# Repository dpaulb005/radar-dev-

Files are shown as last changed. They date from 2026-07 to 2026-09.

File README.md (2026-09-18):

# radar-dev — a horn-fed 2.4 GHz FMCW radar that tracks a small drone

A frequency-modulated continuous-wave radar in the MIT "coffee-can" tradition,
fed by pyramidal horns cut from copper sheet, that finds a 25 g quadcopter at
3–10 m indoors by its reflection alone. The drone carries no beacon and no
transponder: it is a target.

One transmit horn, one receive horn. It measures **range and radial velocity**.

```
 ESP32 steps an ADF4351 PLL 2400 → 2483.5 MHz in 64 steps / 6.4 ms
   → 3 dB pad → PA → splitter ─┬─► TX horn ─── echo off the drone ──► RX horn
                               └─► mixer LO ◄──────── LNA ◄── band-pass ◄──┘
 mixer IF = beat tone, pitch ∝ range (870 Hz at 10 m)
   → video amp (TL072, 61 dB) → USB audio interface
   → laptop: range FFT · Doppler FFT · CFAR → Kalman tracker → console
```

| | |
|---|---|
| sweep | 2400–2483.5 MHz (83.5 MHz), 6.4 ms up-chirp, 7.4 ms PRI |
| range cell | 1.80 m, 0.04 m mean accuracy on the stepped waveform |
| velocity | 0.13 m/s resolution, unambiguous to ±4.15 m/s |
| antenna | optimum pyramidal horn, 264 × 193 mm aperture, 13.4 dBi, ~34° × 36° beam |
| drone echo at 10 m | −77 dBm (0.01 m² RCS), 72 dB above the leakage-limited floor after 64 chirps |

## What is here

This branch holds the design deliverables only. Everything used to produce them
(firmware, signal processing, the model generators, the full design notes) is
on the [`dev`](https://github.com/dpaulb005/radar-dev-/tree/dev) branch.

| | what | status |
|---|---|---|
| [`BOM_Radar_Build.xlsx`](BOM_Radar_Build.xlsx) | bill of materials: every part, its price and where to buy it | priced Sept 2026 |
| [`antenna/`](antenna/) | the horn: design dimensions and the HFSS simulation results | **simulation in progress**, results and the LaTeX report land in `antenna/results/` |
| [`3d/`](3d/) | 3D models of the radar bench and the drone: open `radar-bench.html` or `drone.html` in a browser, plus rendered views | done |
| [`breadboard/`](breadboard/) | the baseband board: schematics, hole-by-hole wiring, 17 build steps, the pick list, and the Multisim files for each block | **bench test pending**, Multisim circuits to be added |

## Where it stands

- **Designed and documented:** the RF chain, the horn, the video amplifier,
  the frame, the drone's 915 MHz control link.
- **Parts ordered:** everything in the bill of materials is on its way.
- **Simulation in progress:** the horn in HFSS (probe match, gain, patterns)
  and each breadboard block in Multisim. The ngspice reference numbers each
  block should reproduce are in `breadboard/multisim/README.md`.
- **Next, while the RF parts ship:** cut the three horns and wire the
  breadboard.
- **Not built:** anything RF. Nothing here has been on a bench yet.

Azimuth from a second receiver is designed and tested in software but not built;
the BOM lists what it would add so nothing gets bought twice.

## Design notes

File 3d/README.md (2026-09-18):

# 3d — the two models

Two self-contained Three.js pages. Open either in a browser (each loads
three.js from a CDN, so it needs an internet connection the first time).
Between them they draw every part in `BOM_Radar_Build.xlsx` as a real object.

| page | what it is |
|---|---|
| [`radar-bench.html`](radar-bench.html) | the radar: the three-horn frame, the RF chain, the 830-point breadboard wired hole by hole, the USB interface and laptop, the optional turntable, and the room with the drone 3 m out. A second button adds the azimuth upgrade, so the model can show what would change. |
| [`drone.html`](drone.html) | the target: a Seeed ESP-FLY with the 915 MHz receiver fitted, every part, every pad, every wire, and what each one weighs. |

Both share the same conventions: click a panel row and the camera flies to the
part and it pulses; hover any object for its name; hover a pin or pad for its
net; click an object and its panel row scrolls into view.

## Rendered views

Still images from each model, in [`renders/`](renders/).

| [`renders/radar-bench/`](renders/radar-bench/) | |
|---|---|
| [`room.png`](renders/radar-bench/room.png) | the room, drone 3 m out |
| [`desk.png`](renders/radar-bench/desk.png) | the desk |
| [`bench.png`](renders/radar-bench/bench.png) | the bench and horn frame |
| [`plan.png`](renders/radar-bench/plan.png) | plan view |
| [`breadboard.png`](renders/radar-bench/breadboard.png) | the breadboard, wired |
| [`stage2.png`](renders/radar-bench/stage2.png) | with the azimuth upgrade |

| [`renders/drone/`](renders/drone/) | |
|---|---|
| [`overview.png`](renders/drone/overview.png) | the ESP-FLY as fitted |
| [`top.png`](renders/drone/top.png) | from above |
| [`underside.png`](renders/drone/underside.png) | from below |
| [`receiver.png`](renders/drone/receiver.png) | the 915 MHz receiver fitted |
| [`exploded.png`](renders/drone/exploded.png) | exploded |

The models are generated and geometry-checked by scripts on the `dev` branch
(`hardware/3d/`); edit there, not here.

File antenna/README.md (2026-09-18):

# antenna — the horn, and its HFSS simulation

Optimum pyramidal horn at 2.45 GHz on a WR-340 waveguide section with a coax
probe feed. Three are cut from copper sheet in one session: TX, RX, and a
spare for the azimuth upgrade.

## Design dimensions

Solved by `antenna/horn.py` on the `dev` branch; this is what the HFSS model
must reproduce before its output means anything.

| | |
|---|---|
| design frequency | 2.45 GHz (λ₀ = 122.4 mm) |
| feed guide a × b | 86.4 × 43.2 mm (WR-340) |
| TE10 cutoff | 1.735 GHz, single-mode to 3.47 GHz |
| guide wavelength λg | 173.3 mm |
| coax probe | ~29 mm long, 43 mm from the shorted back wall |
| aperture a1 (H-plane) | 263.8 mm |
| aperture b1 (E-plane) | 193.1 mm |
| axial flare length | 91.5 mm (pe = ph, geometry closes) |
| predicted gain | 13.4 dBi |
| aperture bound 4πA/λ² | 16.3 dBi |
| aperture efficiency | 51 % (textbook optimum) |
| beamwidths | ~34° E-plane, ~36° H-plane |

Accept the simulation if: gain 12.5–14 dBi at 2.45 GHz, S11 below −10 dB across
2400–2483.5 MHz after the probe sweep, beamwidths within a few degrees of the
above, and gain below the aperture bound. A converged solution of a wrong model
is still converged.

## Results

The HFSS output goes in [`results/`](results/), and the write-up is a LaTeX
report built from it once the measurements are in: S11 across the band, the
E- and H-plane cuts, the probe sweep, and the final table against the accept-if
line above. Until then the design numbers above are the only antenna data here.

The study notes the procedure was written from (an antenna-basics primer and
the twelve-step HFSS walkthrough for this horn) are on the `dev` branch under
[`antenna/hfss/`](https://github.com/dpaulb005/radar-dev-/tree/dev/antenna/hfss).

## What the solver is for

The gain and beamwidths have a closed form and the table above already has
them. What HFSS is genuinely for is the **probe match**, which does not: sweep
probe depth and backshort distance, and arrive at the bench already close.

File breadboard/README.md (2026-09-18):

# breadboard — the baseband board

Everything between the mixer's IF port and the USB audio interface, plus the
power entry and the ESP32 / ADF4351 harness, on one 830-point breadboard:
video amplifier, half-rail reference, 12 V input, sync divider.

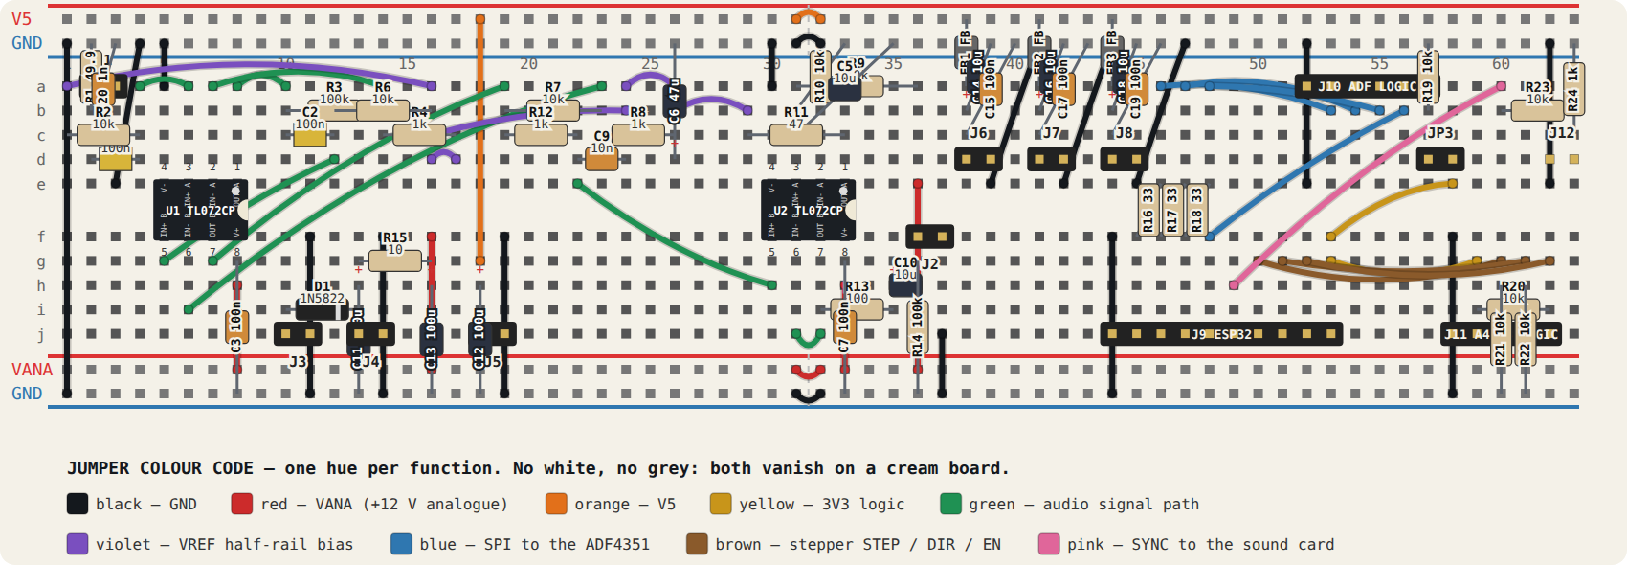
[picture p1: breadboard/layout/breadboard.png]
the finished board


| folder | what |
|---|---|
| [`schematics/`](schematics/) | three KiCad sheets and their PNGs: `radar_flow` (how everything connects, in signal order), `radar_breadboard` (the board at component level), `radar_multisim` (each test block drawn alone with its sources and expected readings) |
| [`layout/`](layout/) | the board: [`WIRING.md`](layout/WIRING.md) gives every part's lead → hole, every jumper and every net, verified against the schematic netlist; [`breadboard.html`](layout/breadboard.html) is the interactive version (hover or click any part, wire, net or hole) |
| [`assembly/`](assembly/) | [`ASSEMBLY.md`](assembly/ASSEMBLY.md): the build in 17 pictured steps, each ending with a check |
| [`parts/`](parts/) | [`PARTS.md`](parts/PARTS.md), the stockroom pick list (every value, how many, what may be substituted), and [`MODULES.md`](parts/MODULES.md), the pinouts of the TL072, ESP32, A4988, ADF4351 and the interface |
| [`multisim/`](multisim/) | the SPICE netlists for each block, ready for File ▸ Open in Multisim, with the reading each should give |

## Multisim status

The netlists in `multisim/import/` open directly in Multisim and each header
says which analysis to run and what number to expect. The saved Multisim
projects (`.ms14`) and the bench measurements go in `multisim/` beside them (the `.sub` black-box blocks for Route B are in `multisim/blocks/`)
once each block has been run.

| block | file | expect |
|---|---|---|
| 1 video amplifier | `import/01_video_amp.cir` | 54.5 dB at 1 kHz; 0.5 mVpk in → 0.27 Vpk out |
| 2 half-rail reference | `import/02_vref_bias.cir` | vref 5.58–5.70 V |
| 3 12 V input | `import/03_power_in.cir` | vana 11.58 V |
| 4 reverse polarity | `import/04_power_reverse.cir` | vprot −0.11 mV |
| 5 sync divider | `import/05_sync_div.cir` | sync 283 mV |
| 6 IF input network | `import/06_if_input.cir` | −6.7 dB at 417 Hz, −57.7 dB at 2.44 GHz |

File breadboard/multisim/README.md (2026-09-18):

# Multisim — the radar's baseband blocks, ready to open

Multisim cannot open a KiCad schematic, but it takes SPICE two ways
([NI: Importing a SPICE Netlist](https://knowledge.ni.com/KnowledgeArticleDetails?id=kA03q000000YG0ACAW&l=en-US)).
Pick by what you want on the sheet.

## Route A — File ▸ Open a netlist, get a drawn schematic  ← start here

`import/*.cir` are flat netlists written for this: **no `.control` block, no
B-sources, no `.include`, everything in one file.** (The ngspice decks they were
derived from live in `hardware/spice/` on the [`dev` branch](https://github.com/dpaulb005/radar-dev-/tree/dev/hardware/spice);
those contain `.control` blocks Multisim rejects, so they are not here.)

1. **File ▸ Open**, set the file-type dropdown to **SPICE netlist files
   (\*.cir)**, pick the file. Multisim converts the netlist into a drawn
   schematic; passives arrive as virtual parts.
2. Multisim ignores the `.ac` / `.tran` / `.op` lines at the bottom. Set the
   analysis yourself in **Simulate ▸ Analyses and Simulation** — each file's
   header comment says which analysis and what number to expect.
3. Probe with **Place ▸ Probe** or a virtual instrument, then **Run**.

| file | what it is | run | expect |
|---|---|---|---|
| `import/01_video_amp.cir` | the whole video amp, full gain, 0.5 mVpk 1 kHz in | AC 1 Hz–100 kHz; Transient 40–60 ms | **54.5 dB** at 1 kHz, 48.7 at 159 Hz, 50.6 at 15.9 kHz; **0.27 Vpk** at `audio` |
| `import/02_vref_bias.cir` | buffered half rail, 150 kHz ripple on VANA | DC Operating Point | `vdiv` **5.70 V**, `vref` **5.58 V** |
| `import/03_power_in.cir` | 12 V, D1, R15/C13 | DC OP; Transient 200–300 µs | `vprot` **11.68 V**, `vana` **11.58 V** |
| `import/04_power_reverse.cir` | −12 V applied | DC OP | `vprot` **−0.11 mV** |
| `import/05_sync_div.cir` | GPIO25 → 10k/1k → sound card | Transient 0–60 ms | `sync` **283 mV**, `sc` +274 mV falling to **−100 mV** on retrace |
| `import/06_if_input.cir` | 49.9 Ω + 1 nF at the mixer IF | AC 10 Hz–10 GHz | **−6.7 dB** at 417 Hz, **−57.7 dB** at 2.44 GHz |

Every one of those numbers was produced by running the file itself in ngspice.

The op-amp in files 01 and 02 is a generic macro (Aol 100 dB, GBW 3 MHz,
diode output clamps) defined at the top of the file. For a better answer,
delete that subcircuit after import and drop in Multisim's own **TL072CP**
from Place ▸ Component ▸ Group **Analog** ▸ Family **OPAMP**.

## Route B — Arbitrary SPICE Block, one black box on your own sheet (the `.sub` files in `blocks/`)

Use this when you want Multisim's sources and instruments around a block, or
for `fmcw_beat.sub`, which needs a real VCO in front of it and so cannot be a
plain netlist. The `.sub` files are plain SPICE 3 (R, C, D, E incl. POLY, T,
V, X) — no B-sources, no ngspice syntax — and each has been run through
ngspice via the `_h_*.cir` harnesses to prove it parses and gives the
test-card numbers.

| file | subcircuit · pins | stands for |
|---|---|---|
| `blocks/opamp_tl072.sub` | `TL072X inp inn vcc vee out` | generic TL072 (Aol 100 dB, GBW 3 MHz, clamps 1.5 V inside the rails). Used by the two blocks below; in Multisim you can instead build the amp from library TL072CPs — see the KiCad sheet |
| `blocks/video_amp.sub` | `VIDEO_AMP if audio vana vref gnd` | test card 1 — the whole video amplifier, full gain (R4 1k, R7 10k) |
| `blocks/vref_bias.sub` | `VREF_BIAS vana vref gnd` | test card 2 |
| `blocks/power_in.sub` | `POWER_IN vin vprot vana gnd` | test card 3 |
| `blocks/sync_div.sub` | `SYNC_DIV gpio sync sc gnd` | test card 4, includes the sound card's coupling |
| `blocks/fmcw_beat.sub` | `FMCW_BEAT tx leak_en beat gnd` | test card 6 — delay lines, gated leakage, POLY multiplier (the mixer), the amp's filters |

### Placing a block

1. Place › Component › Group **Basic** › Family **BASIC_VIRTUAL** (older
   versions: **Misc**) › **ARBITRARY_SPICE_BLOCK**.
2. Double-click it › **Value** tab › paste the contents of the `.sub` file
   (for `video_amp.sub` and `vref_bias.sub` paste `opamp_tl072.sub` first,
   then the block — the `.include` line does not resolve inside Multisim, so
   delete it and paste the op-amp subcircuit above the block's `.subckt`).
3. Set the block's **pin names** to the `.subckt` pin list, in order.
4. Wire the external parts below to those pins.

### Per block: what to add outside, what to run, what you should read

#### 1 · VIDEO_AMP
- **Outside:** `AC_VOLTAGE` V_IF → **50 Ω resistor** → `if`. `DC_POWER` 11.4 V → `vana`; `DC_POWER` 5.7 V → `vref` (or the VREF_BIAS block's output). 10 kΩ from `audio` to ground (sound-card load). Ground → `gnd`.
- **Run:** AC Analysis 1 Hz – 100 kHz, output `V(audio)`; Transient 40–60 ms with V_IF = **0.5 mVpk 1 kHz**.
- **Read:** 54.5 dB at 1 kHz, ~48.7 dB at 159 Hz (−6), ~50.7 dB at 15.9 kHz (−4). Transient: 0.5 mVpk → **~0.27 Vpk** at `audio`. 10 mVpk clips at ±4.2 V — that is the full-gain block; for the first-power-up gain edit `R4 am vref 4.7k` and `R7 bout bm 0.001` in the pasted text (then 10 mVpk → 107 mVpk).
- **Radar test:** two AC_VOLTAGE in series: 8 mVpk 12.5 Hz + 40 µVpk 417 Hz → Fourier on `audio`: ~27 mV at 12.5 Hz, ~19 mV at 417 Hz.

#### 2 · VREF_BIAS
- **Outside:** `DC_POWER` 11.4 V → `vana`; 2.2 kΩ from `vref` to ground.
- **Run:** DC Operating Point; then AC/transient with 100 mVpk 150 kHz added to `vana`.
- **Read:** `vref` = **5.58–5.70 V** (5.58 with the generic op-amp's 100 Ω output; 5.70 with TL072CP), ripple < 1 µV.

#### 3 · POWER_IN
- **Outside:** `DC_POWER` 12 V → `vin`; 60 Ω from `vprot` to ground (the buck's load), 1.1 kΩ from `vana` to ground (the op-amps).
- **Run:** DC OP; transient with 100 mVpk 150 kHz on `vin`; DC OP again with **−12 V**.
- **Read:** `vprot` **11.68 V**, `vana` **11.58 V**; ripple on `vana` ~4 mVpp; reversed: `vprot` ≈ −0.1 mV.

#### 4 · SYNC_DIV
- **Outside:** `PULSE_VOLTAGE` 0 → 3.3 V, pulse width 6.4 ms, period 7.4 ms, 10 ns edges → `gpio`.
- **Run:** Transient 0–60 ms, probe `sync` and `sc`.
- **Read:** `sync` **283 mV** high / 0 low; `sc` **+201 mV** plateau that droops, **−100 mV** retrace pulse. (That is what the laptop sees; the software detects edges, not levels.)

#### 5 · FMCW_BEAT — the radar
- **Outside:** `PIECEWISE_LINEAR_VOLTAGE` (0 V at 0, 1 V at 6.4 ms, repeat) → `VOLTAGE_CONTROLLED_SINE_WAVE` (0 V → 1 MHz, 1 V → 5 MHz, 1 Vpk) → `tx`. `DC_POWER` **0 V** → `leak_en` (1 V to switch the leakage path on).
- **Run:** Transient, TMAX **10 ns**, stop 12.8 ms. Fourier Analysis on `beat` over the **second chirp** (6.72–12.8 ms), Hanning.
- **Read:** peak at **≈ 415 Hz, ~3 mV**. Change T1's `TD=667n` to `333n` → 208 Hz; `1.33u` → 833 Hz. `leak_en` = 1 V: the 417 Hz line stays, the floor near DC rises — the reason the software subtracts chirp-to-chirp.
- Why it is scaled: the beat is `B × TD / T` and the carrier cancels. Real radar B = 40 MHz, TD = 66.7 ns at 10 m; here B = 4 MHz, TD = 667 ns — same 417 Hz, and Multisim can step at 10 ns instead of 20 ps.

## Not importable, by nature
Everything to the right of the mixer's IF port — ADF4351, SPF5189Z amplifiers, splitter, mixer at 2.44 GHz, the horns. No models exist at that frequency in Multisim; those stages are measured on the bench (`docs/radar-hardware.md` on the `dev` branch, checkpoints 7–8).

## Reproduce the reference numbers
```
cd breadboard/multisim
ngspice -b import/03_power_in.cir    # the import files run as-is in ngspice too
```
The `_h_*.cir` harnesses that wrap each `.sub` with its sources are on the
[`dev` branch](https://github.com/dpaulb005/radar-dev-/tree/dev/hardware/spice/multisim).

## If Multisim refuses a file
- **"Unrecognized command" / it stops at a line** — you opened an ngspice deck
  (from the `dev` branch) rather than one of the files in `import/`. They contain `.control`.
- **Nothing appears after File ▸ Open** — the file-type dropdown was still on
  Multisim files; it must say SPICE netlist (\*.cir).
- **The subcircuit did not come through** — paste it into an Arbitrary SPICE
  Block instead (route B), or rebuild that stage from library parts.

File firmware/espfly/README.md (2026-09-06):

# firmware/espfly — what runs on the ESP-FLY

**Current plan: nothing from here.** The drone is flown from the phone on
the stock ESP-Drone firmware (AP on channel 1) — see `docs/drone-software.md`.

This directory is the **fallback**: esp-fc configuration for a 915 MHz
ELRS/CRSF receiver, if the phone link and the radar turn out not to coexist:

- `espfly-915.cli` — the esp-fc CLI settings (receiver pins, serial RX,
  failsafe). Paste into the Configurator's CLI tab.

Step-by-step: [`../../docs/drone-hardware.md`](../../docs/drone-hardware.md)
(receiver swap, antenna, radio) and
[`../../docs/drone-software.md`](../../docs/drone-software.md) (ELRS flash,
EdgeTX model, esp-fc Ports/Receiver/Modes, failsafe test, first flights).

Building esp-fc yourself (only if you are not using the ESP-FLY's supplied
binary): PlatformIO, env `esp32s3` (`pio run -e esp32s3 -t upload`). The
receiver-related changes are all runtime settings; no source edits.

Not here any more, on purpose: `drone_beacon`, MAC filtering, the AP/FTM
patches — those belonged to the passive RF tracker.

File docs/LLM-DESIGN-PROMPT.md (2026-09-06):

# Design-prompt pack — horn-fed FMCW radar + phone-flown ESP-FLY

A set of prompts to hand to an LLM (or a design partner) to produce the
detailed engineering for this project. Every number below is fixed by the
work already done in this repo; the prompts ask the model to design *to*
them, not to re-derive or "improve" them.

**How to use.** Paste **§0 (shared context)** first, then one of the task
prompts §1–§5. Each task prompt is independent and ends with the deliverable
format it expects. Run §5 (band plan) and §1 (schematic) before §2 (PCB);
run §3 (antenna tests) any time after the horn geometry is accepted.

---

## §0 · Shared context — paste this before every task prompt

```text
You are the RF / systems engineer for a hobby-scale but rigorous project:
an MIT RES.LL-003 "coffee-can" FMCW radar rebuilt with custom pyramidal
horns, tracking a 25 g quadcopter (Seeed ESP-FLY: XIAO ESP32-S3, ESP-Drone
firmware, flown from a phone over the drone's own WiFi access point) at
3-10 m indoors. Range + Doppler first, azimuth by mechanically scanning the
horn pair, elevation later from a second stacked receive horn.

FIXED DECISIONS (design to these; do not reopen them):
- Radar architecture, in MIT's signal order:
    sweep generator -> 3 dB attenuator -> PA -> 2-way splitter
      -> (TX horn) and (mixer LO);
    RX horn -> LNA -> mixer RF; mixer IF -> video amp -> sound card.
- Sweep generator: ADF4351 PLL board (25 MHz TCXO) stepped over SPI by an
  ESP32, NOT an analog VCO (the MIT ZX95-2536C+ is non-catalog).
  64 steps x 100 us = 6.4 ms up-chirp, 1 ms retrace -> PRI 7.4 ms.
- Band: the drone's WiFi AP is on 802.11 channel 1 (2401-2423 MHz).
  Radar sweep 2440.0 -> 2480.0 MHz (40 MHz). The sweep never leaves
  2400-2480 MHz (the top 3.5 MHz of the US ISM band is left as an emission margin). 2360-2395 MHz is NOT usable (AMT/medical).
- Parts on hand / chosen: Mini-Circuits ZX05-43MH-S+ mixer (level 13),
  2x SPF5189Z LNA modules (PA role and LNA role), 800-2500 MHz 2-way SMA
  splitter, SMA 3 dB attenuator, Behringer UCA202 USB sound card
  (44.1 kHz, 16-bit, L = beat, R = sync), ESP32-WROOM-32 devkit,
  TL072 video amp on 12 V, NEMA-17 + A4988 turntable, 12 V 3 A supply
  with LM2596 5 V buck.
- Design levels at 2.44 GHz: ADF4351 +5 dBm -> att +2 -> PA +14 ->
  splitter +10.5 dBm to TX horn and +10.5 dBm to LO. TX horn 13.4 dBi
  -> +23 dBm EIRP. Drone RCS assumed 0.01 m^2 -> echo -74 dBm at 10 m
  at the RX horn, SNR 71 dB after 64-chirp integration. Beat frequency
  f_b = 2*B*R/(c*T_up) = 417 Hz at 10 m; IF band of interest 0-2.6 kHz;
  TX->RX leakage appears as a ~26 Hz tone ~40 dB above the drone echo.
- Horn (per horn, three built): optimum pyramidal horn on a WR-340 guide.
  Aperture 263.8 x 193.1 mm, throat 86.4 x 43.2 mm, flare 91.5 mm axial,
  guide section 115 mm, SMA probe through the broad wall 43.7 mm from
  the shorted back wall, probe 28 mm long. Predicted: 13.4 dBi, -3 dB
  beamwidths 34 deg (E) x 36 deg (H), pe == ph satisfied, 51 % aperture
  efficiency. 0.021" copper, soldered seams. TX and RX horns 290 mm
  centre-to-centre, E-plane (193 mm side) vertical on both.
- Scanning: 12 deg beam steps over ~100 deg, 64 chirps per dwell (0.47 s),
  amplitude-weighted centroid across beams -> 2.5 deg azimuth RMS.
  Stage 3: second RX horn 193 mm directly below the first (1.57 lambda,
  unambiguous +/-18.5 deg), second LNA + mixer + video channel, 4-input
  audio interface on one clock (Behringer UMC404HD).
- Drone: stock ESP-FLY hardware. ESP-Drone firmware rebuilt with
  CONFIG_WIFI_CHANNEL=1. The RadioMaster RP1 V2 (ELRS 2.4 GHz) receiver
  is REMOVED so no FHSS link hops through the sweep. No 5 GHz, no
  Bluetooth, no 915 MHz unless the coexistence test fails.
- Interference budget at the drone's receiver, 5 m, beam on it: radar
  -31 dBm raw, ~ -55 dBm after adjacent-channel rejection; phone signal
  ~ -35 dBm; SIR ~ 20 dB (802.11 needs 5-10 dB).
- Interference INTO the radar: the drone's AP (+20 dBm, always in the
  beam) reaches the LNA at -21 dBm at 5 m and the mixer at -9 dBm --
  ~8 dB from compression with WiFi peaks. Mitigations that are part of
  the design: drone AP power set to +8 dBm in firmware; a 2400-2500 MHz
  band-pass filter between RX horn and LNA (the horn and the SPF5189Z
  are wideband); the operator with the phone stands behind the horns.
- Processing on the laptop (Python, exists): sync-edge segmentation ->
  per-chirp range FFT (3.75 m cells, parabolic peak interpolation) ->
  Doppler FFT across chirps (axis from the measured PRI, +/-4.2 m/s) ->
  CA-CFAR (linear power, guard 4, train 6, 15 dB, peak-picked) ->
  beam centroid -> Kalman tracker -> web console.

HARD CONSTRAINTS:
- Never propose a sweep outside 2400-2483.5 MHz or overlapping 2401-2423.
- Never propose moving the phone link to 5 GHz/Bluetooth (the S3 cannot)
  or to the T8L radio (2.4 GHz only, no module bay).
- Keep every RF path 50 ohm; SMA everywhere; no bias-tee assumptions
  (the SPF5189Z and ADF4351 boards have their own 5 V pins).
- State every assumption you add, and mark which numbers are computed
  versus assumed. Where a value depends on a datasheet figure at
  2.4 GHz (SPF5189Z gain, mixer conversion loss), quote the figure and
  its source line.
- Prefer parts in stock at Mini-Circuits, Mouser, Digi-Key, LCSC, or Amazon
  in September 2026; say so per part.
```

---

## §1 · Task prompt — system design and full circuit diagram

```text
TASK: Produce the complete electrical design of the radar as built from
the coax modules in §0, ready for a person to wire on a plywood board and
a breadboard, and produce the circuit diagram.

Deliver, in this order:

1. BLOCK DIAGRAM with every signal level (dBm) at every port at 2.44 GHz,
   in MIT order. Include the ESP32's three control lines (SPI to the
   ADF4351, SYNC to the sound card's right channel, STEP/DIR/EN to the
   A4988). Show the two horns and the drone as the RF "load".

2. SCHEMATIC (text form, KiCad-importable if you can: a netlist or a
   KiCad 8 .kicad_sch S-expression; otherwise an unambiguous ASCII
   schematic per sheet) with these sheets:
   a. RF chain: SMA-to-SMA interconnects between modules, including
      the 2400-2500 MHz band-pass filter between the RX horn and the
      LNA, module DC
      feeds (5 V, 100 nF + 10 uF at each module), the 3 dB pad, the
      splitter, the mixer's LO/RF/IF ports labeled.
   b. Video amplifier: TL072 on a single 12 V rail with a 6 V mid-rail
      bias. Stage A non-inverting gain 101 with an input high-pass at
      160 Hz (100 nF / 10 k); stage B gain 11 with a second 160 Hz
      high-pass; then a 15.9 kHz RC low-pass (1 k / 10 nF) and a 10 uF
      AC-coupled output into the sound card's left channel. Justify each
      corner: the two high-passes are there to keep the ~26 Hz leakage
      tone from saturating the gain; the low-pass is anti-alias for
      44.1 kHz. State the leakage and drone-echo amplitudes at the
      output (targets: ~200 mV and ~20 mV) and show neither clips a
      line input.
   c. Sync: ESP32 GPIO25 -> 10 k series -> sound card right tip, 1 k to
      ground (0.3 V square wave, high during the up-chirp).
   d. Control: ESP32 devkit pinout (SCK 18, MOSI 23, LE 5, LD 19,
      SYNC 25, STEP 26, DIR 27, EN 14), A4988 with VMOT 12 V, 1/16
      microstep straps, VREF for ~0.8 A, 100 uF at VMOT.
   e. Power tree: 12 V 3 A input -> LM2596 5.0 V (ADF4351 board, both
      SPF5189Z modules, ESP32 VIN) ; 12 V direct to TL072 and A4988;
      star ground at a terminal block; note the stepper's wires must be
      routed away from the IF/breadboard side.

3. BILL OF MATERIALS for the schematic, with one vendor and stock status
   per line, and a total.

4. BRING-UP CHECKLIST in order, with an expected measurement at each
   step (e.g. "5.00 V on the SPF5189Z pin", "LO drive +10.5 +/-2 dBm",
   "leakage tone with a strong ~135 Hz component on the left channel").
   The first end-to-end test is the MIT one: walk toward the horns from
   5 m and see range decrease with negative velocity.

5. A list of every place your design deviates from the MIT RES.LL-003
   schematic and why (e.g. PLL instead of VCO+XR-2206, TL072 instead of
   LT1214, stepped sweep).

Do not design a PCB here; that is a separate task. Do not change any
fixed decision in §0.
```

---

## §2 · Task prompt — PCB design for the MIT-architecture radar (v2)

```text
TASK: Design a single printed circuit board that replaces the coax-module
build of §1 with an integrated "MIT radar on a board", keeping the same
architecture, levels and band. This is the v2 board built only after the
coax v1 has been proven (v1 is the reference; the PCB must match its
measured performance, not exceed it on paper).

Requirements:

ARCHITECTURE (unchanged): ADF4351 -> pad -> PA -> Wilkinson splitter ->
{TX SMA, mixer LO}; RX SMA -> LNA -> mixer RF; IF -> video amp -> audio
out. ESP32 module on board for sweep, sync and stepper. External: the
two horns (SMA), the sound card (3.5 mm or RCA), 12 V in, USB.

PART SELECTION (propose, with datasheet figures at 2.44 GHz and stock):
- Synthesiser: ADF4351 chip with a 25 MHz TCXO, or justify keeping the
  bought ADF4351 board as a daughterboard on pin headers.
- PA and LNA: SPF5189Z bare parts (Qorvo) with their reference matching
  networks, or an equivalent in stock; state gain, NF, P1dB at 2.44 GHz.
- Mixer: a surface-mount double-balanced mixer covering 2.4-2.5 GHz
  with LO drive matching the +10.5 dBm available (or add a driver and
  say so). If nothing SMT is available with adequate stock, keep the
  ZX05-43MH-S+ as a bolt-on and design the board around three SMA
  jumpers to it; say which you chose and why.
- Splitter: printed Wilkinson at 2.44 GHz on the chosen stackup, with
  the isolation resistor value and the quarter-wave line dimensions.
- Video amp: as in §1 (TL072 or a rail-to-rail equivalent), single
  12 V rail, same corners.
- ESP32-WROOM-32E module (or -S3), USB-UART, 3.3 V LDO, A4988 socket.

STACKUP AND RF LAYOUT:
- 4-layer FR-4 (or 2-layer with a stated controlled-impedance core if
  you argue it is adequate at 2.44 GHz); give the stackup, dielectric
  (Er, thickness), and the 50 ohm CPWG or microstrip width/gap for it.
- Via fencing along RF traces, ground stitching pitch, keep-outs.
- Partition: RF (TX side / RX side separated, LO isolation), baseband
  (video amp far from the PA and the stepper driver), digital (ESP32,
  USB) with a single ground plane and a stated star point.
- SMA edge-launch footprints for TX, RX; test points or 0 ohm links at
  every RF stage so each block can be measured alone (LO drive, PA out,
  LNA in/out, IF).
- DC: per-module 100 nF + 10 uF, ferrite on each 5 V RF feed, LM2596 or
  an equivalent buck with its inductor away from the RF section.
- ESD and reverse-polarity protection on 12 V in.

DELIVERABLES:
1. Schematic per sheet (KiCad 8 S-expression preferred; else netlist +
   ASCII), BOM with LCSC/Mouser part numbers and stock.
2. Layout plan: board outline (target <= 100 x 80 mm), placement
   drawing, layer assignments, RF trace routing description, DRC rules
   (min trace/space, via size, annular ring, solder mask expansion for
   the RF pads).
3. A test-point list mapping every §1 bring-up measurement to a TP name.
4. A comparison table: v1 coax build vs v2 PCB for cost, size, expected
   gain/loss per stage, expected TX-RX isolation, and the risks the PCB
   adds (matching network tolerance, Wilkinson resistor placement, LO
   leakage through the plane).
5. A one-page "what must be equal to v1" acceptance list: LO drive
   within 1 dB, PA out within 1 dB, LNA gain within 1 dB, leakage tone
   level within 3 dB, walking-person test identical.

Do not add features (no on-board ADC replacing the sound card, no second
receive channel) in this revision. Stage 3 (second RX channel) is a
later board.
```

---

## §3 · Task prompt — horn antenna test and acceptance requirements

```text
TASK: Write the verification and acceptance test plan for the three
hand-built pyramidal horns in §0, using hobby-grade instruments: a
NanoVNA (or LibreVNA), an RTL-SDR or the radar's own receive chain as a
power detector, a tape measure, a turntable, and optionally an openEMS
or HFSS model for correlation. The plan must let a builder decide
PASS / FAIL for each horn and diagnose the common failures.

Cover, with numeric acceptance limits and the procedure to measure each:

1. MECHANICAL INSPECTION
   - Aperture 263.8 x 193.1 mm (+/- 2 mm), throat 86.4 x 43.2 mm
     (+/- 0.5 mm), flare axial length 91.5 mm (+/- 1 mm), guide 115 mm,
     probe centred on the broad wall at 43.7 mm (+/- 0.5 mm) from the
     back wall, probe length 28 mm (+/- 0.5 mm), perpendicular to the
     wall.
   - Seam continuity: < 0.5 ohm between any two panels at both ends;
     visual: no gaps > 0.2 mm on any seam (why: a slot radiates).
   - Flatness / squareness of the mouth: diagonals equal within 2 mm.

2. RETURN LOSS (S11), NanoVNA at the SMA
   - Acceptance: S11 <= -10 dB over 2400-2483.5 MHz; note the
     minimum and its frequency. Target from the design: better than
     -15 dB at 2440-2480.
   - Procedure: calibrate at the cable end (SOL), horn pointed at open
     space > 2 m from any object, sweep 2.2-2.7 GHz, 201 points.
   - Diagnosis table: resonance too low/high -> probe length; broad
     mismatch -> probe position or a leaking seam; ripple -> reflection
     from nearby objects.
   - Probe tuning procedure: trim in 0.5 mm steps, re-measure, stop at
     the minimum S11 across the sweep band (not at one frequency).

3. TX-RX ISOLATION, the pair at 290 mm centre-to-centre, same
   polarisation, NanoVNA S21
   - Acceptance: S21 <= -35 dB across the sweep band (the radar's
     leakage budget in §0 assumes 35 dB). Record the value; it sets the
     leakage tone level.
   - Improvement steps if it fails: foil septum between the guide
     sections, absorber behind, re-check seams on the facing walls.

4. GAIN (two-antenna method with the two identical horns, Friis)
   - Acceptance: 13.4 dBi +/- 1.5 dB at 2440 and 2480 MHz.
   - Procedure: horns boresighted at d >= 2*D^2/lambda = 1.13 m (use
     3 m), measure S21 with the NanoVNA, compute G = (S21_dB - FSPL)/2
     with FSPL at each frequency; state the far-field justification and
     the reflection-free zone needed (Fresnel radius at 3 m).
   - Three-antenna method with the third horn to bound the error.

5. RADIATION PATTERN (E- and H-plane cuts on the turntable)
   - Acceptance: -3 dB beamwidth 34 +/- 4 deg (E), 36 +/- 4 deg (H);
     first sidelobe <= -12 dB; pattern symmetric within 2 deg (asymmetry
     -> probe off-centre or a seam gap).
   - Procedure: the radar's own turntable steps the horn under test in
     5 deg increments (2 deg near boresight) against a fixed illuminating
     horn 3 m away, receive power read as S21 or with the RTL-SDR; two
     cuts (rotate the horn 90 deg for the second plane).
   - Cross-polarisation at boresight: <= -20 dB (rotate the fixed horn
     90 deg).

6. LEAKAGE / SEAM RADIATION
   - Probe the outside of every seam with a small loop on the NanoVNA
     port 2 (or the RTL-SDR) while port 1 drives the horn: any seam
     reading within 20 dB of the aperture level fails.

7. CORRELATION TO SIMULATION (if a model exists)
   - Compare measured S11, gain, beamwidths to the openEMS/HFSS results
     from antenna.md's five-study methodology; acceptance: gain within
     1.5 dB, beamwidths within 4 deg, S11 minimum within 40 MHz.

8. STACKED-PAIR CHECK for stage 3 (two RX horns 193 mm vertical
   spacing, mouths touching)
   - Mutual coupling S21 <= -20 dB; boresight phase difference between
     the two channels measured against a target at 0 deg elevation
     (this is the fixed phase offset the software calibrates out);
     verify the phase slope sign by raising the target 0.5 m at 5 m.

Format: one section per test with Purpose / Setup / Procedure /
Acceptance / If it fails. End with a one-page acceptance sheet (table:
test, limit, horn 1, horn 2, horn 3, PASS/FAIL) to print and fill in.
Note which tests are needed before stage 1 (2, 3), before stage 2 (4, 5),
and before stage 3 (8).
```

---

## §4 · Task prompt — the drone build (phone-flown ESP-FLY as a radar target)

```text
TASK: Specify the drone side of the system: a stock Seeed ESP-FLY
(XIAO ESP32-S3, 25 g) flown from a phone, prepared as a non-cooperative
target for the radar. The drone runs nothing from this project; the work
is configuration, removal, and flight-envelope definition.

Deliver:

1. BUILD STATE
   - Stock ESP-FLY hardware. List what stays (XIAO ESP32-S3, FC board,
     IMU, 4 coreless motors, 1S battery, frame) and what is REMOVED:
     the RadioMaster RP1 V2 ELRS 2.4 GHz receiver and its antenna
     (reason: a bound ELRS link hops across 2400-2480 MHz, straight
     through the radar sweep, at 25-100 mW). Weight before/after.
   - Firmware: ESP-Drone (Seeed Co-Create_ESP-FLY fork) rebuilt with
     CONFIG_WIFI_CHANNEL=1 (default is 6, which sits inside the sweep).
     Give the menuconfig path, the sdkconfig line, and the flash
     command. Give the AP name/password settings and the app's default
     endpoint (192.168.43.42, UDP 2390) and how to verify the channel
     with a WiFi analyser app.
   - Explicitly: no 5 GHz (the S3 cannot), no Bluetooth control, no
     T8L, no 915 MHz unless the coexistence test in item 4 fails.

2. RADAR-TARGET CONSIDERATIONS
   - The link budget assumes RCS 0.01 m^2 with 71 dB SNR margin at
     10 m; state whether any change is warranted (it is not) and what
     the optional 30 mm copper-tape patch would do to RCS and weight.
   - Zero-Doppler behaviour: a perfectly stationary target is removed
     with the clutter; explain why a hovering quad is still seen (rotor
     micro-Doppler +/- ~1 kHz, body jitter) and what flight behaviour
     makes detection most reliable during first tests (slow drift
     0.3-1 m/s, not a locked hover).
   - Doppler window +/-4.2 m/s at PRI 7.4 ms: define the speed limit for
     tracked flight and what happens above it (velocity aliases; range
     does not).

3. FLIGHT ENVELOPE relative to the radar
   - Beams 34 x 36 deg; scan sector ~100 deg at 12 deg steps; horns at
     ~1.0 m height. Define the box: 3-10 m from the horns, horn height
     +/- 1.5 m, inside the sector minus one beam step each side (the
     centroid biases inward at the edges). Floor marks at 3, 5, 8 m on
     boresight and tape at the sector edges.
   - Where the operator stands (behind the horns: a person is a 0.5 m^2
     target 50x the drone).

4. COEXISTENCE TEST (the decision test)
   - Drone on the bench 1 m in front of the horns, in the beam, props
     off, phone connected. Ping the drone (100 pings at 100 ms) with:
     radar SWEEP 0; radar SWEEP 1 on 2440-2480; radar deliberately
     on 2400-2483.5 (crossing channel 1). Acceptance: ~0 % loss and
     unchanged RTT in the second case; visible loss in the third case
     proves the margin is real. Escalation: sweep from 2450 (30 MHz,
     5 m cell); then, only if still failing, the 915 MHz ELRS
     fallback (RadioMaster Pocket + Bandit Nano + Nano 915 RX, esp-fc
     with CRSF).

5. SAFETY
   - Indoor, props guarded, netted area for first radar-tracked flights;
     phone link failsafe behaviour of ESP-Drone on link loss (state what
     the firmware does and the test to confirm it); LiPo handling; the
     radar's +23 dBm EIRP is below Part 15 limits but keep the mouths
     away from people at < 1 m.

Format: numbered checklist with a checkpoint (an observable) after each
group, plus a one-page "before every session" card.
```

---

## §5 · Task prompt — signal and bandwidth layout (band plan, timing, link budget)

```text
TASK: Produce the definitive signal plan for the system: every emitter,
every band, every time constant, and the budgets that prove they
coexist. This document is the reference that §1-§4 must agree with.

Deliver:

1. SPECTRUM MAP of 2400-2483.5 MHz, to scale (ASCII or SVG), showing:
   WiFi channel 1 (2401-2423, centre 2412) = phone <-> drone AP;
   guard 2423-2440; radar sweep 2440.0-2483.5 (40 MHz, 64 steps of
   0.625 MHz); ESP-Drone's default channel 6 (2426-2448) marked as the
   collision to avoid; ELRS 2.4 GHz FHSS 2400-2480 marked as removed;
   the ISM edges; the unusable 2360-2395 MHz below the band.
   Alternative plan for channel 11 (2451-2473) with the sweep below
   (2400-2440) and why channel 1 is preferred (3.5 MHz more sweep).

2. RADAR WAVEFORM TABLE: f_start, f_stop, B, N_steps, step size,
   step dwell, T_up, retrace, PRI, chirps per dwell, dwell time, beams
   per scan, scan time; and the derived quantities with formulas:
   range cell c/2B (3.75 m), beat frequency vs range (417 Hz at 10 m;
   give the 1-30 m curve), IF band of interest, sound-card Nyquist and
   the anti-alias corner, max unambiguous range from the step size
   (c/2*delta_f), Doppler resolution and window (+/- lambda/(4*PRI) =
   4.2 m/s), micro-Doppler band of the rotors.

3. TIMING DIAGRAM (two chirps): frequency staircase, SYNC line high
   during the up-chirp, beat present during the up-chirp, PLL settle
   (first 5 % of each chirp dropped). State that T_up and PRI are
   measured from SYNC by the software and are different numbers.

4. RADAR LINK BUDGET, one row per stage: ADF4351 out, pad, PA, splitter
   (both arms), TX horn gain, EIRP, path loss to 3/5/10 m, RCS 0.01 m^2,
   return path, RX horn gain, LNA, mixer conversion loss, IF level,
   video amp gain, sound-card level; noise floor with NF 0.6 dB LNA in
   the 15 kHz video band; processing gain from 64 chirps and the
   range FFT; SNR at 3/5/10 m. Then the leakage row: 35 dB isolation
   -> leakage tone level at the IF and at the sound card after the two
   160 Hz high-passes, and the check that neither leakage nor the
   drone echo clips.

5. INTERFERENCE BUDGET, both directions:
   a. Radar into the drone's WiFi receiver at 3/5/10 m, beam on:
      raw level, adjacent-channel rejection assumed (16 dB at 20 MHz
      offset, 32 dB at 40 MHz, interpolated at the 28 MHz centre
      offset), resulting level vs the phone's -35 dBm, SIR, and the
      802.11 rate that survives (needs 5-10 dB). Include the fraction
      of time the beam is on the drone during a scan.
   b. Phone and AP into the radar receiver. The horn is wideband and
      the SPF5189Z is a 50-4000 MHz amplifier: compute the drone AP
      (+20 dBm, in beam, 3/5/10 m) and the phone (+15 dBm, in beam vs
      behind the horns at ~25 dB front-to-back) at the LNA input and at
      the mixer RF port, against SPF5189Z input P1dB (~+6 dBm) and the
      mixer's RF compression (~+9 dBm), including WiFi's ~10 dB
      peak-to-average. Show the margin with the AP at +20 dBm and at
      +8 dBm (the drone's AP power is turned down in firmware). Specify
      the 2400-2500 MHz band-pass filter between RX horn and LNA and
      state plainly what it does (out-of-ISM rejection) and does not
      (it cannot separate channel 1 from the sweep). Only then argue
      the linear case: channel-1 energy lands at 17-80 MHz IF, above
      the 15 kHz video filter.
   c. The failure case: sweep 2400-2483.5 crossing channel 1 ->
      in-channel radar level vs phone level, expected loss; this is
      the deliberate "see the loss appear" calibration in the
      coexistence test.

6. AUDIO / DIGITAL SIDE: sound card sample rate options (44.1 / 48 kHz)
   and what changes; sync divider levels; USB serial protocol timing
   between the laptop and the radar ESP32 (one AZ per beam, settle
   time); HTTP fix rate to the console (~1 per 4.3 s scan) and the
   10 Hz WebSocket state.

7. STAGE 3 ADDENDUM: second RX channel at 193 mm vertical spacing ->
   phase-to-elevation formula, unambiguous +/-18.5 deg vs the 17 deg
   half-beam, the fixed cable-phase calibration, and the 4-input
   audio interface requirement (single sample clock).

Format: tables with units and formulas beside every derived number;
mark each value COMPUTED, DATASHEET (with source), or ASSUMED. Finish
with a one-line consistency check against §0 (any number that differs
from §0 must be flagged, not silently changed).
```

---

## Appendix — where each fixed number comes from in this repo

| number | source |
|---|---|
| sweep, range cell, beat, Doppler window, link budget | `ground_station/fmcw_sim.py --f0 2.44 --sweep-bw 40 --chirp-ms 6.4 --gain 13.4 --budget` |
| horn geometry, gain, beamwidths, pe==ph | `antenna/horn.py` |
| 12° steps, 2.5° azimuth, centroid | `ground_station/scan_design.py`, `docs/scanning.md` |
| CFAR / centroid / PRI handling, self-test | `ground_station/radar_acquire.py --selftest --f0-mhz 2440 --bw-mhz 40` |
| interference budget, channel choice | `docs/drone-software.md` §0 |
| MIT chain order, video amp, sync, power | `docs/radar-hardware.md` |
| firmware protocol (`SET f0_mhz`, `AZ`, SYNC) | `firmware/radar_ctl/radar_ctl.ino` |
| parts and stock (Sept 2026) | `hardware/BOM.md` |

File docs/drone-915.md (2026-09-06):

# Fallback — ESP-FLY on a 915 MHz ELRS link

> **Not the current plan.** The drone is flown from the phone over its own
> WiFi AP on channel 1, with the radar sweeping 2440–2480 MHz above it
> ([`drone-915-esp-fc.md`](drone-915-esp-fc.md)). Use this page only if the link
> test in that guide's §4 fails. The esp-fc side of it is
> [`drone-915-esp-fc.md`](drone-915-esp-fc.md).

One drone. Goal: the ESP-FLY flies on a control link that is **not in the
2.4 GHz band the radar sweeps**. Nothing else on the airframe changes.

## 0. Why, in one paragraph

The radar puts ≈ +10 dBm into a 13 dBi horn and sweeps 2400–2483.5 MHz
continuously. At 10 m the drone's receiver sees that at about −34 dBm; its
own control signal arrives at −50…−60 dBm. A 2.4 GHz link — ELRS 2.4,
ESP-NOW, WiFi, anything — is being jammed by 20 dB every time the beam
points at the drone, which is exactly when you need it. ELRS's LoRa is
tough, but you would be betting the aircraft on an untested margin. The
900 MHz ELRS band is 1.5 GHz away: **zero** interaction, and better range
and wall penetration as a bonus.

## 1. What you have, and what it can't do

- **Receiver: RadioMaster RP1 V2** — an ExpressLRS **2.4 GHz** receiver.
- **Radio: RadioMaster T8L** — a screenless ELRS radio with a **built-in
  2.4 GHz** module (SX1281), 2.400–2.480 GHz, and **no external module bay**.
  There is no 900 MHz variant. It cannot be moved to 915 MHz.

So both ends of the link get replaced. Keep the T8L: it is still the right
tool for every flight where the radar is off (all of the bring-up in
[`drone-915-esp-fc.md`](drone-915-esp-fc.md)).

## 2. Parts (≈ $130)

| item | ~$ | why this one |
|---|---|---|
| **RadioMaster Pocket** (ELRS or CC2500 internal — irrelevant, you use the bay) | 65 | cheapest EdgeTX radio with a **Nano module bay** |
| **RadioMaster Bandit Nano**, 915 MHz ELRS module | 40 | fits the Pocket's Nano bay; 10 mW–1 W; FCC915 |
| **BetaFPV ELRS Nano receiver, 915 MHz** (0.7 g) or HappyModel ES900RX (0.6 g) | 17 | lightest 900 MHz receivers; same CRSF wiring as the RP1 V2 |
| 915 MHz receiver antenna (usually included: ~80 mm wire or "T") | 0–5 | |

Alternatives: any EdgeTX radio with a JR bay (Boxer, TX12) + Bandit Micro;
HappyModel ES900TX (Nano) instead of the Bandit Nano. Both ends must be the
**same ELRS major version** and the **same regulatory domain (FCC915)**.

Weight: the RP1 V2 is ~0.9 g with its 31 mm antenna; the Nano 915 is ~0.7 g
plus a ~1 g antenna → about **+1 g on a 25 g aircraft**. Fine.

## 3. Swap the receiver

The RP1 V2 is wired to the XIAO ESP32-S3 with four wires: 5 V (or the pad
you currently power it from), GND, RX-TX → XIAO RX, RX-RX → XIAO TX. The
915 MHz receiver has **exactly the same four pads** and speaks the **same
CRSF** protocol, so:

1. Photograph the current wiring before touching anything.
2. Desolder the RP1 V2. Note which XIAO pin its **TX** wire went to — that
   is the pin esp-fc has as the serial-RX input (in the published esp-fc /
   XIAO guide it is **GPIO 9 = serial 2 RX**, with **GPIO 8 = serial 2 TX**;
   yours may differ — the wire tells you, and `get pin` in the esp-fc CLI
   confirms it).
3. Solder the 915 receiver to the **same four pads**: power to the same rail
   the RP1 V2 used, GND, its TX to the XIAO pin the old TX used, its RX to
   the old RX pin.
4. Shrink-wrap the receiver, tape it to the top plate away from the motors.

**Checkpoint 3:** power the drone on USB; the receiver's LED blinks slowly
(no bind) — it is alive on the same rail the RP1 V2 was.

## 4. Route the 915 MHz antenna

A 915 MHz quarter-wave is **~80 mm**, not 31 mm. On a 67 mm frame:

- run it straight out along one arm and past the motor, or straight back
  as a tail, with ~10 mm of the base kept clear of any metal or the battery;
- never parallel to and touching a motor wire, never under a prop;
- fix it with a short piece of heat-shrink to a zip-tie stub so it cannot
  reach a prop in a crash.

A drooping tail antenna is the usual answer on micro quads and works.

**Checkpoint 4:** props on, spin up on the bench held down — the antenna
does not touch a prop at full throttle.

## 5. Nothing else changes

The XIAO ESP32-S3, the flight-controller board, MPU-6050, motors, battery
and esp-fc firmware are untouched. With a serial receiver, esp-fc does not
bring WiFi up at all in flight (`espfly.md` §2) — so **the drone emits
nothing in 2.4 GHz** and the radar band is clean. That was the whole point.

## 6. Radio side

Slide the Bandit Nano into the Pocket's bay, screw it, fit its antenna (the
module ships with one). Set the Pocket's **internal** RF module to OFF and
the **external** module to CRSF in the model setup — [`drone-915-esp-fc.md`](drone-915-esp-fc.md) §1.

**Checkpoint 6:** the Pocket boots, the module's OLED lights, ELRS Lua opens
and shows the module's version and FCC915.

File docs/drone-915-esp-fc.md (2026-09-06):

# Fallback — esp-fc configuration for the 915 MHz link

> **Not the current plan** (the drone is flown from the phone — see
> [`drone-software.md`](drone-software.md)). This is the software half of the
> [`drone-915.md`](drone-915.md) fallback, used only if the WiFi/radar
> coexistence test fails.

What runs on the drone is **esp-fc, unmodified**. There is no custom flight
code in this repo and there should not be: the drone is a passive target
for the radar, and CRSF is CRSF whether it arrives at 2.4 GHz or 915 MHz.
"Drone software" is therefore three configurations, in this order:

1. ExpressLRS on the **TX module and receiver** (band, bind, rate)
2. EdgeTX on the **Pocket** (model, module, switches)
3. esp-fc on the **XIAO** (serial port, CRSF, arm/mode switches, failsafe)

The esp-fc part is captured as a CLI script: `firmware/espfly/espfly-915.cli`.

Props OFF for everything until §6.

---

## 1. ExpressLRS — both ends on FCC915, one binding phrase

Use the **ExpressLRS Configurator** (desktop app). For each device, target
→ flash:

| device | target | options |
|---|---|---|
| Bandit Nano | RadioMaster → Bandit Nano 900 TX | regulatory domain **FCC915**, binding phrase e.g. `espfly-radar`, same version as the RX |
| BetaFPV Nano 915 RX | BetaFPV → Nano 900 RX (or HappyModel → ES900RX) | **FCC915**, **same** binding phrase, same version |

Flash the module over its USB port; flash the receiver by USB/UART adapter
or over its own WiFi (power it, join `ExpressLRS RX`, open 10.0.0.1).

**Checkpoint 1:** with both flashed and the receiver powered on the drone,
the receiver LED goes **solid** within a few seconds of the Pocket being on:
bound, on 915.

## 2. EdgeTX on the Pocket

Model setup → Internal RF: **OFF**. External RF: **CRSF**. Then the ELRS Lua
script (Tools → ExpressLRS):

| setting | value | why |
|---|---|---|
| Packet rate | **100 Hz Full** (or 200 Hz) | 10 full-res channels; 900 MHz tops out at 200 |
| Telemetry ratio | 1:64 | you only need LQ/RSSI back |
| Switch mode | Wide | |
| TX power | **25 mW** | indoors, 10 m; raise later if LQ ever drops |
| Dynamic power | off while testing | you want a constant number to compare against the radar |

Mixer (default is fine): CH1–4 = **A E T R** on the sticks (esp-fc's map is
set to match below), CH5 = a two-position switch for **ARM**, CH6 = a
switch for **ANGLE** mode.

**Checkpoint 2:** Lua shows the module *connected*, LQ 100, and the
receiver's RSSI around −40…−60 dBm at bench distance.

## 3. esp-fc — Configurator part

Connect the drone by USB, open **Betaflight Configurator 10.10** (esp-fc
speaks its MSP; newer configurators refuse it).

1. **Ports** tab: on the UART your receiver is wired to (the published
   XIAO guide uses **UART 2**, GPIO 9 RX / GPIO 8 TX), tick **Serial Rx**.
   Save. If you are not sure which UART, `get pin` in the CLI tab lists
   `pin_serial_2_rx` etc. against the GPIO you found in
   [`drone-915.md`](drone-915.md) §3.
2. **Receiver** tab: Receiver Mode **Serial (via UART)**, Serial Receiver
   Provider **CRSF**. Channel map **TAER1234** if the bars move on the wrong
   sticks; otherwise the default. Save.
3. Move the sticks: the four bars follow, 1000 → 2000 with 1500 centred.
   Adjust EdgeTX endpoints, not esp-fc, if they don't reach.
4. **Modes** tab: ARM on the CH5 switch range, ANGLE on CH6. Save.

**Checkpoint 3:** Receiver tab bars follow every stick and both switches.
If they twitch or drop: wrong UART, or TX/RX wires swapped.

## 4. esp-fc — CLI script

`firmware/espfly/espfly-915.cli` pins the receiver wiring, the serial
function and the failsafe in a form you can paste back after any reset.
Open the **CLI** tab and paste it line by line (or all at once if your
configurator passes multi-line). It ends with `save`.

What it sets, and why (the exact syntax is esp-fc's, from its `docs/cli.md`):

```
set pin_serial_2_rx 9          # the XIAO GPIO the receiver's TX is soldered to
set pin_serial_2_tx 8          # and its RX (needed for CRSF telemetry back)
set feature_rx_serial 1        # receiver is serial, not the built-in ESP-NOW "SPI Rx"
set failsafe_delay 4           # 0.4 s of no packets -> failsafe (the only stage-2 action is DROP)
set failsafe_kill_switch 0
save
```

Two things the CLI file does **not** set, because their ids are best read
back from the configurator rather than guessed: the serial-2 *function* (the
Ports tab's Serial Rx tick) and the receiver *provider* (CRSF). After step
3, `get serial_2` and `get rx` in the CLI show what the configurator wrote —
paste those two lines into your copy of the file so it is complete for your
build.

**Checkpoint 4:** `reboot`, reconnect, Receiver tab still live; `get pin`
shows serial 2 on the pins you soldered.

## 5. Failsafe test (props OFF)

1. Arm on the bench (motors spin, props off). Switch the Pocket **off**.
2. Within ~0.5 s the motors must **stop** and the drone disarm. esp-fc's
   only stage-2 failsafe is DROP — that is the correct behaviour for a
   25 g indoor quad; there is no GPS return.
3. Power the Pocket back on: the link recovers, the drone stays disarmed
   until you cycle the ARM switch.

**Checkpoint 5:** motors stop on TX-off every time, three times in a row.

## 6. First flights — radar OFF, then radar ON

1. **T8L + RP1 V2 baseline** is not needed any more; from here fly on the
   Pocket. Props on, room clear, ANGLE mode, arm, hover at 1 m for 30 s,
   land. Same as before the swap — the flight controller is unchanged.
2. **Radar sweeping, drone on the bench 1 m in front of the horns**, powered
   and bound, props off: open the ELRS Lua → the receiver's **LQ must stay
   100** and RSSI unchanged while `SWEEP 1` runs. That single number is the
   proof that the band separation works. (With the old RP1 V2 in this test,
   LQ would be dropping.)
3. Hover in the sector with the radar scanning. The console shows the fix;
   Lua shows LQ still 100.

**Checkpoint 6:** a 2-minute hover in the scanned sector with LQ 100
throughout and a continuous radar track in the console.

## 7. What is deliberately *not* on the drone

- No beacon firmware, no MAC filtering, no WiFi AP — those were the passive
  system. The radar sees the airframe; the drone cooperates by being made
  of copper, carbon and motors.
- No custom code in esp-fc. If you later want the drone to *use* the radar's
  track (the two-drone end goal), that is the laptop-side commander path in
  [`interception.md`](interception.md), and with ELRS it becomes trivially
  cleaner: the laptop drives the Pocket's trainer port or a second ELRS
  module instead of an ESP-NOW commander. Different project, later.

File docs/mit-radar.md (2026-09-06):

# Building the MIT radar with a custom antenna — full plan

> **Build it from the step-by-step guides:** [`radar-hardware.md`](radar-hardware.md)
> and [`radar-software.md`](radar-software.md). The parts list in §4 below
> predates the September 2026 sourcing check — the ZX95 VCO is non-catalog
> and two Mini-Circuits parts are out of stock; the current, priced list is
> [`../hardware/BOM.md`](../hardware/BOM.md).

**Read this first, then `Phase 0`. Nothing here needs you to buy anything until
you have run the simulator and are happy with the numbers.**

This is a real radar: it **transmits** a swept signal and measures the **echo**
off a target. That is the thing you originally asked for back at the start of
this project and that I told you was not achievable passively — and I was right
about the *passive* version, but an **active FMCW radar makes it achievable**,
which is exactly what the MIT design is. It measures true range and velocity
from reflections, off targets that carry no transmitter at all.

Everything below is either quoted from a primary source or computed by the two
tools added to this repo:

```bash
python ground_station/fmcw_sim.py --budget       # radar performance + link budget
python ground_station/fmcw_sim.py --leakage      # the failure mode that bites everyone
python ground_station/fmcw_sim.py --microdoppler # how to see a HOVERING drone
python antenna/vivaldi.py --array 4 --svg a.svg  # the custom antenna
```

---

## 0. STOP — the one thing that will break this project

**Your radar and your drone both want 2.4 GHz, and the radar will jam the
drone.**

The MIT radar transmits **+13 dBm continuously**, swept across 2.36–2.50 GHz.
Your ESP-BLAST is flown over ESP-NOW on **WiFi channel 7 (2.442 GHz)** — right
in the middle of that sweep.

Run the numbers: +13 dBm into a 9 dBi antenna is +22 dBm EIRP. At 10 m the free
space loss is ~60 dB, so the drone's receiver sees the radar at **≈ −38 dBm**,
while the wanted control signal from your commander arrives at maybe −50 to
−60 dBm. **The interferer is 12–22 dB stronger than the signal you are trying to
fly on.** The radar dwells in the drone's 20 MHz channel ~14 % of each sweep, so
you would get heavy, bursty packet loss on the control link precisely when the
drone is close — which is exactly when you care.

> **Now unambiguous.** This project no longer does any passive RF tracking, so
> nothing needs the drone to keep a 2.4 GHz link alive. The conflict noted in
> `espfly.md` is gone: **move the drone to 915 MHz ELRS, no downside.**

### The fix: move the drone's control link off 2.4 GHz

ESP-FC already supports **CRSF/ELRS** (verified in its README feature list,
alongside PPM/SBUS/IBUS). So:

> **Replace the 2.4 GHz ESP-NOW link with a 900 MHz ExpressLRS link.**
> A 915 MHz ELRS RX (~$20) plus a 915 MHz ELRS TX module gives you a clean,
> long-range control link **1.5 GHz away from the radar band**, and it is
> *better* than ESP-NOW for range and link robustness anyway.

This has a second benefit: it removes the exclusive-binding awkwardness from
`docs/interception.md` §3 (ELRS has proper binding and a real failsafe), and it
frees the whole 2.4 GHz band for the radar.

**Do this before you build the radar, not after.** It changes the drone build.

---

## 1. Second constraint: stay inside the ISM band

The stock MIT design sweeps **2.36–2.50 GHz**. The bottom of that sweep is *not*
license-free in the US: **2360–2395 MHz is allocated to Aeronautical Mobile
Telemetry and medical body-area networks**, not to unlicensed devices. MIT ran
the course in an institutional context; you should not radiate there.

**Restrict the sweep to the 2.4 GHz ISM band: 2400–2483.5 MHz = 83.5 MHz.**

What that costs you (computed):

| | full MIT sweep (140 MHz) | **ISM-legal (83.5 MHz)** |
|---|---|---|
| range resolution `c/2B` | 1.07 m | **1.80 m** |
| legal unlicensed? | ✗ (dips into AMT band) | **✓** |

1.80 m resolution is fine for detecting a drone in a 5–10 m box — you are not
trying to resolve two drones 1 m apart. Take the legality.

---

## 1b. It measures range and velocity — NOT position

One TX horn + one RX horn has **no angle information**. To get position you
must scan the antennas (a ~$15 servo) or add a second receive channel.
This is a first-order architectural requirement, not a refinement — the full
analysis, the measured beam-stepping tradeoff and the end-to-end result
(**0.12 m RMS tracking error**) are in **[`scanning.md`](scanning.md)**.

## 2. What you actually get (computed, not guessed)

`fmcw_sim.py --f0 2.4 --sweep-bw 83.5 --chirp-ms 2`:

```
range resolution    : 1.80 m        <- bandwidth-limited, c/2B
max unambiguous rng : 79 m          <- sound-card Nyquist
velocity window     : +/-15.3 m/s
velocity resolution : 0.48 m/s
beat freq @ 10 m    : 2785 Hz       <- lands nicely in audio
```

Detection margin on **your** drone:

| target | RCS | echo @ 10 m | **SNR @ 10 m** |
|---|---|---|---|
| **small quad (ESP-BLAST class)** | 0.01 m² | −83 dBm | **58 dB** |
| larger quad (Phantom class) | 0.10 m² | −73 dBm | 68 dB |
| human | 1.0 m² | −63 dBm | 78 dB |
| car | 10 m² | −53 dBm | 88 dB |

**58 dB of margin on a small drone at 10 m.** Sensitivity is not your problem —
this radar sees your drone easily at the ranges you care about. Your problems
are the three below.

---

## 3. The three things that will actually bite you

### 3a. TX→RX leakage will drown the target (and background subtraction fixes it)

At short range the transmitter leaks directly into the receiver, ~35 dB down,
which is *enormously* stronger than any echo. Simulated, with a drone at 8 m
closing at 2 m/s:

```
raw (leakage present)        -> detected R = 2.1 m, v = 0.0 m/s   WRONG (leakage wins)
WITH background subtraction  -> detected R = 8.6 m, v = +1.9 m/s  correct
```

**Background subtraction** — subtract the average of the last N chirps before
the Doppler FFT — removes anything that doesn't move. That is one line of DSP
and it is the single most important line in the whole system.

### 3b. A HOVERING drone disappears — use the rotor lines

Background subtraction deletes everything at zero Doppler. A hovering drone is
at zero Doppler. It vanishes along with the clutter.

The way out is **rotor micro-Doppler** (`--microdoppler`). Your rotors do not
hover even when the airframe does:

```
prop 2.5", 20000 RPM, 3 blades
blade tip speed  : 66 m/s
tip Doppler      : +/-1.08 kHz      <- lands in the audio band
blade flash rate : 1000 Hz
body Doppler if hovering: 0 Hz      <- removed by clutter cancellation
```

**Look for a symmetric pair of sidebands ~1.1 kHz either side of DC that switch
on and off with the throttle.** That signature is also how you tell a drone from
a bird, a person, or a swaying tree — it is the classic drone-detection
discriminator, and it survives clutter cancellation.

### 3c. The default 20 ms chirp aliases a moving drone

At the MIT default 20 ms sweep the unambiguous velocity window is only
**±1.5 m/s**. The simulator demonstrates the failure: a target truly moving at
+2.0 m/s reads back as **−1.0 m/s**. Shorten the chirp:

| chirp | velocity window | max range |
|---|---|---|
| 20 ms (MIT default) | ±1.5 m/s | 472 m |
| 5 ms | ±6.2 m/s | 118 m |
| **2 ms (recommended)** | **±15.4 m/s** | **47–79 m** |
| 1 ms | ±30.8 m/s | 24 m |

**Use ~2 ms.** You trade unusable range for usable velocity.

---

## 4. Parts list

### 4a. RF chain — the six coax parts (unchanged from MIT)

| Callout | Qty | Part | Description | Supplier | Unit | Total |
|---|---|---|---|---|---|---|
| OSC1 | 1 | **ZX95-2536C+** | VCO, 2315–2536 MHz, +6 dBm | Mini-Circuits | $98.95 | $98.95 |
| ATT1 | 1 | **VAT-3+** | 3 dB SMA attenuator | Mini-Circuits | $13.95 | $13.95 |
| PA1/LNA1 | 2 | **ZX60-272LN-S+** | Amp, 14 dB gain, NF 1.2 dB | Mini-Circuits | $69.95 | $139.90 |
| SPLTR1 | 1 | **ZX10-2-42+** | Splitter, 1900–4200 MHz | Mini-Circuits | $34.95 | $34.95 |
| MXR1 | 1 | **ZX05-43MH-S+** | Mixer, +13 dBm LO | Mini-Circuits | $46.45 | $46.45 |
| — | 4 | **SM-SM50+** | SMA M-M barrels | Mini-Circuits | $5.95 | $23.80 |
| — | 3 | **086-12SM+** | 6″ SMA M-M cables | Mini-Circuits | $12.95 | $38.85 |

**RF subtotal ≈ $397.** All still stocked (DigiKey/Mini-Circuits).

### 4b. Baseband, modulator, power

| Part | Description | Supplier | Cost |
|---|---|---|---|
| **LT1214CN** | Low-noise quad op-amp (video amp) | DigiKey | $12.37 |
| ~~XR-2206~~ → **ESP32** | sweep generator — see modernisation below | you have one | $0 |
| EXP-300E | solderless breadboard | Mouser | $7.45 |
| 172-2236 | 3.5 mm plug → stripped wires | Mouser | $3.63 |
| 2× SMA bulkhead, brackets, 6-32 hardware | mounting | McMaster/Mouser | ~$25 |
| 8× AA battery holder + batteries | power (keep it off mains — less noise) | — | ~$10 |
| **Servo + bracket (e.g. MG996R) for the scan** | **turns range-only into position — see `scanning.md`** | — | **~$15** |
| Assorted 1 % resistors / 1000 pF caps | baseband filter | DigiKey | ~$6 |

**Total ≈ $460** with the ESP32 modernisation, ≈ $470 with the original XR-2206.

### 4c. Recommended modernisation: replace the XR-2206 with an ESP32

The XR-2206 function generator is long obsolete and increasingly counterfeit on
the open market. You already have ESP32s. Drive the VCO tuning voltage from an
**ESP32 DAC** (or a cheap MCP4921 SPI DAC for cleaner 12-bit steps) instead:

- **software-defined waveforms** — sawtooth, triangle, arbitrary, and you can
  change bandwidth/chirp time in code instead of swapping resistors;
- **synchronisation** — the same MCU can trigger the ADC/audio capture, which
  removes the sweep-to-capture alignment problem that plagues the sound-card
  build;
- it's the same modernisation the University of Alabama in Huntsville thesis
  *"Future-proofing the MIT coffee can radar"* (2022) made, along with moving
  to surface-mount parts and — note — **Vivaldi antennas**.

Buffer the DAC output with an op-amp and scale it to the VCO's 0–5 V tuning
range. Check the VCO tuning curve is monotonic and linearise it in software
(it is quite nonlinear; linearising is worth ~a bin of range resolution).

---

## 5. The custom antenna

### Why Vivaldi (and not a patch, and not the cans)

An FMCW radar has to stay matched across its **whole sweep**. Over 2.40–2.4835
GHz that's 3.4 %, and you want margin either side. An FR4 patch manages ~1–3 % —
marginal. A **Vivaldi (exponentially tapered slot) runs over octaves.** It is
also flat, repeatable, and manufacturable as an ordinary 2-layer PCB from the
same fab you already use for the flight controller.

`python antenna/vivaldi.py`:

```
band            : 2.30 - 2.60 GHz  (12.2 % fractional)
substrate       : FR4, er=4.4, h=1.6 mm, 1 oz Cu
mouth aperture W: 75.6 mm    (rule: >= lambda/2 = 65.2 mm)
flare length  L : 136.9 mm   (rule: >= lambda   = 130.3 mm)
throat slot     : 0.50 mm
opening rate R  : 0.0367 /mm
50 ohm feed     : 3.06 mm microstrip
board           : 162 x 84 mm
est. gain       : ~6.4 dBi  (single element)
```

**Be honest about the trade:** a *single* Vivaldi is ~6.4 dBi — slightly **worse**
than a coffee can (~9 dBi). The Vivaldi wins when you **array** it:

| configuration | gain | board | notes |
|---|---|---|---|
| coffee can | ~9 dBi | free | works, bulky, can't array |
| single Vivaldi | ~6.4 dBi | 162×84 mm | flat, repeatable, easy |
| **4-element Vivaldi array** | **~12.4 dBi** | 192×277 mm | +6 dB, ~51° az beam, needs a feed network |

`python antenna/vivaldi.py --array 4 --svg viv4.svg` writes the outline; import
into KiCad (File → Import → Graphics, 1:1), copper on `F.Cu`, outline on
`Edge.Cuts`.

### The array unlocks the thing you were worried about last night

Two RX Vivaldis spaced λ/2 give you **azimuth angle from the phase difference**
between channels. Range (from the beat) + angle (from the phase) = a genuine 2D
position fix **from a single radar site** — no multilateration, no coplanar-node
mirror ambiguity. That is a fundamentally better answer to your 3D question than
anything the RSSI system can do. It needs a second receive channel (a second
mixer + amp, ~$116), so treat it as Phase 5, not Phase 1.

---

## 6. How to simulate before you spend $460

**Two different simulations, don't confuse them:**

### 6a. System/signal simulation — `ground_station/fmcw_sim.py` (built, works now)

Models the whole chain: chirp → target echo → mixer beat → range FFT → Doppler
FFT → range-Doppler map, including thermal noise, TX leakage and ADC dynamic
range. Use it to choose bandwidth, chirp time and antenna gain **before**
ordering, and to develop your DSP against known ground truth.

```bash
python ground_station/fmcw_sim.py --budget                 # can it see my drone?
python ground_station/fmcw_sim.py --chirp-ms 2 --leakage   # prove background subtraction
python ground_station/fmcw_sim.py --chirp-ms 2 --rdmap rd.png
python ground_station/fmcw_sim.py --microdoppler --rpm 20000
```

### 6b. Electromagnetic simulation — openEMS (for the antenna only)

The antenna is the one part you cannot compute with algebra; it needs a
full-wave solver. **openEMS** is the free FDTD solver (the same one I suggested
back in the radar-simulation-software roadmap — this is where it earns its
keep).

```bash
pip install openEMS   # plus CSXCAD; see docs.openems.de
python antenna/vivaldi.py --openems > viv_sim.py   # scaffold + pass criteria
```

Work through the official **Simple Patch Antenna** tutorial first (an hour), then
adapt it — the mechanics (mesh, port, NF2FF far-field transform) are identical.

**Pass criterion: |S11| < −10 dB across 2.40–2.4835 GHz.** If the sim doesn't
hit that, change `--f-low` / throat width / opening rate and re-run. Iterating in
the solver is free; iterating in FR4 is $30 and two weeks each time.

---

## 7. Build plan

Each phase ends in a checkpoint. **Do not skip checkpoints** — an FMCW radar
that doesn't work is very hard to debug from the far end.

### Phase 0 — Simulate and decide (this week, $0)
Run `fmcw_sim.py --budget` and `--leakage`. Convince yourself the SNR margin and
the resolution are what you want. Decide sweep bandwidth (83.5 MHz) and chirp
time (2 ms).
**Checkpoint 0:** you can explain why 1.80 m resolution and ±15 m/s are the right
trades for your box.

### Phase 1 — Move the drone off 2.4 GHz (before anything else)
Fit a 915 MHz ELRS receiver to the ESP-BLAST, set ESP-FC's receiver to CRSF, bind
to a 915 MHz TX module, verify failsafe.
**Checkpoint 1:** the drone flies normally with the 2.4 GHz radio physically
removed. *You cannot safely test the radar near the drone until this is true.*

### Phase 2 — Antenna in simulation
Run `vivaldi.py`, port into openEMS, iterate to |S11| < −10 dB across the band.
**Checkpoint 2:** a simulated S11 plot meeting the criterion, and a far-field
pattern showing endfire gain ≈ 6–7 dBi.

### Phase 3 — Build the radar with coffee cans first
Order the RF BOM. Build on the breadboard exactly per the MIT design, but drive
the VCO from your ESP32 DAC. **Use coffee cans for the first light** — they are
free, known-good, and remove the antenna as a variable while you debug the RF
chain.
**Checkpoint 3:** point it at a car driving past and see a clean range line in
the MIT `Experiment 2` MATLAB/Python processing. This is the classic first
success and it validates the entire chain.

### Phase 4 — Swap in the custom Vivaldis
Order the PCBs (JLCPCB, 1.6 mm FR4, 1 oz). Measure S11 with a NanoVNA
(~$50 — buy one, you will use it forever) and compare against the openEMS
prediction.
**Checkpoint 4:** measured S11 within a few dB of simulation, and the radar
still sees the car. Then try the drone.

### Phase 5 — Drone detection and tracking
Hover the drone at 5–10 m. Find the body return (moving) and the **rotor
micro-Doppler lines** (hovering). Implement background subtraction and a simple
CFAR detector.
**Checkpoint 5:** you can plot drone range vs time as it flies, and identify it
as a drone from the rotor lines.

### Phase 6 — Angle, and integration with the interception project (optional)
Add a second RX channel and a two-element RX array for azimuth. Feed range +
angle into the existing tracker in place of (or alongside) the RSSI fixes.

---

## 8. Legal and safety

- **Stay in 2400–2483.5 MHz.** Do not radiate in 2360–2400 (AMT/MBAN).
  20 mW EIRP-class in ISM is the benign case, but keep the sweep inside the band.
- Do not point it at people at close range for extended periods. 20 mW is very
  low power (a WiFi router is 100 mW) but there is no reason to dwell on anyone.
- The 915 MHz ELRS link must respect your region's ISM rules (US 902–928 MHz).
- Everything in `docs/interception.md` §8 still applies to the flying side —
  VLOS, a human on the kill switch, tracking only, never weaponised.

---

## 9. How this fits the existing project

This does **not** throw away what we built. The two systems answer different
questions and complement each other:

| | passive RSSI system (built) | **FMCW radar (this plan)** |
|---|---|---|
| target must cooperate? | **yes** — must transmit | **no** — detects reflections |
| what it measures | position (multilateration) | **true range + velocity** |
| horizontal accuracy | ~2 m | ~1.8 m (resolution-limited) |
| altitude | ✗ (needs baro) | ✗ single site; ✓ with an array |
| identifies a drone? | by MAC | **by rotor micro-Doppler** |
| cost | ~$56 | ~$460 |

For the two-drone interception goal, the natural end state is: **track your own
interceptor cooperatively** (it carries your ESP32 and tells you where it is)
and **track the target by radar** (it doesn't have to cooperate at all). That is
a much stronger system than either half, and it's the architecture a real
counter-UAS installation uses.

---

## 10. First three things to do when you wake up

1. `python ground_station/fmcw_sim.py --budget` — see the 58 dB margin yourself.
2. Order a **915 MHz ELRS RX + TX module** (~$50). This is on the critical path
   and everything else waits on it.
3. Read the MIT course's **Radar System Design** PDF (block diagram, schematics,
   BOM, fabrication) — it is the canonical build reference:
   `ocw.mit.edu` → RES.LL-003 → Projects → *Radar System Design*.

Send me the transcript from the other session when you're up and I'll fold in
whatever it decided that this plan doesn't already cover.

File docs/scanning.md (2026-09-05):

# Getting position out of the can radar

**The gap that is easy to miss when planning this build: one TX horn plus one
RX horn measures range and radial velocity, and nothing else.** There is no
angle in that measurement. A drone 8 m dead ahead and a drone 8 m at 30° off
axis produce the *identical* beat tone. Range alone cannot tell you where
something is.

This page is the answer, with numbers from
`ground_station/scan_design.py` and `ground_station/radar_twin.py`.

## The three options

| | what it gives | cost | verdict |
|---|---|---|---|
| **1. Range + Doppler only** | closing rate, rotor Doppler ID, "how far" | $0 | fine as the **first milestone**, not the end |
| **2. Mechanically scan the horns** | full 2-D position, a true PPI | **~$15 servo** | **recommended** |
| 3. Two RX channels, angle from phase | fast angle, no moving parts | ~$116 + 2nd ADC | ambiguous with horns — see below |

### Why interferometry does not work with horns

Angle from phase needs `|sin θ| ≤ λ/2d`. Two horns physically cannot sit closer
than one aperture apart, and your aperture is 264 mm = **2.15 λ**:

| baseline | λ | unambiguous | verdict |
|---|---|---|---|
| 61 mm | 0.50 | ±90° | clean |
| 150 mm | 1.22 | ±24° | clean |
| **264 mm (horn)** | **2.15** | **±13.4°** | **ambiguous inside its own 36° beam** |

You would get several candidate angles for one target. If you ever want
electronic angle, use the **horn for TX** and a pair of **small** elements at
λ/2 = 61 mm for RX.

## The scanning design

Bolt the horn pair to a servo and step it across a sector. Each dwell is one
coherent processing interval (64 chirps × 2 ms = 128 ms) plus servo settling.

**How finely to step** — measured, not assumed:

| oversample | step | beams | sweep | azimuth RMS error | cross-range @ 8 m |
|---|---|---|---|---|---|
| 2× | 18° | 6 | 0.95 s | 5.1° | 0.72 m |
| **3×** | **12°** | **9** | **1.42 s** | **2.5°** | **0.35 m** |
| 4× | 9° | 11 | 1.74 s | 3.6° | 0.51 m |
| 6× | 6° | 16 | 2.53 s | 2.1° | 0.29 m |

**Use 3× oversampling (12° step).** Going to 6× buys only 6 cm of cross-range
for nearly double the revisit time.

Note the measured 2.5° is worse than the ~1.8° the SNR-limited formula
predicts. That is honest: real centroiding is limited by **amplitude-estimate
noise and beam-pattern knowledge**, not by thermal SNR. Do not plan around the
theoretical number.

### Once you have a track, stop scanning the whole sector

| mode | revisit |
|---|---|
| full 90° search sweep | 1.42 s (0.7 Hz) |
| **locked 2-position dither** | **0.32 s (3.2 Hz)** — 4× faster |

Sequential lobing (dither ±half a beamwidth around the target and compare
amplitudes either side) is both faster and *more* accurate than reading a peak
position, because a difference of two large numbers is far more sensitive to
angle than the peak of a broad lobe.

## End-to-end result

`ground_station/radar_twin.py` chains the whole thing — beam positions →
`fmcw_sim` chirp/echo/range-Doppler per beam → CA-CFAR detection →
amplitude-weighted azimuth centroid → `tracker.TrackKF`:

```
python radar_twin.py --track 20

  t     true r/az     meas r/az      track x,y      err
 15.6   7.4/+11.0     7.4/+11.0   (  7.26,  1.41)   0.01
 17.1   7.0/ +6.4     6.9/ +6.4   (  6.88,  0.77)   0.04
 18.5   6.6/ +1.4     6.6/ +1.4   (  6.61,  0.16)   0.04

  RMS track error: 0.12 m over 15 scans
```

**12 cm RMS tracking error**, versus ~2 m from the passive RSSI system.

## Three DSP traps this twin already hit (so you don't have to)

1. **CFAR self-masking.** A strong target's spectral leakage contaminates the
   training cells, so the threshold rises and the *strongest* target is
   rejected while noise elsewhere passes. The guard band must be wider than
   the target's windowed mainlobe — `guard=4` cells here, not 1.
2. **Never average in dB.** CA-CFAR must average **linear power**. Taking a
   mean (or median) of dB values is biased toward the low outliers and turns
   ordinary spectral leakage into a 40 dB "detection".
3. **Interpolate the range peak.** Reading the raw FFT bin centre costs a fixed
   bias of up to half a range cell (~0.9 m here). A parabolic fit through the
   peak and its two neighbours turns 1.8 m *resolution* into ~**10 cm
   accuracy** — that single change is what takes the range error from +1.00 m
   to +0.09 m.

## Build order

1. **Antennas bolted down, range + Doppler only.** Prove the RF chain on a
   walking person and a passing car (`mit-radar.md` Phase 3).
2. **Add the servo → scanning PPI.** 12° steps over your sector. This is the
   cheapest path to real position, and it makes the console's PPI scope
   literally correct rather than decorative.
3. **Lock and dither** once tracking, for 4× revisit and better angle.
4. **Only then** consider a second RX channel — and with small elements, not
   the horns.

## Elevation

A single scan axis gives azimuth only. For 3-D, either add a second servo
(pan-tilt, ~$25 more) or accept 2-D and constrain altitude separately. With a
34° elevation beamwidth the horn already covers a useful vertical slice at
short range, so azimuth-only is a reasonable first system for an indoor box.

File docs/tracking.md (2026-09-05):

# Tracking filter — what the measurement actually says

The plan was: replace the EMA with a constant-velocity Kalman filter and
predict ~0.5 s ahead to compensate sensor latency. **I built it and measured
it, and on today's sensor that makes things worse.** The filter is in the repo
and is the right thing to build — it is just *gated off* until the sensor is
good enough to earn it.

Reproduce everything here with:

```bash
python ground_station/tracker.py
```

## The experiment

Score each estimator on what the system actually needs: **error against the
drone's TRUE CURRENT position**, when fixes arrive late. Agile target
(1.2 rad/s orbit, ~2.5 m/s², 2.2 m/s).

| sensor | σ | rate | latency | EMA | Kalman | Kalman + predict |
|---|---|---|---|---|---|---|
| **RSSI multilateration (today)** | 1.50 m | 4 Hz | 0.50 s | **2.16 m** | 2.37 m | 2.92 m |
| + FTM ranging | 0.60 m | 4 Hz | 0.35 s | 1.56 m | **1.24 m** | 1.40 m |
| mmWave (position only) | 0.10 m | 20 Hz | 0.05 s | 0.32 m | 0.16 m | **0.15 m** |
| mmWave + Doppler velocity | 0.10 m | 20 Hz | 0.05 s | 0.32 m | 0.12 m | **0.04 m** |

## Why — one line

> **Prediction only pays when the target moves further during the latency than
> the measurement noise:  `speed × latency > σ`.**

- RSSI today: moves **1.08 m** during the latency, noise is **1.50 m** → the
  velocity you extrapolate with is itself derived from differencing noisy
  positions, so you inject more error than you remove. Prediction *cannot* pay.
- FTM: moves 0.76 m vs 0.60 m of noise → it starts paying, and the filter wins
  by ~20 %.
- mmWave with Doppler: velocity is **measured directly**, not differenced —
  which is why it goes from a marginal gain to an **8× one**.

A constant-**acceleration** model was also tried; it is worse than constant
velocity here (the orbit's acceleration is itself rotating), so CV stays the
default.

## What shipped

`ground_station/tracker.py`:
- 3D Kalman filter, CV (6-state) or CA (9-state), Joseph-form update.
- **R comes from `geometry.position_cov()`**, so a fix taken with poor geometry
  — e.g. altitude from near-coplanar nodes — is automatically distrusted
  instead of believed.
- `update_velocity()` for a direct Doppler measurement (the mmWave path).
- `predict_ahead(t)` → predicted position **and** grown covariance.
- `prediction_is_justified(σ, latency, speed)` — the gate above.

`server.py` runs the filter **always** (it supplies the covariance ellipse and
the az/el readout) but only lets it **drive** the displayed fix when the gate
passes. The console shows which is live: *"Estimator: EMA (filter gated off)"*
or *"Kalman + predict"*. Today, on RSSI, it correctly reads gated-off.

The console draws the 1-σ covariance ellipse on the current fix, and — with
**PREDICT** enabled — an orange ghost blip at +0.5 s with its own larger
ellipse, so the growth of uncertainty with horizon is visible rather than
implied.

## Update: on the can radar, the filter turns ON

The project moved to an active FMCW radar, which changes the verdict
completely — because the radar **measures velocity directly from Doppler**
instead of differencing noisy positions:

| sensor | σ | rate | latency | EMA | KF | KF + predict |
|---|---|---|---|---|---|---|
| RSSI (dropped) | 1.50 m | 4 Hz | 0.50 s | **2.09 m** | 2.32 | 2.83 |
| can radar, scanning | 0.32 m | 1.1 Hz | 0.60 s | 1.87 | 1.36 | **0.65 m** |
| can radar, locked dither | 0.32 m | 3.1 Hz | 0.20 s | 1.29 | 0.50 | **0.26 m** |

**5× better than the EMA**, and the gate enables it automatically. End to end
through the real detection chain, `radar_twin.py --track` measures **0.12 m RMS
tracking error**.

## What to do about it

1. **Add FTM** (`espfly.md` §4). It is one argument on a `softAP()` call and it
   flips the filter from a downgrade to a 20 % win.
2. Then raise the node count / rate if you want more.
3. The mmWave front end ([`mmwave.md`](mmwave.md)) is where this becomes
   transformative, because Doppler gives velocity without differencing.

**Tier 2 (EKF on raw ranges)** — feeding every RSSI/FTM range into the filter
as it arrives rather than solving a position per window — is the right next
step *after* FTM lands. It handles node dropout and mixes the two ranging types
by their real noise. Validate it in `digital_twin.py` before hardware; that
model already matches the measured ~2 m horizontal accuracy.

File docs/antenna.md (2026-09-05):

# Antenna design and EM simulation

Two candidate custom antennas for the 2.4 GHz FMCW build, and the simulation
methodology that keeps you honest.

```bash
python antenna/horn.py                 # optimum pyramidal horn (recommended)
python antenna/vivaldi.py --array 4    # tapered-slot alternative
```

## Choose the antenna before you model — the workflows diverge

**Horn** is easier to mesh and easier to fabricate accurately, and the
waveguide feed is inherently wideband, which keeps the door open to widening
the VCO sweep later. **Vivaldi** is harder to feed correctly in simulation but
buys more bandwidth. For this build the horn is the recommendation.

## The horn design, and the constraint that trips people up

`antenna/horn.py` implements Balanis' optimum pyramidal horn for a WR-340 feed
at 2.45 GHz:

```
feed guide a x b       : 86.4 x 43.2 mm   TE10 cutoff 1.735 GHz
                                          single-mode to 3.47 GHz (covers 2.31-2.54)
guide wavelength       : 173.3 mm
coax probe             : ~29 mm long, 43 mm (lambda_g/4) from the shorted back wall
aperture a1 (H-plane)  : 263.8 mm
aperture b1 (E-plane)  : 193.1 mm
axial flare length     : pe 91.5 mm | ph 91.5 mm
realizability pe == ph : 0.00 % apart -> geometry closes
predicted gain         : 13.4 dBi
aperture bound 4piA/l^2: 16.3 dBi
aperture efficiency    : 51 %          <- textbook optimum
beamwidths             : ~34 deg E, ~36 deg H
```

**A pyramidal horn is only physically constructible if the E- and H-plane
flares reach the aperture at the same axial length (pe == ph).** The tool
enforces it. Adjust `a1` or `b1` by hand and you must re-solve the other, or
the geometry will not close in CAD — a confusing failure mode if you do not
know to look for it.

The near-symmetric E/H beamwidths are worth having: asymmetric patterns make
clutter behaviour direction-dependent and complicate any later angle work.

That is a 264 × 193 mm aperture, **twice** (TX and RX). If unwieldy,
`--gain 11` shrinks it substantially — note the trade in your log rather than
silently picking small.

## Sanity-check every result against closed form

> **G ≤ 4πA/λ².** An EM solver will happily hand you a gain that violates
> physics if the model is set up wrong, and the aperture bound is the only
> cheap defence.

Write the check into the log explicitly:

> *"Simulated 13.1 dBi, aperture bound 16.3 dBi, 47 % efficiency, plausible."*

That one sentence tells a reviewer more about you than the plot does. (Worked
example of why: a 100 × 85 mm aperture gives 4πA/λ² = 7.1, i.e. **8.5 dBi is
the ceiling at 100 % efficiency** — realistically 5–6 dBi. Any page quoting
14.4 dB from that aperture is describing a different build, or is wrong. A 35°
beamwidth independently implies an aperture nearer 180 mm.)

## HFSS setup

- **Parametrize every dimension as a design variable from the first sketch.**
  Retrofitting variables into a geometry drawn with hard numbers is miserable,
  and you cannot sweep without them.
- λ = 122 mm at 2.45 GHz. **Radiation boundary at λ/2 ≈ 61 mm**, not λ/4 —
  tight boxes wreck back-lobe and cross-pol fidelity and you will chase a
  discrepancy that is purely numerical. PML is better still.
- **Wave port on the actual SMA launch geometry**, de-embedded to the antenna
  reference plane. An idealised port floating in space is the most common
  reason a simulated S11 does not match a VNA.
- *Vivaldi microstrip feed gotcha:* the wave port must be ~8× substrate height
  tall and ~8–10× trace width wide. Too small clips the field, too large
  excites box modes. Both look like a mysteriously bad match.
- **Sheet metal as 2D sheets with a finite-conductivity boundary**, not 3D
  solids. Same physics, far fewer tets.
- **Use the symmetry planes** — the horn has two (Perfect E on one, Perfect H
  on the other). Quarter model, ~4× faster, identical answer.
- Mesh seeding: length-based seeds on the **aperture rim** and the **probe** —
  the two places the field varies fastest and adaptive refinement is slow to
  find on its own.
- FR4 as εr = 4.3, tanδ = 0.02, and **note in the log that FR4 varies 4.2–4.6
  batch to batch** — a predicted source of sim-vs-measured delta. Predicting it
  in advance is worth more than explaining it afterward.
- Adaptive at 2.45 GHz for the horn; **multi-frequency adaptive at 2.0 / 2.45 /
  3.0 GHz for the Vivaldi** — single-point adaptation on a wideband structure
  gives a mesh that is only right mid-band, and the taper edges are exactly
  where you need resolution.
- ΔS = 0.02, minimum two converged passes. Interpolating sweep 2.0–3.0 GHz.
- **Report realized gain, not peak directivity** — mismatch is part of the answer.

### Do the feed in two stages

1. **Horn alone**, waveguide port at the throat. Isolates the flare from the
   feed: realized gain, patterns, phase centre, with nothing confounding.
2. **Coax-to-waveguide transition alone**, shorted section only, wave port on
   the coax. Tune probe length and backshort distance for S11 < −15 dB across
   2.3–2.6 GHz. Two variables, clean parametric sweep.

Then combine and verify. Debugging a bad match in a combined model is miserable
because you cannot tell whether the flare or the launch is at fault.

## The five studies

1. **Convergence.** ΔS vs adaptive pass, and gain vs pass. Prove mesh
   independence before believing any number. One figure that demonstrates you
   know simulation output is not truth.
2. **Parametric sweep** on the two or three dominant dimensions. Prefer
   explicit sweeps over Optimetrics — you want to show you understand *why* the
   geometry moved; a black-box optimizer result is much weaker in a write-up.
3. **Realized gain, pattern cuts, and phase centre.** φ = 0° and 90°, θ from
   −180° to 180° at 1°. **Plot phase-centre position vs frequency across the
   band** — for FMCW this is the study that matters most and the one nobody
   else will have run. A phase centre that walks with frequency smears the beat
   tone and degrades range accuracy; Vivaldis are notorious for it because the
   radiating region moves along the taper.
4. **Two-element coupling.** Both antennas in one model at real spacing;
   extract S21 vs separation. **That coupling term sets your close-in noise
   floor through VCO phase noise** — it is the real limiter, and simulating it
   before cutting metal is the judgement call worth showing. Use FE-BI or the
   hybrid solver for the air between them; filling it with FEM gets expensive
   fast. Re-run with absorber or a metal fence and quantify the improvement.
5. **Optional, if going after angle:** the two-element Rx pair. Simulate
   **embedded** element patterns, not isolated ones — mutual coupling distorts
   each element's pattern, and that distortion is what corrupts the steering
   vector and breaks AoA estimators.

## Validation and documentation

S11 and S21 on a VNA (a LiteVNA is adequate at 2.4 GHz). Pattern cuts need a
range, but a rough outdoor two-mast measurement with a reference antenna gets
within a couple of dB — and writing up *why* it is only within a couple of dB
is itself worth documenting.

Per design iteration, committed as you go with real dates:

- design intent and the **hand calculation** that motivated the geometry
- HFSS parameter table **plus the `.aedt` file**, not just screenshots
- fabrication photos, including what went wrong
- **raw** measured data
- **sim vs measured overlay plot** — the money figure
- a paragraph on the discrepancy and your theory for it

Keep a dated lab notebook alongside. Commit history plus notebook is the
credibility artifact. For the write-up itself: **3–5 pages plus a repo link.**

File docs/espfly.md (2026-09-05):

# ESP-FLY integration (XIAO ESP32-S3 + esp-fc + espnow-rclink)

The mirror of [`espblast.md`](espblast.md) for the ESP-FLY airframe. Same
firmware stack, so that doc applies almost verbatim — **with four differences
that come from the chip and the airframe**, and two corrections to what this
repo previously assumed.

## What changed vs the ESP-BLAST

| | ESP-BLAST (WROOM-32) | **ESP-FLY (XIAO ESP32-S3)** |
|---|---|---|
| FTM ranging | ✗ no hardware | **✓ supported — use it** |
| Barometer | BMP280 | **none — altitude needs a ceiling node** |
| Piggyback beacon board | possible | **no, 25 g airframe** |
| Beacon without patching | needs the alive-interval patch | **free: the AP beacons at ~10 Hz** |

## 1. You get a 10 Hz beacon for free — no firmware patch needed

When esp-fc is built for the S3 with the **built-in ESP-NOW receiver** (the
"SPI Rx" option), it starts an **open access point named `ESP-FC` at boot and
leaves it up during flight** (`Wireless.cpp:9-25`). That AP radiates standard
802.11 beacons at roughly **10 Hz**, which the sniffer nodes can track with no
patch at all. The arming lockout applies only to the separate rescue-config
WiFi mode, not to this AP.

The espnow-rclink link itself is *not* a good beacon: v0.1.1 sends pair
requests at 20 Hz **before** pairing and then only a **1 Hz keepalive** in
flight (`Protocol.h`). So the AP beacons are what you actually track.

Want more than 10 Hz? The one-line alive-interval patch from `espblast.md`
still works and stacks on top (→ 25 Hz). It is now **optional**, not required.

## 2. You must fly on ESP-NOW — ELRS is untrackable

With an **external ELRS receiver, esp-fc never brings WiFi up at all**, and the
ELRS link itself is LoRa, which an ESP32 sniffer cannot decode. There is
nothing for the ground network to hear.

> **If you want the passive radar to work, fly the ESP-NOW link.**
> This directly reverses the recommendation in `mit-radar.md` §0, which said to
> move to 915 MHz ELRS to keep the *active* radar from jamming the control
> link. Both statements are true — they just belong to different systems:
> - **passive RF tracking → must use ESP-NOW** (you need something to hear)
> - **active 2.4 GHz FMCW radar → must leave 2.4 GHz** (or it jams you)
>
> You cannot run the 2.4 GHz coffee-can radar and the ESP-NOW tracker at the
> same time on the same drone. Pick one per flight, or move the active radar
> to 60 GHz (see [`mmwave.md`](mmwave.md)), which removes the conflict entirely
> because it neither needs nor disturbs the 2.4 GHz band.

## 3. Channel is 1, not 7

The rclink receiver adopts whatever channel the softAP is on, and esp-fc's
Arduino `softAP()` call uses the **default, channel 1** — not the channel 7
this repo previously assumed. `firmware/rx_node/rx_node.ino` now defaults to 1.

**Always confirm with `firmware/mac_scanner` before flashing the sniffers.**

## 4. FTM is real on this drone — and it is the accuracy step that matters

The S3 has the FTM hardware and esp-fc already runs a softAP, so enabling the
responder is **one extra argument on that `softAP()` call** in `Wireless.cpp`.
`firmware/rx_node_ftm/` then ranges against the `ESP-FC` network directly,
giving **time-of-flight distance with no RSSI calibration at all**.

This is not a nice-to-have. Measured in `ground_station/tracker.py`, moving
from RSSI (~1.5 m) to FTM (~0.6 m) is the step that makes the tracking filter
worth switching on — see [`tracking.md`](tracking.md).

## 5. No barometer → put a node on the ceiling

The ESP-FLY has no baro, so the trick used in `3d-sensing.md` (take altitude
from the drone) is unavailable. Altitude has to come from the geometry, and
**coplanar nodes cannot measure it**. The fix is one node out of the plane:

```
3 floor nodes at 0.3 m + 1 CEILING node at 2.6 m, 5 x 6 m room:
   drone at 0.8 m -> sigma_h 1.94 m, sigma_v 0.70 m
   drone at 1.2 m -> sigma_h 2.01 m, sigma_v 0.54 m   <- checkpoint: < 1 m PASS
   drone at 2.0 m -> sigma_h 2.30 m, sigma_v 0.23 m
```

That layout is now the default in `ground_station/config.json`, with
`solve_3d: true`. Verify your own room with:

```bash
python ground_station/geometry.py          # sigma_h / sigma_v for your layout
```

## Parts (indoor 5 × 6 m room, ~$85)

Drone side: nothing new — XIAO ESP32-S3, kit antenna, RP1 V2, T8L, and a
patched esp-fc build.

| Item | Qty | ~$ | Why |
|---|---|---|---|
| ESP32-S3 dev board w/ u.FL (XIAO S3 fine) | 5 | 30 | 4 sniffers + 1 hub; S3 gives RSSI **and** FTM |
| 2.4 GHz u.FL dipole | 4 | 8 | steadier than PCB antennas; mount all vertical |
| USB-C cables + 5 V wall adapters | 5 | 15 | indoors, mains beats power banks |
| Ceiling mount (adhesive hook/strip) | 1 | 3 | **this is what makes altitude solvable** |
| Small tripods/stands | 3 | 10 | floor nodes at ~0.3 m in three corners |
| Laser distance meter | 1 | 20 | anchor error goes straight into the fix |

## Build order (each step has a checkpoint — don't skip them)

1. **Patch and build esp-fc.** In `Wireless.cpp`: start the AP unconditionally
   rather than only for the ESP-NOW receiver; pass the **FTM responder flag**
   to `softAP()`; drop WiFi TX power to ~8 dBm (nodes are within 10 m).
   Optionally add a 25 Hz ESP-NOW broadcast beacon in the main loop, copied
   from `firmware/drone_beacon`. Build/flash with PlatformIO, `esp32s3` target.
   **Checkpoint:** `mac_scanner` shows one MAC at the expected rate, and T8L
   link quality is unchanged with the AP up.
2. **Flash the ground network.** Hub first, note its MAC. Then four `rx_node`
   boards with unique IDs, the drone's **AP MAC** (from esp-fc's CLI `wifi`
   command), the hub MAC, and the scanned channel (probably 1).
   **Checkpoint:** the hub prints a JSON line from every node every ~250 ms.
3. **Add FTM ranging.** Flash `rx_node_ftm` with SSID `ESP-FC`, open network.
   Worth doing: forward FTM distances to the hub over ESP-NOW like the RSSI
   nodes, so a ceiling node doesn't need its own USB run.
   **Checkpoint:** printed distance matches a tape measure within 1 m at 3 m.
4. **Lay out and calibrate.** Three floor corners at 0.3 m, one on the ceiling
   above the flight area centre. Measure every position **including z** into
   `config.json`. Calibrate each node's 1 m reference RSSI with the drone on
   USB power sitting on a box — *not in your hand*.
   **Checkpoint:** `geometry.py` reports vertical sigma < 1 m at room centre.
5. **Run the console.** `python ground_station/server.py`, open
   <http://localhost:8080>. Hover in the middle of the room first.

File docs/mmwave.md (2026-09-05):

# mmWave front end (TI IWR6843) — buying the radar instead of building it

The honest summary of the trade: **a bigger drone does not rescue the passive
reflection idea; buying an active mmWave sensor does, and it makes the whole
beacon problem disappear.**

## Why size is not the binding constraint

RCS scales with the airframe, so a bigger drone does echo louder — about 18 dB
from the ESP-FLY to a metre-span hex. Not enough, and not the real problem:

| drone | RCS | echo below the direct path at 5 m |
|---|---|---|
| ESP-FLY, 67 mm | 0.005 m² | 48 dB |
| 5-inch freestyle | 0.02 m² | 42 dB |
| 450-class / 7-inch | 0.08 m² | 36 dB |
| large hex, 1 m | 0.30 m² | 30 dB |

Two things kill it regardless of size. The **direct signal still swamps the
echo by 30 dB even on the biggest airframe.** And **range resolution comes from
bandwidth alone**: a 20 MHz WiFi illuminator is a 7.5 m range cell no matter
what is flying in it — your ELRS link, under 1 MHz, is a 150 m cell. A bigger
target changes neither number, and gets flown further away, where the echo
ratio falls as the fourth power of range.

## What an active mmWave sensor changes

All three objections dissolve at once. **You control the transmitter**, so
there is no uncooperative direct path to cancel. A 60 GHz chip sweeps **4 GHz**
of bandwidth — a **3.7 cm** range cell instead of 7.5 m. And it costs a few
hundred dollars, not the $500+ a coherent passive front end needs.

Detection range from the radar equation at 13 dB minimum SNR:

| sensor | ESP-FLY | 5-inch | 450-class | large hex |
|---|---|---|---|---|
| **TI IWR6843, 60 GHz** | **13 m** | 19 m | 27 m | 37 m |
| TI AWR1843, 77 GHz | 13 m | 19 m | 27 m | 37 m |
| Infineon BGT60 | 7 m | 10 m | 13 m | 19 m |

Your current 25 g drone is trackable to ~13 m, which covers an indoor room.

**On angles, keep resolution and accuracy separate.** Angular *resolution* is
coarse (~14° azimuth) and only matters if you need to separate two drones
flying close together. For locating **one** drone, *accuracy* is what counts:
~**0.6°** at 20 dB SNR, which is **11 cm of cross-range error at 10 m**.
Combined with centimetre range accuracy that is roughly **10× better than the
RSSI system**.

There is also a clean signature to lock onto: spinning props put the blade tips
at ~110 m/s, which at 60 GHz is a **44 kHz Doppler shift**. Nothing else in a
room does that, so static clutter from walls and furniture drops out easily.

And the part that should appeal most: **it sees the airframe itself.** No
beacon, no MAC filter, no esp-fc patch, no choosing between ELRS and ESP-NOW to
keep WiFi alive. The whole ESP-NOW-vs-ELRS constraint in
[`espfly.md`](espfly.md) §2 stops applying.

## What to buy

**IWR6843AOPEVM.** The antenna is on the package, so there is nothing to build,
it runs off USB, and it streams a 3D point cloud over serial from the stock
demo. Critically it has a **wide field of view in both azimuth and elevation** —
the cheaper ISK variant is only ~30° in elevation and would give you poor
altitude, which is precisely the axis you are already short of.

Typical price for these evaluation modules is **$200–350**; I could not confirm
today's figure (DigiKey blocked the fetch), so check before ordering.
**Skip the $30 presence-detection modules** — they do not expose enough raw
data to track anything.

## What survives the swap

Most of the repo. The web console, the scope, node health cards, session
recording, the geometry tools and the tracking filter all work on **any** source
of 3D fixes. What changes is only the front end:

| layer | today | with mmWave |
|---|---|---|
| sensing | 4 sniffer nodes | the module itself, on USB |
| fixes | multilateration solver | serial reader parsing the point cloud + clustering to pick the drone out of the returns |
| hub | ESP32 hub board | the radar |
| filter | gated off (see `tracking.md`) | **the filter comes into its own** — Doppler gives velocity directly, 8× better |

**Keep the RF system rather than deleting it.** Two independent sensors that
fail in different ways is a genuinely better tracker, and the existing code
already fuses multiple range sources.

## On eventually building your own

Be clear which part you mean. Designing a 60 GHz front end from scratch means
Rogers substrate, sub-millimetre antenna tolerances and RF layout that is hard
to get right without lab equipment. The realistic build is **your own carrier
board and antenna array around a bare module, plus your own signal processing
replacing the TI demo** — which is where the interesting work is anyway.

If you want the from-first-principles experience, that is exactly what
[`mit-radar.md`](mit-radar.md) is for. It is excellent for learning, but its
narrow sweep gives ~1–1.8 m of range resolution, so **it will not beat the
module you bought.** Build it to understand radar; buy the module to track the
drone.

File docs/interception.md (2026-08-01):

# Two-drone interception — architecture & build plan

**Goal:** one ESP-BLAST drone (the *interceptor*) autonomously flies to a
second ESP-BLAST (the *target*), located by the passive-RF radar.

This document is the end-to-end design. The firmware/API claims were verified
against primary source (esp-fc `@master`, espnow-rclink `@main`); the
performance numbers were verified empirically in `ground_station/pursuit_sim.py`.

---

## 1. The core problem: a single point can't find a bearing
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

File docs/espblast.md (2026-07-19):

# Integrating with the ESP-BLAST (Max Imagination's ESP32 rocket drone)

This guide adapts the localization system to the specific hardware and
firmware of the ESP-BLAST build:

- **MCU: ESP32-WROOM-32** (original ESP32) on a custom 4-layer FC PCB,
  u.FL external antenna mod
- **Flight firmware: ESP-FC** (`rtlopez/esp-fc`), compiled and flashed by you
  with PlatformIO (`pio run -e esp32 -t upload`)
- **RC link: ESP-NOW** via the `EspNowRcLink` library (`rtlopez/espnow-rclink`),
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

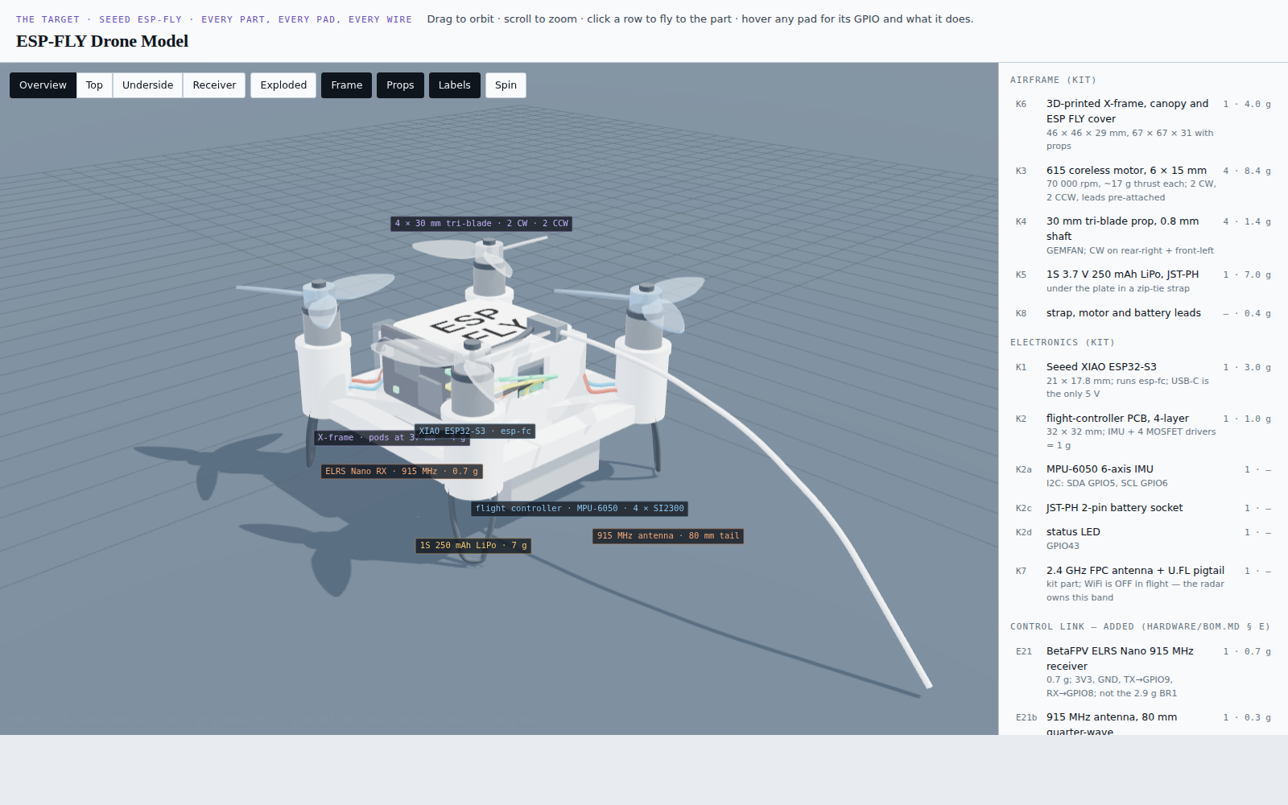
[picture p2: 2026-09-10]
3d/renders/drone/overview.png

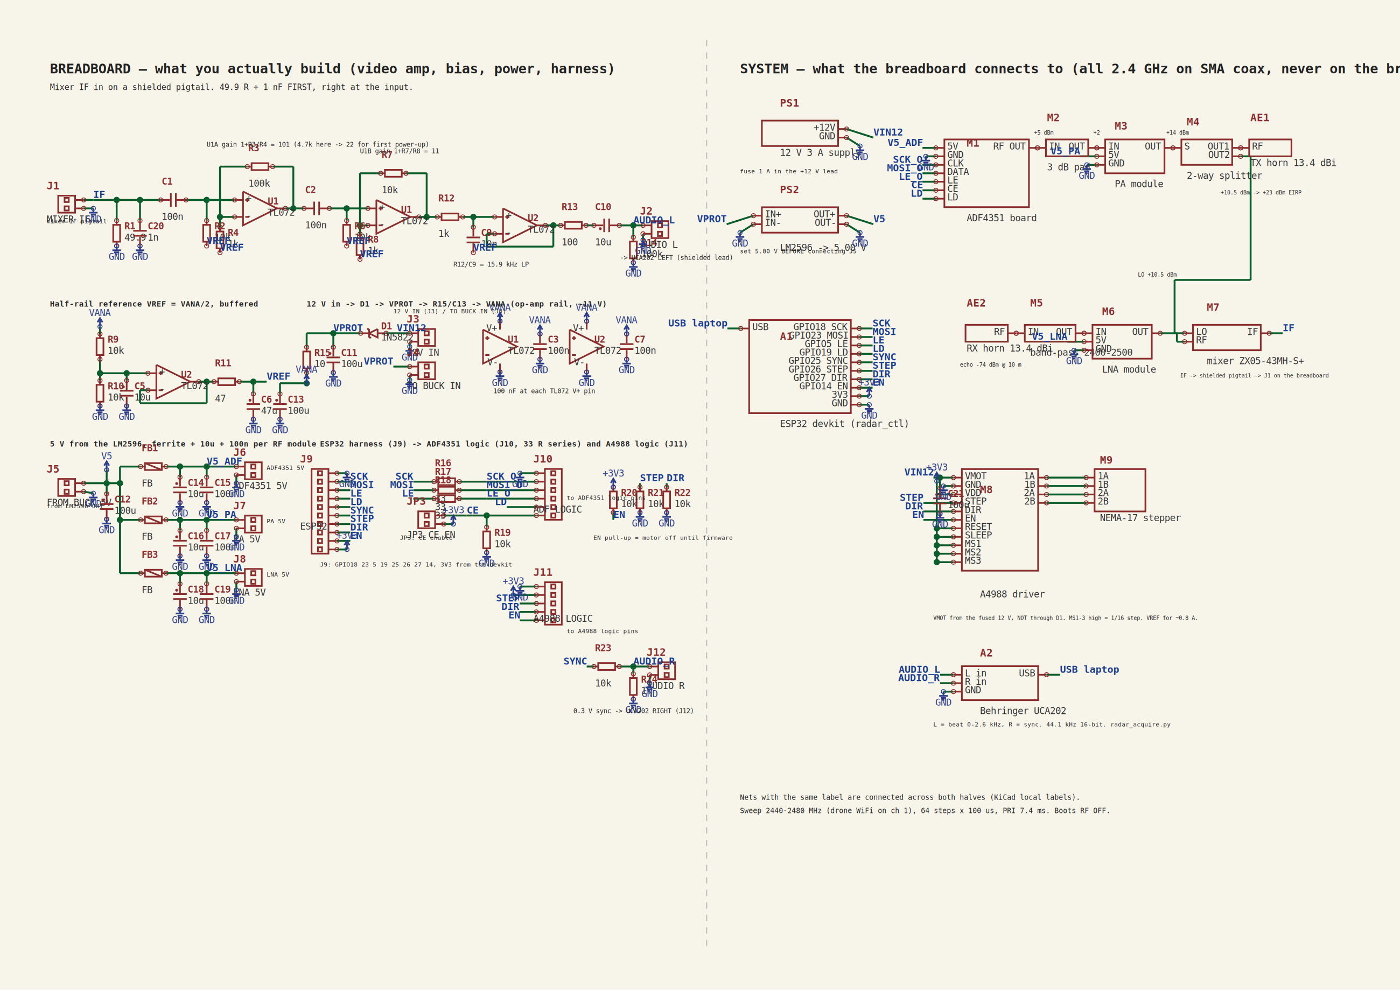
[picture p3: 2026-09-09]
breadboard/schematics/radar_breadboard.png

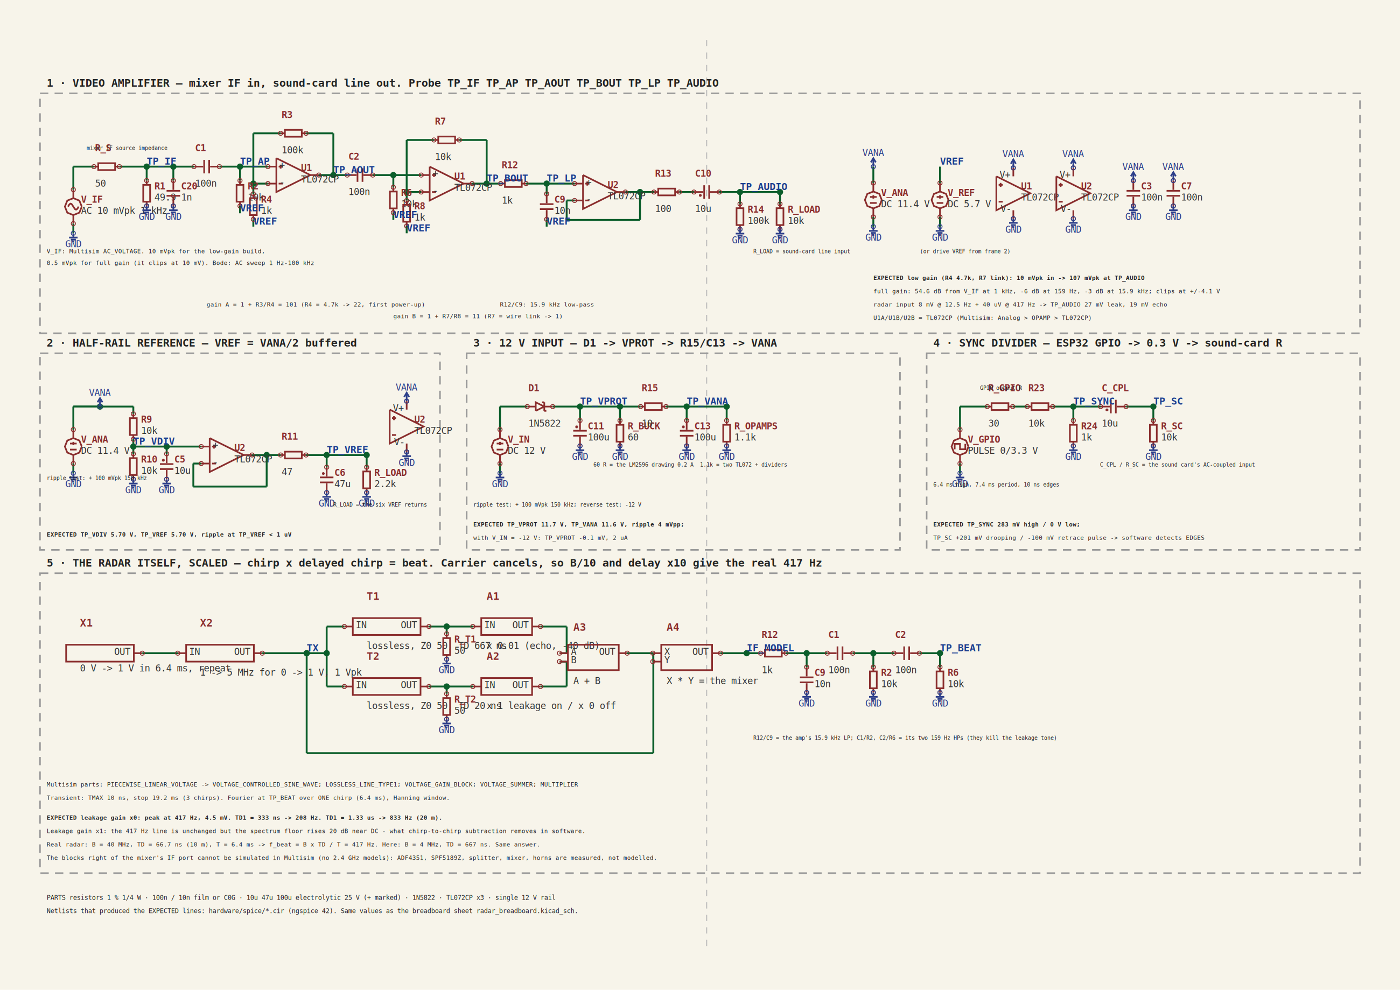
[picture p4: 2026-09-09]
breadboard/schematics/radar_multisim.png

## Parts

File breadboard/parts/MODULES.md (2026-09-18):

# Chips and modules — real pinouts

Generated by `gen_page.py` on the `dev` branch. Boards seen from above, antenna / SMA / trimpot at the top, USB at the bottom.
`hole` is the breadboard hole the signal must reach (ohm-meter check from the module pin).

## TL072CP (DIP-8)

Notch and pin-1 dot toward the higher column (right). Top row reads 4 3 2 1 left→right, bottom row 5 6 7 8.

| pin | function | U1 hole | U2 hole |
|---|---|---|---|
| 1 | OUT A | e8 | e33 |
| 2 | IN- A | e7 | e32 |
| 3 | IN+ A | e6 | e31 |
| 4 | V- | e5 | e30 |
| 5 | IN+ B | f5 | f30 |
| 6 | IN- B | f6 | f31 |
| 7 | OUT B | f7 | f32 |
| 8 | V+ | f8 | f33 |

## ESP32 DevKit V1 (DOIT, 30-pin)

Pins 2.54 mm apart, rows 0.9 in apart. This is the usual '$10 ESP-WROOM-32 devkit'. Power it over USB from the laptop (serial link); VIN is optional.

| left, top→bottom | | right, top→bottom | |
|---|---|---|---|
| EN |  | **D23** | MOSI → J9 pin 3 — j46 |
| VP (36) |  | D22 |  |
| VN (39) |  | TX0 (1) |  |
| D34 |  | RX0 (3) |  |
| D35 |  | D21 |  |
| D32 |  | **D19** | LD ← J9 pin 5 — j48 |
| D33 |  | **D18** | SCK → J9 pin 2 — j45 |
| **D25** | SYNC → J9 pin 6 — j49 | **D5** | LE → J9 pin 4 — j47 |
| **D26** | STEP → J9 pin 7 — j50 | TX2 (17) |  |
| **D27** | DIR → J9 pin 8 — j51 | RX2 (16) |  |
| **D14** | EN → J9 pin 9 — j52 | D4 |  |
| D12 |  | D2 |  |
| D13 |  | D15 |  |
| **GND** | GND → J9 pin 1 — j44 | **GND** | GND → J9 pin 1 — j44 |
| **VIN** | 5 V in from LM2596 #1 (optional; USB powers it) | **3V3** | 3.3 V out → J9 pin 10 — j53 |

## ESP32-DevKitC V4 (38-pin)

Espressif's own board. Rows 1.0 in apart: it covers a whole breadboard bank, so keep it on the harness, not the board.

| left, top→bottom | | right, top→bottom | |
|---|---|---|---|
| **3V3** | 3.3 V out → J9 pin 10 — j53 | **GND** | GND → J9 pin 1 — j44 |
| EN |  | **D23** | MOSI → J9 pin 3 — j46 |
| VP (36) |  | D22 |  |
| VN (39) |  | TX0 (1) |  |
| D34 |  | RX0 (3) |  |
| D35 |  | D21 |  |
| D32 |  | **GND** | GND → J9 pin 1 — j44 |
| D33 |  | **D19** | LD ← J9 pin 5 — j48 |
| **D25** | SYNC → J9 pin 6 — j49 | **D18** | SCK → J9 pin 2 — j45 |
| **D26** | STEP → J9 pin 7 — j50 | **D5** | LE → J9 pin 4 — j47 |
| **D27** | DIR → J9 pin 8 — j51 | D17 |  |
| **D14** | EN → J9 pin 9 — j52 | D16 |  |
| D12 |  | D4 |  |
| **GND** | GND → J9 pin 1 — j44 | D0 |  |
| D13 |  | D2 |  |
| SD2 (9) |  | D15 |  |
| SD3 (10) |  | SD1 (8) |  |
| CMD (11) |  | SD0 (7) |  |
| **5V** | 5 V in from LM2596 #1 (optional; USB powers it) | CLK (6) |  |

## A4988 stepper driver (Pololu pinout)

Seen from above with the trimpot at the top. MS1–MS3 all to VDD = 1/16 microstep (STEPS_PER_DEG 8.889). Tie RESET to SLEEP. Set the trimpot for about 0.8 A before connecting the motor.

| left, top→bottom | | right, top→bottom | |
|---|---|---|---|
| **ENABLE** | EN ← J11 pin 5 (10 k pull-up: off at boot) — j62 | **VMOT** | 12 V supply +, 100 µF (C21) right at the pins |
| **MS1** | → VDD (1/16 step) | **GND (motor)** | 12 V supply − |
| **MS2** | → VDD | **2B** | NEMA-17 coil B |
| **MS3** | → VDD | **2A** | NEMA-17 coil B |
| **RESET** | → SLEEP (wire link) | **1A** | NEMA-17 coil A |
| **SLEEP** | → RESET | **1B** | NEMA-17 coil A |
| **STEP** | STEP ← J11 pin 3 — j60 | **VDD** | 3.3 V ← J11 pin 2 — j59 |
| **DIR** | DIR ← J11 pin 4 — j61 | **GND (logic)** | ← J11 pin 1 — j58 |

## ADF4351 PLL board (SMA out, 25 MHz TCXO)

The eBay/Amazon boards share these pin NAMES but not their order on the header — match by the silkscreen label, not by position. Logic is 3.3 V, so the ESP32 drives it directly (33 Ω in series).

| pin | goes to | hole |
|---|---|---|
| VCC / 5V | ← J6 pin 1 (V5_ADF, through FB1) | d38 |
| GND | ← J6 pin 2 / J10 pin 1 | d39 |
| CLK | ← J10 pin 2 SCK_O | a53 |
| DATA | ← J10 pin 3 MOSI_O | a54 |
| LE | ← J10 pin 4 LE_O | a55 |
| CE | ← J10 pin 6 (JP3 to 3.3 V) | a57 |
| LD | → J10 pin 5 (lock detect) | a56 |
| MUX | leave open |  |

## Behringer UCA202 (rear panel)

Both breadboard audio outputs go to the RCA INPUT pair. Input switch to LINE. Monitor off. 48 kHz / 16-bit in the OS, every 'enhancement' off.

| pin | goes to | hole |
|---|---|---|
| INPUT L (white) | ← J2 pin 1 AUDIO_L (beat signal) | f36 |
| INPUT L shell | ← J2 pin 2 GND | f37 |
| INPUT R (red) | ← J12 pin 1 AUDIO_R (0.3 V sync) | d63 |
| INPUT R shell | ← J12 pin 2 GND | d62 |

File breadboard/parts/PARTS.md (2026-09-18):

# Stockroom pick list

Generated by `gen_parts.py` from `layout.json` (both on the [`dev` branch](https://github.com/dpaulb005/radar-dev-/tree/dev/hardware/breadboard)) — the same placement `WIRING.md` and `ASSEMBLY.md` come from, so the counts cannot drift from the build.

**Take** includes spares. Passives are free or nearly free at a university stockroom and breadboard leads bend, so carry a few extra of everything cheap. The substitute column is what to do if the drawer is empty.

## Resistors — ¼ W

| value | need | take | substitute? | refs |
|---|---|---|---|---|
| **10k** | 10 | 14 | **no** — gain, bias, and the half-rail divider. R9 and R10 want to match each other | R2, R6, R7, R9, R10, R19, R20, R21, R22, R23 |
| **1k** | 4 | 6 | **no** — sets amplifier gain with the 100 k | R4, R8, R12, R24 |
| 33 | 3 | 5 | 22–68 Ω fine | R16, R17, R18 |
| **100k** | 2 | 3 | **no** — sets gain with the 1 k | R3, R14 |
| 10 | 1 | 2 | 10–22 Ω fine | R15 |
| 100 | 1 | 2 | 68–150 Ω fine | R13 |
| 47 | 1 | 2 | 47–100 Ω fine | R11 |
| **49.9** | 1 | 2 | **want 1 %** — this is the mixer IF termination. 47 Ω 5 % works if that is all there is | R1 |

## Capacitors — ceramic

| value | need | take | substitute? | refs |
|---|---|---|---|---|
| 100n | 5 | 8 | any; all of these are decoupling | C3, C7, C15, C17, C19 |
| **10n** | 1 | 2 | **value matters** — sets the 15.9 kHz anti-alias corner with R12. C0G or film | C9 |
| 1n | 1 | 2 | any; C0G nicest | C20 |

## Capacitors — film

| value | need | take | substitute? | refs |
|---|---|---|---|---|
| **100n** | 2 | 3 | **must be film, not ceramic** — signal path | C1, C2 |

## Capacitors — electrolytic

| value | need | take | substitute? | refs |
|---|---|---|---|---|
| 10u | 5 | 7 | any ≥ 16 V | C10, C5, C14, C16, C18 |
| **100u** | 3 | 4 | **≥ 25 V** — two of these sit on the 12 V rail | C11, C13, C12 |
| 47u | 1 | 2 | any ≥ 16 V | C6 |

## Diodes

| value | need | take | substitute? | refs |
|---|---|---|---|---|
| 1N5822 | 1 | 2 | any 1–3 A Schottky, ≥ 30 V | D1 |

## Ferrite beads

| value | need | take | substitute? | refs |
|---|---|---|---|---|
| FB | 3 | 4 | any through-hole ferrite bead | FB1, FB2, FB3 |

## Integrated circuits

| value | need | take | substitute? | refs |
|---|---|---|---|---|
| **TL072CP** | 2 | 3 | **DIP-8 package.** TL072, TL072C or TL082 all fit | U1, U2 |

## Headers

| strip | qty | on |
|---|---|---|
| 2-pin | 10 | J1, J2, J3, J4, J5, J6, J7, J8, JP3, J12 |
| 5-pin | 1 | J11 |
| 6-pin | 1 | J10 |
| 10-pin | 1 | J9 |

41 header pins in 13 strips. Cut them from a 40-pin strip.

## Also on the list

| item | take | note |
|---|---|---|
| 4.7 k resistor | 2 | R4 takes 4.7 k for gain 22 on first power-up, then 1 k for full gain |
| 0.1″ male header strip, 40-pin | 2 | snap to length |
| 830-point breadboard | 1 |  |

## Jumper wire

Solid-core 22 AWG, 48 links in total:

| colour | links |
|---|---|
| black | 17 |
| green | 9 |
| red | 5 |
| violet | 5 |
| blue | 4 |
| brown | 3 |
| orange | 2 |
| yellow | 2 |
| pink | 1 |

## What not to compromise on

Everything marked **bold** above sets a gain, a corner frequency or a termination. Taking "something close" there changes the circuit rather than the parts list:

- the two **film** 100 nF are the high-passes in a 61 dB amplifier; ceramics there are microphonic and have a voltage coefficient
- the **1 k / 10 k / 100 k** set the gain and the half-rail reference — if the stockroom has 1 %, take those
- the **49.9 Ω** is the mixer's IF load; without it conversion loss and flatness wander
- a **DIP** TL072: stockrooms usually have them loose, distributors increasingly do not

And the thing actually worth borrowing while you are in the building is a **VNA that reaches 2.5 GHz** — a ~$165 instrument you need for twenty minutes, against which this whole list is rounding error. `docs/radar-hardware.md` on the `dev` branch covers what to measure with it.

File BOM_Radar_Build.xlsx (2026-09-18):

Component | Price ($) | Link | Description
A. RF Chain
ZX05-43MH-S+ mixer | 79.31 | Link (https://www.digikey.com/en/products/detail/mini-circuits/ZX05-43MH-S/21727733) | Would like to find substitute expensive and on back order (generic version?) 1.5 - 4.2GHz
ADF4351 PLL Board | 28.32 | Link (https://us.amazon.com/Frequency-Synthesizer-Development-Generator-35M-4-4GHz/dp/B0BCWVHFT1)
SPF5189Z LNA | 11.81 | Link (https://www.amazon.com/SPF5189Z-50-4000MHz-Ultra-Wideband-Wireless-Communication/dp/B0H4CH543K)
2-way SMA Splitter | 24.56 | Link (https://us.amazon.com/Splitter-380mhz-2500MHz-Female-Divider-Signal/dp/B0HD9L81N2?s=industrial) | 380-2500MHz
SMA 3dB attenuator | 12.99 | Link (https://www.amazon.com/clp/B0B93NB895) | DC-6/8GHz (2 pack)
SMA M-M RG316 | 11.97 | Link (https://www.amazon.com/Superbat-Connector-Coaxial-Antenna-Analyzer/dp/B0BFPWJ3J9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)
SMA Adapters | 12.96 | Link (https://www.amazon.com/ALLiSHOP-Connectors-Connector-Goldplated-Connectivity/dp/B07Z2QB9M8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)
2.4GHz BPF | 29.1 | Link (https://gpio.com/products/2450-mhz-ism-bandpass-filter-for-wifi-zigbee-and-bluetooth)
B. Horns
Copper Sheet 24ga | 88 | Link (https://www.amazon.com/Copper-Sheet-Metal-Material-Size/dp/B092MXPMYK?th=1) | Not sure if I need this much (Check)
SMA Female 4-hole flange | 7.99 | Link (https://www.amazon.com/Female-Chassis-Connector-Straight-Shipping/dp/B09MVYNZ29?th=1)
Brass Rods | 5.79 | Link (https://www.amazon.com/Solid-Rod-16-Brass-Pack/dp/B009YO48LK)
60/40 Solder + Paste Flux |  | ?
Aviation Snips/Sheet Nibbler |  | ?
C. Baseband, Control, Power
Behringer UMC404HD | 139 | Link (https://www.amazon.com/BEHRINGER-Audio-Interface-4-Channel-UMC404HD/dp/B00QHURLHM) | This is so I dont have to use an SDR to process the thought is downconversion into a beat pattern and then you process a beat pattern with an audio mixer, if you have one that would be huge
LM2596 Buck | 7.99 | Link (https://www.amazon.com/Converter-Adjustable-Regulator-Voltmeter-Display%EF%BC%88Pack/dp/B0F1M2SR31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)
Resistor + Caps | 0 | Steal from stock room lol
Plywood |  |  | To mount everything idk where ill get it from
D. 915 MHz Control |  |  | Only giving the radar 20Mhz of wiggle room isnt ideal so this will let me control the drones at 915Mhz
RadioMaster Pocket | 65 | Link (https://radiomasterrc.com/products/pocket-radio-controller-m2) | Also Amazon/Ebay
Bandit Nano 915Mhz ELRS | 40 | Link (https://radiomasterrc.com/products/bandit-nano-expresslrs-rf-module) | Ebay
BetaFPV ELRS 915Mhz Nano Rx | 10 | Link (https://betafpv.com/products/elrs-nano-receiver)

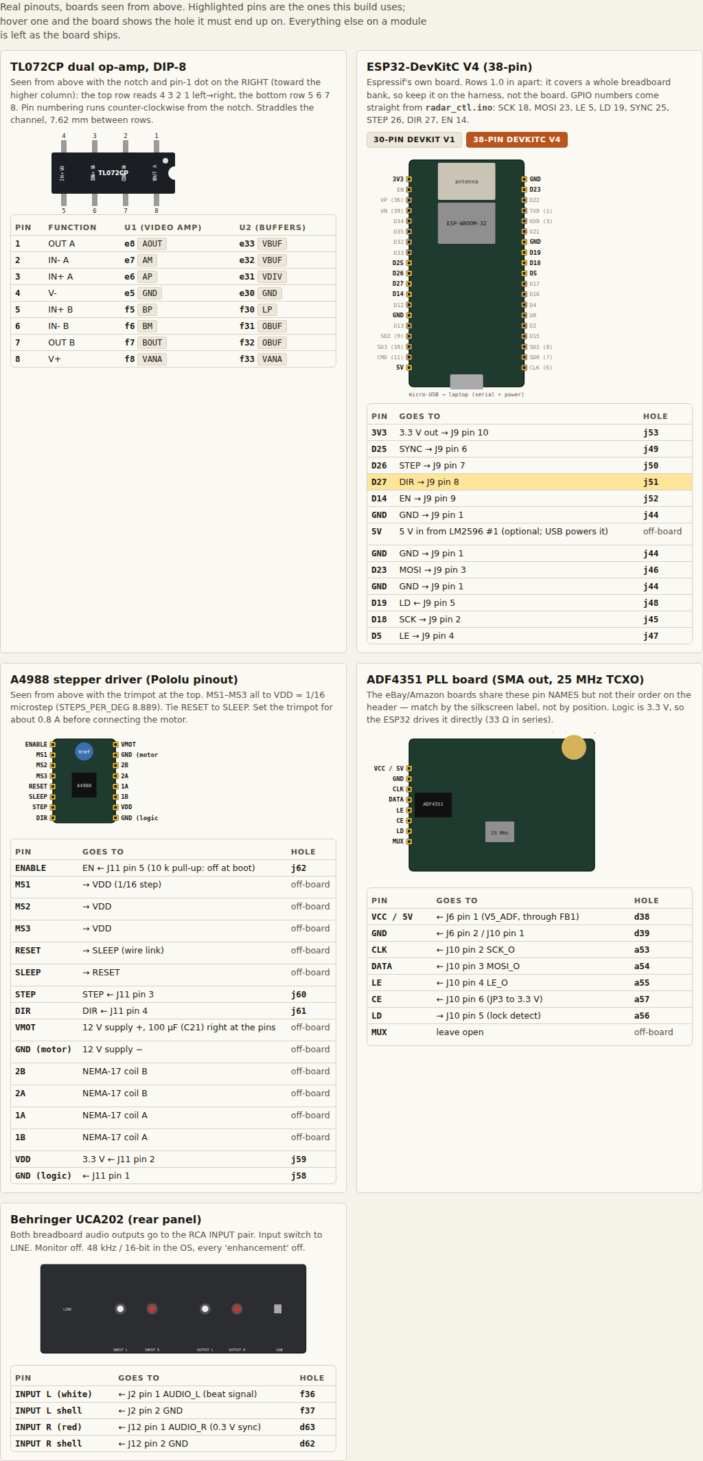
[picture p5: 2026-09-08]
breadboard/parts/modules.png

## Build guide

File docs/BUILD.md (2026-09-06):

# Master build guide — full two-drone interception system

> **Superseded for the current scope.** The active-radar build is now
> documented step by step in [`radar-hardware.md`](radar-hardware.md),
> [`radar-software.md`](radar-software.md), [`drone-hardware.md`](drone-hardware.md)
> and [`drone-software.md`](drone-software.md). This page is the passive
> two-drone plan and is kept for the interception stages (E–H), which still
> apply once the radar tracks.

Everything needed to go from parts to a working system where one ESP-BLAST
drone is flown by the ground radar to another. This is the index that ties the
detailed docs together:

- Drone integration specifics → [`espblast.md`](espblast.md)
- Radar bring-up detail → [`SETUP.md`](SETUP.md)
- Interception architecture & guidance → [`interception.md`](interception.md)
- Why RSSI (not reflection radar / mmWave) → [`feasibility.md`](feasibility.md)
- Priced radar parts table → [`../hardware/BOM.md`](../hardware/BOM.md)

---

## 1. Complete hardware list

Prices are typical US street prices (mid-2026). "You have it" = part of your
existing drone build or bench.

### 1a. The two aircraft — 2 × ESP-BLAST, **built without FPV**

You need **two** drones: a *target* and an *interceptor* (identical builds).
Follow the ESP-BLAST Instructable, but omit the FPV chain. Per drone:

| Item | Notes |
|---|---|
| Custom flight-controller PCB | JLCPCB, ~$7 for 5 boards; carries the ESP32 |
| ESP32-WROOM-32 module | the flight controller MCU (do the u.FL antenna mod for range) |
| MPU9250 9-axis IMU | gyro+accel+**magnetometer** — the mag is needed later for heading downlink |
| BMP280 barometer | enables ESP-FC's baro altitude-hold |
| 4 × JMT HLK-DL03 8A ESC | brushless motor drivers |
| 4 × 1104 brushless motors + 2.5″ props | |
| 3S LiPo + XT30, 3.3 V regulator, caps | power |
| Buzzer, 30 AWG silicone wire, PETG frame | |
| GPS module | **optional** — not used for interception (the radar provides position); keep only if you want it as a sensor |
| ~~FPV camera, MinimOSD, tilt servo, 5.8 GHz VTX~~ | **OMIT — no FPV.** Saves cost, weight, and complexity |

**~$115–125 per drone without FPV → ~$230–250 for both.**

### 1b. Radio control for the drones

| Item | Qty | Unit | Notes |
|---|-----|---|---|
| Handheld ESP-NOW transmitter (ESP32) | 1 | ~$15 | Flies the **target** manually (the ESP-BLAST "Radio Controller"). Also your manual-flight tool during bring-up. |
| **Commander ESP32 dev board** | 1 | $6 | Flies the **interceptor** — it's the ground station's radio (`firmware/commander`). |

The interceptor is flown *only* by the commander (binding is exclusive — see
§3 of `interception.md`). You do not need a second handheld.

### 1c. Ground radar sensor network (~$56)

| Item | Qty | Unit | Notes |
|---|-----|---|---|
| ESP32-S3 / C3 dev board (IPEX antenna) | 4 | $6 | 3 sniffer nodes + 1 hub |
| 2.4 GHz dipole antenna, u.FL | 3 | $2 | vertical, same polarization on all nodes |
| USB power bank (small 5 V) | 3 | $5 | powers the field nodes |
| USB-C cables | 5 | $2 | flashing + hub + commander |
| Tripods / stakes / zip ties | 3 | ~$1 | node antennas ~1 m up, positions measured |

Add a **4th sniffer** ($6) for better geometry / robustness — the solver uses
however many report in.

### 1d. Ground station + test safety gear

| Item | Notes |
|---|---|
| Laptop | runs `ground_station/` (Python 3.10+, Arduino IDE / PlatformIO) — you have it |
| **Net / cage / tethers** | non-negotiable for two-aircraft convergence tests |
| Prop guards ×2 sets, eye protection | |
| LiPo charging bag, tape measure (to ~10 cm) | |

### System total

| Subsystem | Cost |
|---|---|
| 2 × ESP-BLAST (no FPV) | ~$230–250 |
| Handheld TX + commander | ~$21 |
| Ground radar network | ~$56 |
| Test safety gear | ~$30–60 |
| **Total** | **~$340–390** |

The drones dominate the cost; the entire radar + interception add-on is
under ~$80. Not needed: SDRs, directional antennas, LNAs (see `feasibility.md`).

---

## 2. Build steps, in order (each ends with a checkpoint)

### Stage A — Build & fly both drones (no FPV)
Build both ESP-BLAST airframes per the Instructable through the flight-controller
steps, omitting the FPV camera/OSD/VTX/servo. Flash ESP-FC to each; in the
configurator set conservative angle/rate/throttle limits and **RC-loss →
disarm**. Bind each to the handheld and fly manually (props on, open area).
**Checkpoint A:** both drones arm, self-level in ANGLE mode, and fly under
manual control; RC-loss disarms them.

### Stage B — Make both drones trackable
Both the target *and* the interceptor must emit frames fast enough to track.
Apply the one-line ESP-FC patch (`LINK_ALIVE_INTERVAL_MS` 1000 → 40) to both, as
in [`espblast.md`](espblast.md). Record each drone's MAC and the link channel
(default 7) with `firmware/mac_scanner`.
**Checkpoint B:** `mac_scanner` shows both drones at ~25 Hz on the same channel;
you have both MACs written down.

### Stage C — Build & calibrate the ground radar
Flash `firmware/hub_node` (note its MAC) and 3–4 `firmware/rx_node` sniffers
(set each `NODE_ID`, the drone MAC, `HUB_MAC`, channel). Place the nodes in a
≥6 m triangle around the flight box, antennas vertical ~1 m up; measure each
position. Run `ground_station/server.py`, enter node positions (drag in EDIT
LAYOUT), connect the hub, calibrate each node with the wizard. Detail in
[`SETUP.md`](SETUP.md).
**Checkpoint C:** with one drone powered, its blip tracks within ~1–2 m of truth
inside the triangle; solver ~4 Hz.

### Stage D — Track both drones at once
Extend the tracker to separate the two drones by source MAC and solve each
independently (today the pipeline follows one target). This is the main
software task remaining before flight.
**Checkpoint D:** the console shows two blips, target and interceptor, both
updating live.

### Stage E — Commander bring-up (props OFF)
Flash `firmware/commander` to the commander ESP32. Power it **before** the
interceptor so it wins pairing. With props off, run
`python autopilot.py --commander <port> --sim` (or stream test frames) and watch
the interceptor's channels move in the ESP-FC configurator. **Resolve the
roll/pitch sign convention here** (a wrong sign flies it away — see the note in
`guidance.py`).
**Checkpoint E:** laptop-sent channels move the interceptor's sticks/motors
(props off) in the configurator; ARM/ANGLE AUX behave; stopping the stream
fail-safes to disarm.

### Stage F — Heading downlink
Add an ESP-NOW (or MSP/WiFi) downlink of the interceptor's AHRS yaw to the
laptop; calibrate the magnetometer on-frame (motor-current interference) and
implement the takeoff calibration dance. See §4 of `interception.md`.
**Checkpoint F:** the laptop shows the interceptor's heading, stable and correct
as you rotate it by hand.

### Stage G — Guidance (already done, validate on your data)
`guidance.py` + `pursuit_sim.py` are built and validated. Replay your Stage-C/D
logs through the sim to confirm the tuning and the feedback-sign against your
real noise/latency before flying.
**Checkpoint G:** sim intercepts on your recorded data with sane gains.

### Stage H — Netted flight tests, slow first
In a net/cage, tethered/prop-guarded, human on the kill (VLOS):
1. Interceptor flies to a **stationary** beacon position and loiters (expect
   ~1–2 m). Verify RC-loss, geofence, and kill fail-safes fire.
2. Target hovers, then drifts at ≤1–3 m/s; interceptor station-keeps within a
   couple metres.
**Checkpoint H:** the interceptor reliably flies to and loiters near a slow/
hovering target, scored by measured range. **This is the realistic end-state.**

Do **not** attempt to intercept the ESP-BLAST at speed — it's ~6–9× faster than
this sensor can track (see the envelope in `interception.md`). Pushing further
means UWB ranging or fusing the target's own IMU telemetry.

---

## 3. Safety & legal (summary — full version in `interception.md` §8)

Fly under Part 107 discipline when unsure; **maintain visual line of sight**
(you have no FPV); a human RPIC watches with a **kill that always beats the
autonomy loop**; never over people; register at ≥250 g and comply with Remote
ID. **The hard line: this is tracking / station-keeping only — never a payload,
never intentional contact.** Weaponizing a UAS is separately illegal.

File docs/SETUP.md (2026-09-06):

# Full setup plan — ESP-BLAST drone + passive RF radar

> **Passive system — archived.** The current radar bring-up is
> [`radar-software.md`](radar-software.md).

The complete path from parts on the bench to a live radar display, in five
phases. Each phase ends with a checkpoint you can verify before moving on —
do not skip checkpoints; every debugging hour in this hobby is spent on a
skipped checkpoint.

Time budget: roughly one evening per phase. Cost: ~$56 in radar hardware
(see `hardware/BOM.md`) on top of the drone build itself.

---

## Phase 0 — Bench prerequisites

- [ ] Drone built per the ESP-BLAST Instructable through Step 10 (ESP-FC
      flashes and Betaflight configurator connects)
- [ ] ESP-NOW transmitter working (drone arms and responds to sticks)
- [ ] Radar parts on hand: 4× ESP32 dev boards, cables, 3 power banks
- [ ] Laptop with Python 3.10+ and Arduino IDE (with the `esp32` board
      package installed)
- [ ] This repo cloned; `pip install -r ground_station/requirements.txt`

---

## Phase 1 — Make the drone trackable (30 min)

A stock ESP-BLAST transmits a keepalive only once per second, which is too
slow to track. Full background and both options: `docs/espblast.md`.

1. In your esp-fc working copy, build once so PlatformIO fetches deps:
   `pio run -e esp32`
2. Edit `.pio/libdeps/esp32/EspNowRcLink/include/EspNowRcLink/Protocol.h`:
   change `LINK_ALIVE_INTERVAL_MS = 1000` → `40`.
3. Reflash: `pio run -e esp32 -t upload` (same bootloader-jumper procedure
   as the Instructable's Step 10).
4. Confirm the drone still binds to the transmitter and arms normally.

**Checkpoint 1:** flash `firmware/mac_scanner/` onto any spare ESP32, open
the serial monitor (115200). With drone + transmitter powered you should see
one MAC on the RC-link channel (default **7**) at ~25 Hz. Write down that
MAC and channel — you need both in Phase 2. Power-cycle the drone and watch
the MAC vanish/return to confirm it's really the drone.

---

## Phase 2 — Build the sensor network (1–2 h)

All three sketches are in `firmware/`; flash order matters only in that the
hub prints the MAC the sniffers need.

1. **Hub** (`hub_node/hub_node.ino`): set `WIFI_CHANNEL` to the channel from
   Checkpoint 1, flash, note the MAC it prints at boot. Stays on your
   laptop's USB.
2. **Sniffers** (`rx_node/rx_node.ino`) × 3: set `NODE_ID` (1, 2, 3 —
   unique), `DRONE_MAC` (Checkpoint 1), `HUB_MAC` (step 1), `WIFI_CHANNEL`.
   Flash each; label the boards physically with their number.
3. Power the sniffers from the power banks.

**Checkpoint 2:** with drone + transmitter on, open a serial monitor on the
hub. You should see one JSON line per node roughly every 250 ms, e.g.
`{"node":2,"rssi":-51,"n":6,"t":184039}`. If a node is silent: wrong
channel, wrong `DRONE_MAC`, or wrong `HUB_MAC` — in that order of
likelihood. Close the serial monitor when done (the GUI needs the port).

---

## Phase 3 — Field layout & calibration (45 min, at the flying site)

1. Place the 3 sniffer nodes in a triangle **around** the intended flight
   box, baselines ≥ 6 m, antennas vertical, ~1 m off the ground (tripods,
   stakes, or fence posts).
2. Pick an origin (e.g. node 1's stake), measure every node's (x, y, z)
   with a tape measure to ~10 cm.
3. Start the GUI: `cd ground_station && python server.py` → open
   <http://localhost:8080>.
4. Enter the node positions: press **EDIT LAYOUT** on the scope and drag
   each node marker to its measured spot (or edit `config.json` directly —
   the GUI persists to the same file).
5. Connect the hub in the **Link** panel (pick the port, press Connect).
   All three node cards should go **LIVE**.
6. Calibrate each node from the **Calibration** panel: select the node,
   hold the powered drone 1.0 m from it at antenna height (prop it on a
   box — don't hold it; your body absorbs 2.4 GHz), press **Start**, wait
   out the progress bar, press **Apply**. Repeat per node.

**Checkpoint 3:** place the drone at a known spot inside the triangle
(e.g. dead center). The blip on the scope should sit within ~1–2 m of
truth and the RESID tile should read < ~2 m. Walk the drone slowly around
the box and watch the blip follow.

---

## Phase 4 — Flight test (first calm day)

1. Start a recording (**Record** button) — every raw report and fix goes to
   `ground_station/recordings/rec-*.jsonl` for later analysis.
2. Hover in the middle of the box at ~1.5 m. Expect a steady blip, 1–2 m
   wander, solver at ~4 Hz (limited by the nodes' 250 ms report window).
3. Fly slow laps. Watch the **RESID** tile: residual spikes mean the RSSI
   model is being violated (multipath, antenna shadowing) — normal during
   banking, should recover in hover.
4. Fast passes: expect the blip to lag and smear (EMA smoothing + antenna
   pattern shifts). This is a physics limit of RSSI at 4 Hz, not a bug.

**Checkpoint 4:** a recorded session where hover fixes stay within ~2 m of
where you actually hovered. That's the system working as designed.

---

## Phase 5 — Tuning & upgrades (optional)

| Symptom | Fix |
|---|---|
| Fixes biased toward one node | Re-run that node's calibration; check its antenna is vertical |
| Blip wanders in clean line-of-sight | Raise path-loss n toward 2.4–2.5 (Model panel), recalibrate |
| Node card SLOW/LOST intermittently | Power bank auto-sleeping (add a load resistor or use a different bank); or RF shadowing — raise the node |
| Solver rate < 3 Hz | A node isn't reporting — check Checkpoint 2 for it |
| Want sub-meter accuracy | UWB path in `hardware/BOM.md` (weight caveat applies) |
| Want a 4th node / 3D fixes | Add a board as `NODE_ID 4`, add it in config, done — the solver uses all reporting nodes |

---

## Operating reference (GUI)

`python server.py` then <http://localhost:8080>. Also reachable from a
phone on the same network via `python server.py --host 0.0.0.0` (own
devices on your own network only).

- **Scope**: wheel = zoom, drag = pan, double-click = auto-fit. Range rings
  center on the node centroid; dashed circles are each node's live measured
  distance; the halo around the blip is the solver residual; the line from
  the blip is the velocity vector (1 s lookahead).
- **EDIT LAYOUT**: drag node triangles to update positions (persisted).
- **Sim mode**: full synthetic flight for testing every part of the GUI
  with zero hardware — the dashed ring is the simulated ground truth.
- **Record**: JSONL session logs in `ground_station/recordings/`.
- Headless / scripted use: `locate.py` and `calibrate.py` still work as
  CLI tools against the same `config.json`.

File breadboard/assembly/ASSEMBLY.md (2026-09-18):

# Building the breadboard, step by step

Seventeen steps. Each one adds a handful of parts, ends with something you can
measure, and has a picture of the board as it should look when you are done.
**Build in this order**: power first so every later stage has something to run
on, then the op-amps, then the signal left to right, then the digital side.

Generated by `layout.py` (on the `dev` branch) from the same placement the schematic check runs
against, so these steps cannot drift from [`WIRING.md`](../layout/WIRING.md) or from the
board.

## Before you start

| | |
|---|---|
| board | 830-point breadboard. Columns **1–63** left to right; rows **a–e** are the top bank, **f–j** the bottom. The five holes of one column in one bank are a single strip. |
| hole names | `b14` = row b, column 14. `TR-@12` = the **top blue** rail, hole nearest column 12 — on a real board just use the closest free rail hole. |
| rails | top red **V5**, top blue **GND**, bottom red **VANA** (+12 V analogue), bottom blue **GND**. |
| tools | a fine pair of snips, tweezers, a multimeter. No soldering: everything here pushes in. |

### The jumper colour code

One hue per function, so a finished board can be read at a glance and a wire in
the wrong place stands out. Nothing electrical depends on it — if your jumper
kit is short of a colour, substitute one and note it on the sheet.

| colour | carries |
|---|---|
| **black** | GND — 17 wires |
| **red** | VANA (+12 V analogue) — 5 wires |
| **orange** | V5 — 2 wires |
| **yellow** | 3V3 logic — 2 wires |
| **green** | audio signal path — 9 wires |
| **violet** | VREF half-rail bias — 5 wires |
| **blue** | SPI to the ADF4351 — 4 wires |
| **brown** | stepper STEP / DIR / EN — 3 wires |
| **pink** | SYNC to the sound card — 1 wire |

There is deliberately **no white and no grey wire** anywhere in this build: on a
cream breadboard both disappear, and the three stepper lines and the SYNC line
used to be exactly that. They are brown and pink now.

---

## Step 1 — Rails, bridged and tied

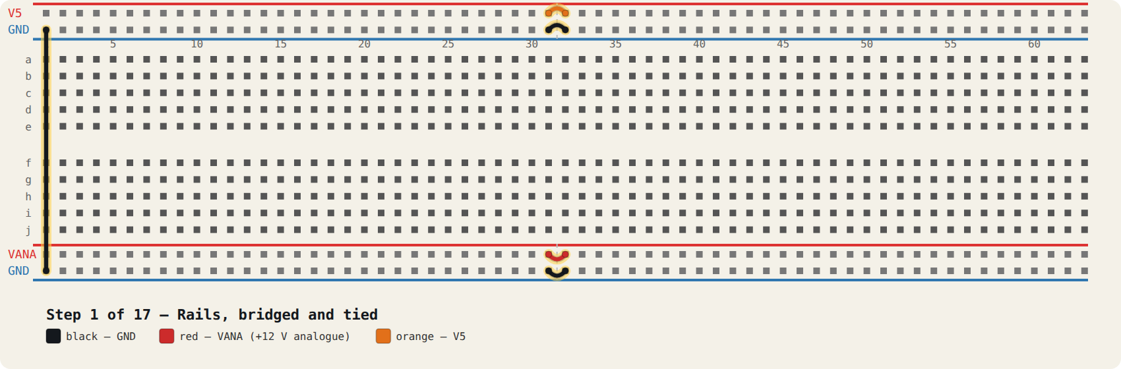
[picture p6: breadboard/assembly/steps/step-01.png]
step 1


Nothing works until the four rails carry what they claim. Many 830-point boards split every rail at the middle, so the right-hand half of each is dead until you bridge it — and a split you did not notice is the classic reason half a board is unpowered. The last wire ties the two GND rails into one ground.

| wire | colour | from → to | what it does |
|---|---|---|---|
| 1 | orange | **TR+@31** → **TR+@32** | rail bridge (omit if your rails are continuous) |
| 2 | black | **TR-@31** → **TR-@32** | rail bridge |
| 3 | red | **BR+@31** → **BR+@32** | rail bridge |
| 4 | black | **BR-@31** → **BR-@32** | rail bridge |
| 5 | black | **TR-@1** → **BR-@1** | tie the two GND rails together |

> **Check before moving on.** Continuity from each rail's far left hole to its far right hole. If your board's rails are continuous, these four bridges are harmless.

---

## Step 2 — 12 V in, and the diode that saves the board

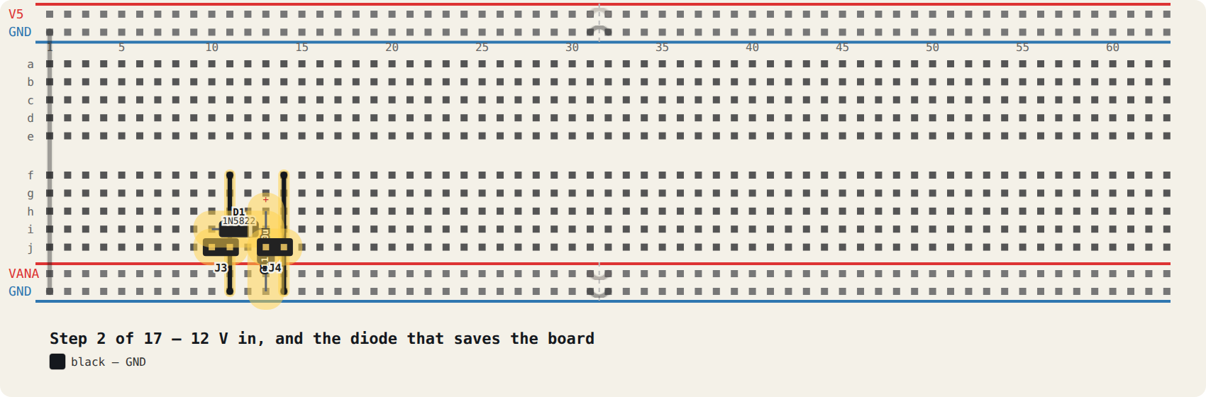
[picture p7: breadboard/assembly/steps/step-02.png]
step 2


J3 takes the 12 V supply. D1 is a series Schottky: get the supply backwards and it simply does not conduct, instead of taking the op-amps and the electrolytics with it. The band on the diode body is the cathode and it faces RIGHT, toward column 13. C11 is the bulk reservoir on the protected side.

| part | value | push it in at |
|---|---|---|
| J3 | 12V IN | 1→**j10**, 2→**j11** |
| D1 | 1N5822 | A→**i10**, K→**i13** |
| C11 | 100u | 1→**h13**, 2→**BR-@13** |
| J4 | TO BUCK IN | 1→**j13**, 2→**j14** |

| wire | colour | from → to | what it does |
|---|---|---|---|
| 1 | black | **f11** → **BR-@11** | J3 GND |
| 2 | black | **f14** → **BR-@14** | J4 GND |

> **Check before moving on.** D1's band toward column 13. C11's + leg toward column 13, its - to the GND rail.

---

## Step 3 — The VANA rail — clean 12 V for the op-amps

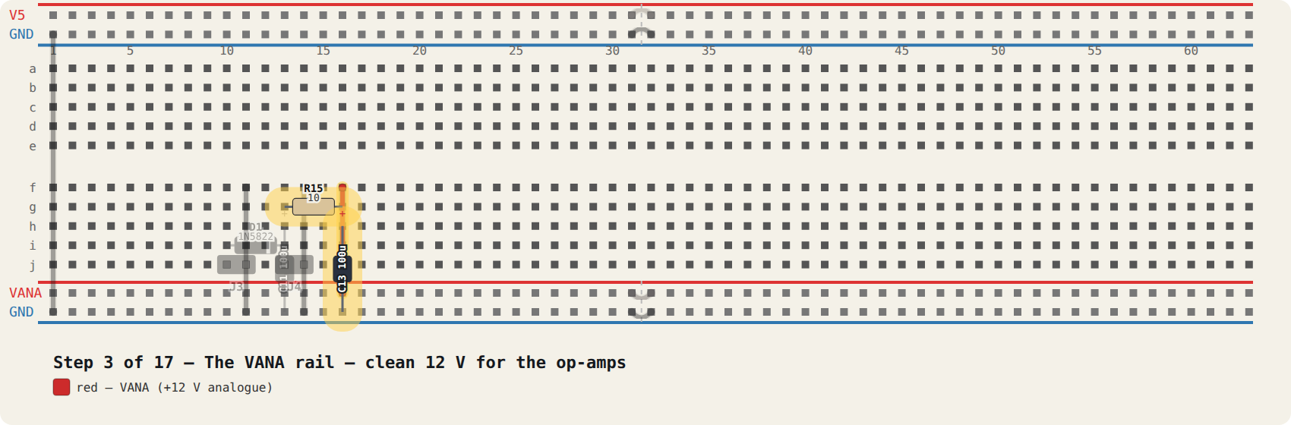
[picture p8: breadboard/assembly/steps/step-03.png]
step 3


R15 and C13 are an RC filter, not a resistor someone forgot to remove: 10 ohms into 100 uF rolls off at about 160 Hz, which keeps supply noise out of an amplifier whose whole job is a signal down at 20 mV. The output of that filter is what feeds the bottom red rail.

| part | value | push it in at |
|---|---|---|
| R15 | 10 | 1→**g13**, 2→**g16** |
| C13 | 100u | 1→**h16**, 2→**BR-@16** |

| wire | colour | from → to | what it does |
|---|---|---|---|
| 1 | red | **f16** → **BR+@16** | VANA node (R15/C13) feeds the bottom red rail |

> **Check before moving on.** Bottom red rail now sits at 12 V minus the diode drop, about 11.6 V.

---

## Step 4 — 5 V in from the buck converter

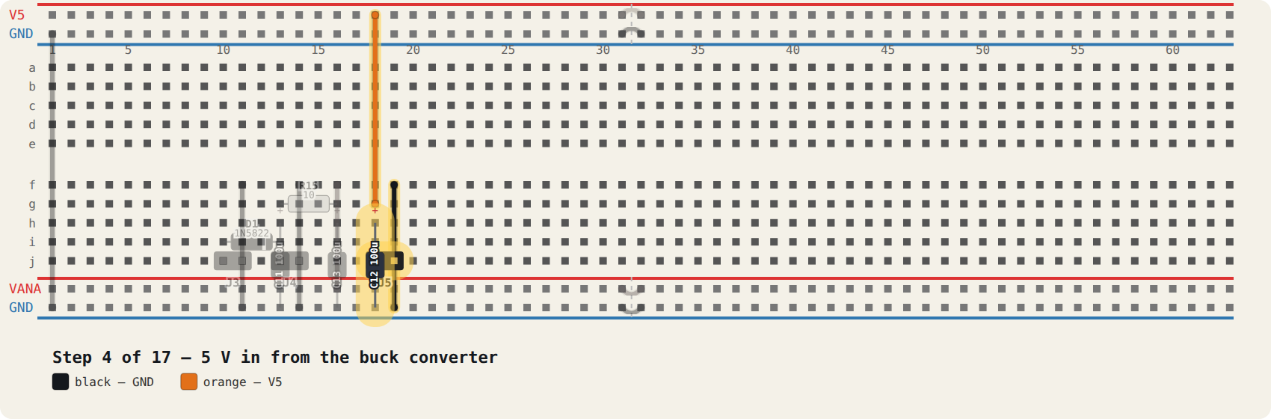
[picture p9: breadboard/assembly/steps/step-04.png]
step 4


J5 brings 5 V back from the LM2596 after you have set it with nothing else connected. C12 decouples it and the orange wire carries it up to the top red rail, which is what the three RF modules will feed from.

| part | value | push it in at |
|---|---|---|
| J5 | FROM BUCK 5V | 1→**j18**, 2→**j19** |
| C12 | 100u | 1→**h18**, 2→**BR-@18** |

| wire | colour | from → to | what it does |
|---|---|---|---|
| 1 | black | **f19** → **BR-@19** | J5 GND |
| 2 | orange | **g18** → **TR+@18** | V5 (J5/C12, bottom col 18) up to the top red rail |

> **Check before moving on.** Set the buck to 5.00 V BEFORE this wire goes in. Top red rail = 5.00 V.

---

## Step 5 — Seat the two op-amps

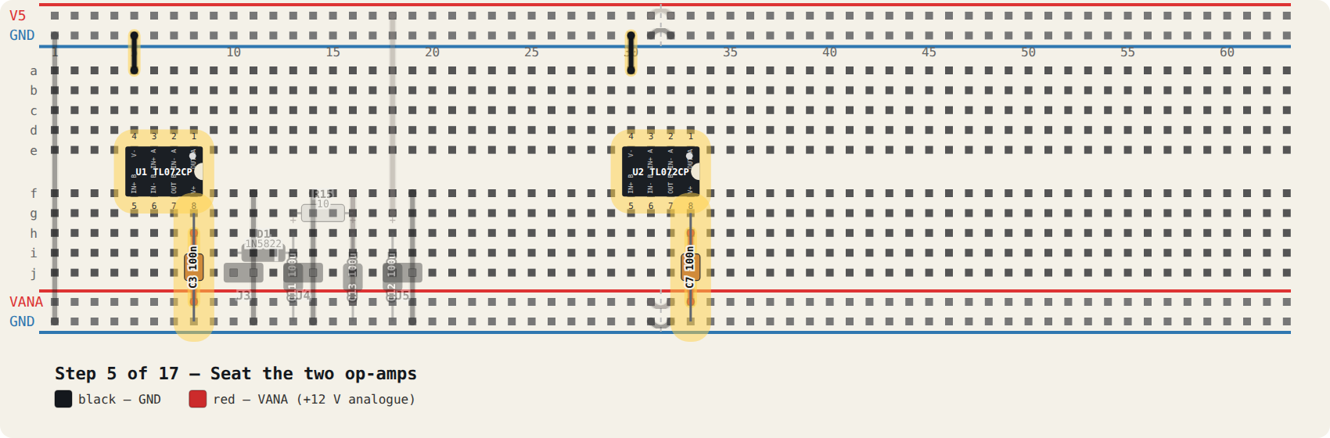
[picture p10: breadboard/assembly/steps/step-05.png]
step 5


U1 is the two gain stages, U2 the reference buffer and the output. Both straddle the centre channel so the two sides of the package land on separate strips. The notch and the pin-1 dot face RIGHT, toward the higher column. C3 and C7 are the 100 nF decouplers and they go right at pin 8 of each chip, not somewhere tidier.

| part | value | push it in at |
|---|---|---|
| U1 | TL072CP | 4→**e5**, 3→**e6**, 2→**e7**, 1→**e8**, 5→**f5**, 6→**f6**, 7→**f7**, 8→**f8** |
| U2 | TL072CP | 4→**e30**, 3→**e31**, 2→**e32**, 1→**e33**, 5→**f30**, 6→**f31**, 7→**f32**, 8→**f33** |
| C3 | 100n | 1→**g8**, 2→**BR-@8** |
| C7 | 100n | 1→**g33**, 2→**BR-@33** |

| wire | colour | from → to | what it does |
|---|---|---|---|
| 1 | black | **a5** → **TR-@5** | U1 pin 4 (V-, top col 5) to the GND rail |
| 2 | black | **a30** → **TR-@30** | U2 pin 4 (V-, top col 30) to the GND rail |
| 3 | red | **h8** → **BR+@8** | U1 pin 8 (V+, bottom col 8) to the VANA rail |
| 4 | red | **h33** → **BR+@33** | U2 pin 8 (V+, bottom col 33) to the VANA rail |

> **Check before moving on.** Pin 1 at e8 (U1) and e33 (U2). Power the board: both chips should sit at room temperature. A warm op-amp means V+ and V- are swapped.

---

## Step 6 — The half-rail reference

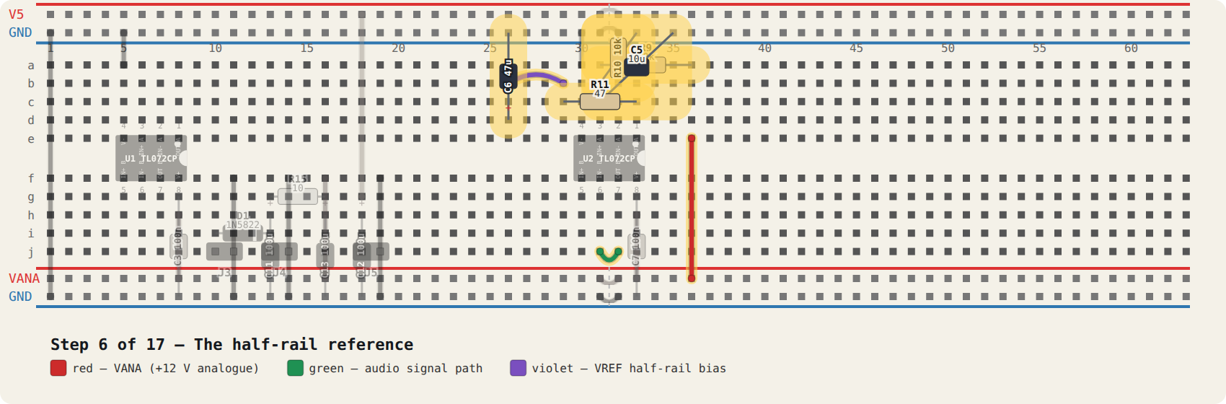
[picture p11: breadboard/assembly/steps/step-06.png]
step 6


This amplifier runs on a single supply, so 'zero' has to be manufactured: R9 and R10 divide VANA in half at column 31, C5 holds it still, and U2's second half buffers it so the divider is not loaded by everything downstream. R11 and C6 carry that buffered VREF to the node the whole signal chain hangs off.

| part | value | push it in at |
|---|---|---|
| R9 | 10k | 1→**a36**, 2→**a31** |
| R10 | 10k | 1→**b31**, 2→**TR-@33** |
| C5 | 10u | 1→**c31**, 2→**TR-@35** |
| R11 | 47 | 1→**c33**, 2→**c29** |
| C6 | 47u | 1→**d26**, 2→**TR-@26** |

| wire | colour | from → to | what it does |
|---|---|---|---|
| 1 | red | **e36** → **BR+@36** | R9's VANA end (top col 36) down to the VANA rail |
| 2 | green | **j32** → **j31** | U2 pin 7 (col 32) to pin 6 (col 31): unity-gain buffer |
| 3 | green | **a33** → **a32** | U2 pin 1 (col 33) to pin 2 (col 32): VREF buffer, unity gain |
| 4 | violet | **b29** → **b26** | R11's far end (col 29) to the VREF node (col 26) |

> **Check before moving on.** VREF (column 26) should read half of VANA, about 5.8 V, and be steady.

---

## Step 7 — Spread VREF along the board

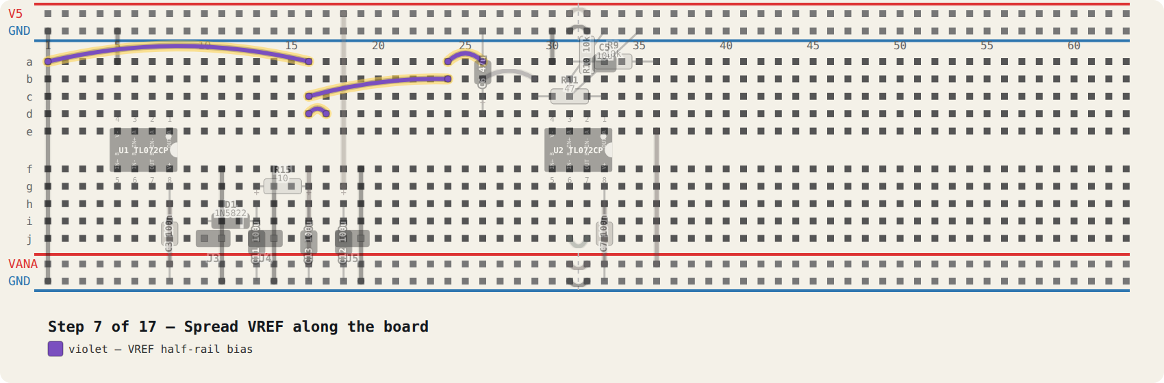
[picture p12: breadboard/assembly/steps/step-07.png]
step 7


Four violet wires, and they are the reason the amplifier has a zero to swing about. The long one runs the length of row a to reach the input stage at column 1. Do them as a set so none is forgotten — a stage whose VREF is missing is not dead, it is railed, which is a more confusing symptom.

| wire | colour | from → to | what it does |
|---|---|---|---|
| 1 | violet | **a26** → **a24** | VREF -> C9's VREF end |
| 2 | violet | **b24** → **c16** | VREF -> R6's VREF end (col 16) |
| 3 | violet | **d16** → **d17** | VREF (col 16) -> R4's VREF end (col 17) |
| 4 | violet | **a1** → **a16** | VREF -> R2's VREF end (col 1): long run along row a |

> **Check before moving on.** Every violet wire end reads the same 5.8 V.

---

## Step 8 — The input: mixer IF, terminated

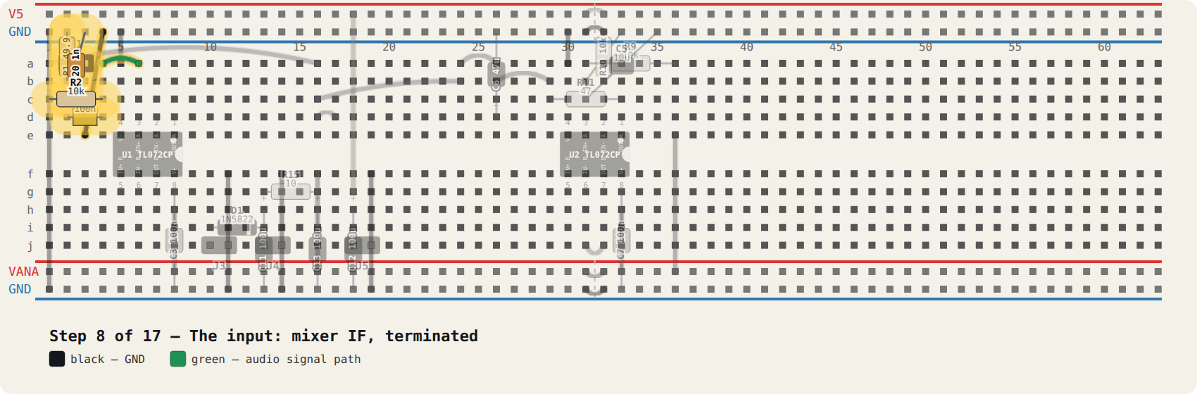
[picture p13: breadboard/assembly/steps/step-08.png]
step 8


R1 is the 49.9 ohm load the mixer's IF port wants; without it the conversion loss and the flatness wander. C20 shunts the LO that leaks out of that same port at 2.4 GHz, which a TL072 would otherwise rectify into a DC offset. C1 and R2 are the first high-pass, and they are what stop the TX leakage tone from saturating the gain.

| part | value | push it in at |
|---|---|---|
| J1 | MIXER IF | 1→**a2**, 2→**a3** |
| R1 | 49.9 | 1→**b2**, 2→**TR-@2** |
| C20 | 1n | 1→**c2**, 2→**TR-@3** |
| C1 | 100n | 1→**d2**, 2→**d4** |
| R2 | 10k | 1→**c4**, 2→**c1** |

| wire | colour | from → to | what it does |
|---|---|---|---|
| 1 | black | **e3** → **TR-@4** | J1 GND |
| 2 | green | **a4** → **a6** | AP (C1/R2 node) into U1 pin 3 (IN+ A, col 6) |

> **Check before moving on.** R1 across the IF input reads 49.9 ohms to ground.

---

## Step 9 — Gain stage A, times 101

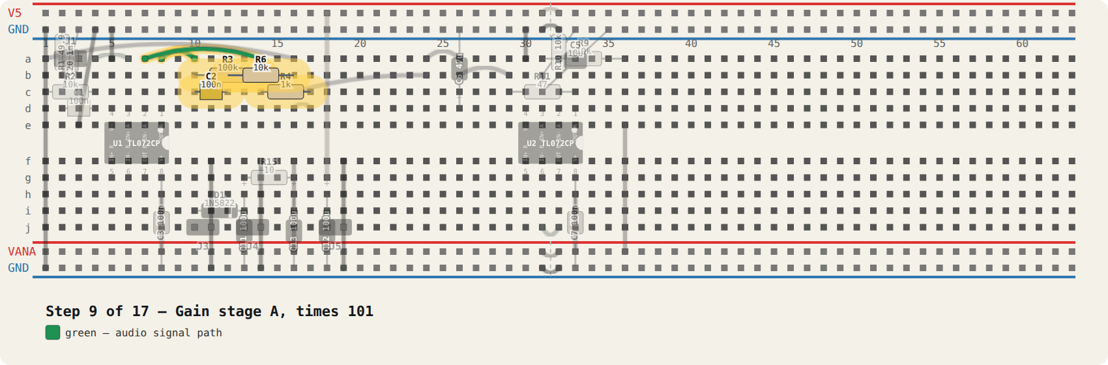
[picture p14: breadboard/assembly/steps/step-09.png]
step 9


R3 over R4 sets the gain. R4 is 1k for the full 40 dB, but fit 4.7k on first power-up for a gain of 22: if the TX leakage is stronger than you expected, a lower first gain is the difference between seeing it and clipping on it. C2 and R6 are the second high-pass into stage B.

| part | value | push it in at |
|---|---|---|
| R3 | 100k | 1→**b14**, 2→**b10** |
| C2 | 100n | 1→**c10**, 2→**c12** |
| R4 | 1k | 1→**c14**, 2→**c17** |
| R6 | 10k | 1→**b12**, 2→**b16** |

| wire | colour | from → to | what it does |
|---|---|---|---|
| 1 | green | **a8** → **a10** | U1 pin 1 (OUT A, col 8) to the AOUT node (col 10) |
| 2 | green | **a14** → **a7** | AM node (R3/R4) back to U1 pin 2 (IN- A, col 7) |

> **Check before moving on.** Inject 10 mV at 1 kHz: about 107 mV out of stage A with R4 at 4.7k.

---

## Step 10 — Gain stage B, times 11, and the anti-alias corner

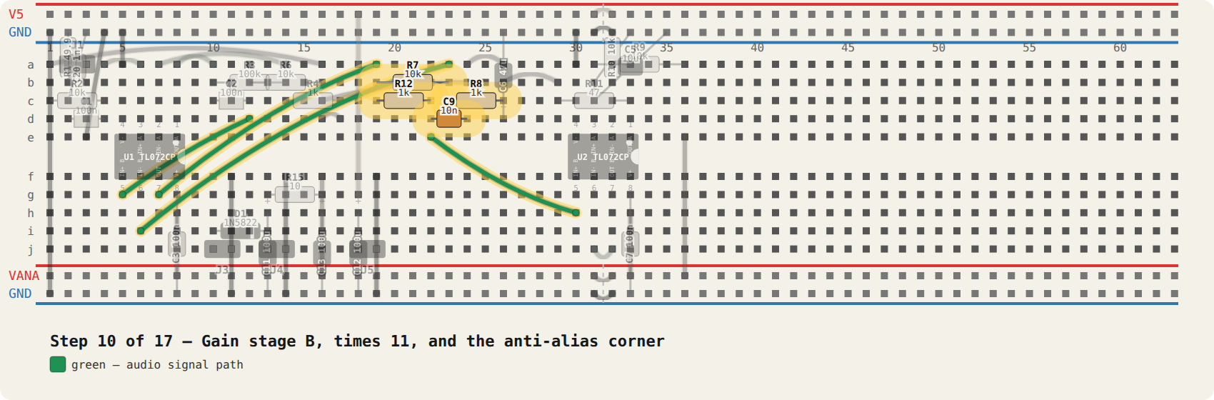
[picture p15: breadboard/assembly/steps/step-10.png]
step 10


R7 over R8 gives the second 21 dB. R12 with C9 is the 15.9 kHz low-pass that limits the noise bandwidth reaching the sound card. The last wire takes that filtered node across the channel into U2's spare half.

| part | value | push it in at |
|---|---|---|
| R7 | 10k | 1→**b23**, 2→**b19** |
| R8 | 1k | 1→**c23**, 2→**c26** |
| R12 | 1k | 1→**c19**, 2→**c22** |
| C9 | 10n | 1→**d22**, 2→**d24** |

| wire | colour | from → to | what it does |
|---|---|---|---|
| 1 | green | **d12** → **g5** | BP (C2/R6 node) across the channel into U1 pin 5 (IN+ B, bottom col 5) |
| 2 | green | **g7** → **a19** | U1 pin 7 (OUT B, bottom col 7) up to the BOUT node (col 19) |
| 3 | green | **a23** → **i6** | BM node (R7/R8) across to U1 pin 6 (IN- B, bottom col 6) |
| 4 | green | **e22** → **h30** | LP (R12/C9 node) across to U2 pin 5 (IN+ B, bottom col 30) |

> **Check before moving on.** Total gain now about 61 dB. Sweep it: -3 dB at 15.9 kHz, -6 dB at 159 Hz.

---

## Step 11 — Output, isolated and bled to ground

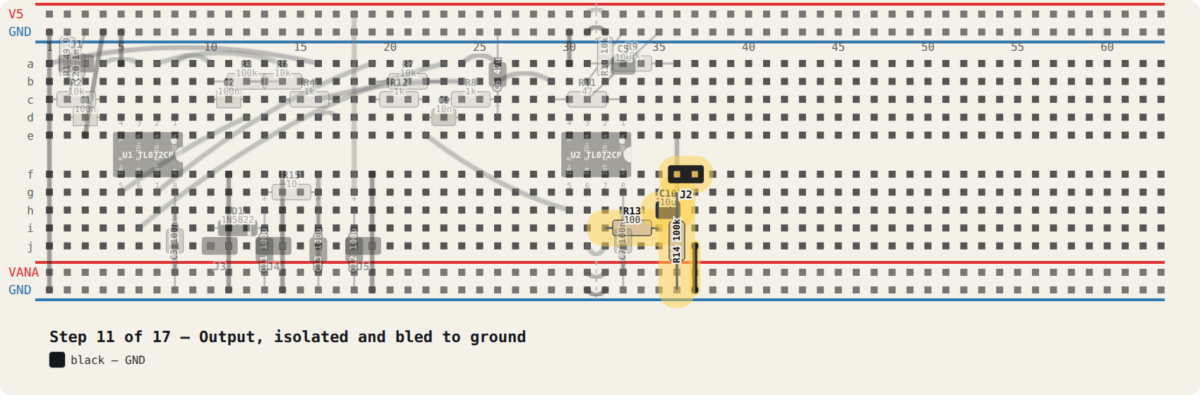
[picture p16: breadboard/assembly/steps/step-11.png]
step 11


R13 and C10 hand the signal to the sound card through a series resistor, so a cable capacitance does not hang directly off an op-amp output. R14 bleeds the coupling cap so the jack is not left holding a charge, and J2 is the audio-left output to the interface.

| part | value | push it in at |
|---|---|---|
| R13 | 100 | 1→**i32**, 2→**i35** |
| C10 | 10u | 1→**h35**, 2→**h36** |
| R14 | 100k | 1→**g36**, 2→**BR-@36** |
| J2 | AUDIO L | 1→**f36**, 2→**f37** |

| wire | colour | from → to | what it does |
|---|---|---|---|
| 1 | black | **j37** → **BR-@37** | J2 GND |

> **Check before moving on.** Output DC near 0 V after C10. Finger on the input gives a hum: the amp is alive.

---

## Step 12 — Three 5 V feeds for the RF modules

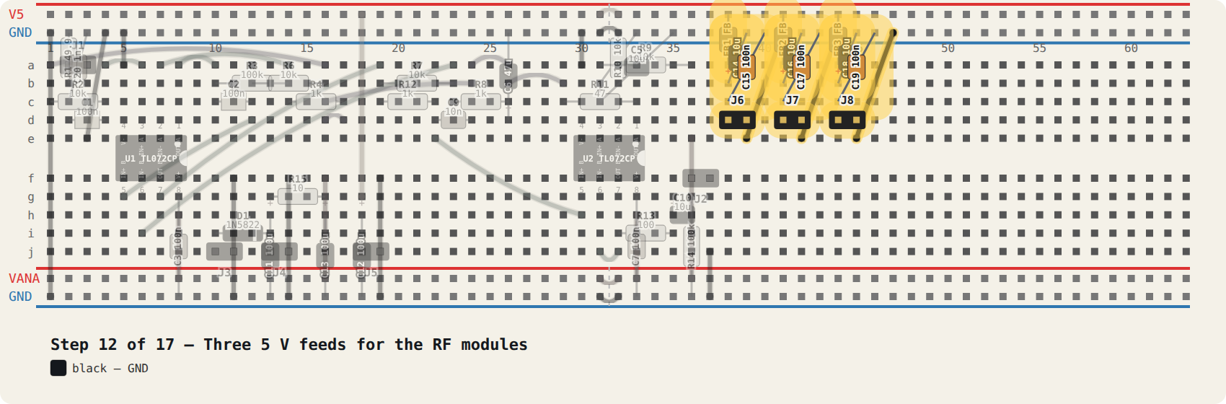
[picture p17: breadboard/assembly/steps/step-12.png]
step 12


The ADF4351, the PA and the LNA each get a ferrite bead and their own 10 uF plus 100 nF pair, so one module's switching noise does not arrive at the next one along the rail. Identical blocks at columns 38, 41 and 44 — build one, check it, then repeat it twice.

| part | value | push it in at |
|---|---|---|
| FB1 | FB | 1→**TR+@38**, 2→**a38** |
| C14 | 10u | 1→**b38**, 2→**TR-@39** |
| C15 | 100n | 1→**c38**, 2→**TR-@40** |
| J6 | ADF4351 5V | 1→**d38**, 2→**d39** |
| FB2 | FB | 1→**TR+@41**, 2→**a41** |
| C16 | 10u | 1→**b41**, 2→**TR-@42** |
| C17 | 100n | 1→**c41**, 2→**TR-@43** |
| J7 | PA 5V | 1→**d41**, 2→**d42** |
| FB3 | FB | 1→**TR+@44**, 2→**a44** |
| C18 | 10u | 1→**b44**, 2→**TR-@45** |
| C19 | 100n | 1→**c44**, 2→**TR-@46** |
| J8 | LNA 5V | 1→**d44**, 2→**d45** |

| wire | colour | from → to | what it does |
|---|---|---|---|
| 1 | black | **e39** → **TR-@41** | J6 GND |
| 2 | black | **e42** → **TR-@44** | J7 GND |
| 3 | black | **e45** → **TR-@47** | J8 GND |

> **Check before moving on.** 5.00 V at all three of J6, J7, J8 with nothing plugged into them.

---

## Step 13 — The ESP32 header and its series resistors

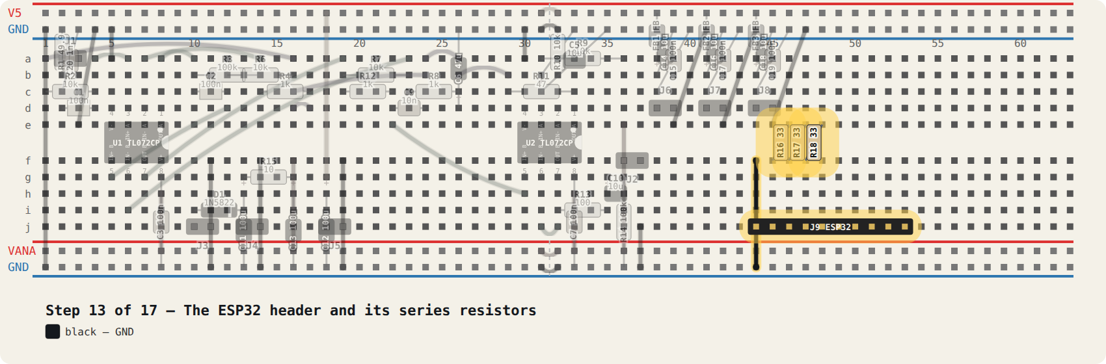
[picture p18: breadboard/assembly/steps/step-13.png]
step 13


J9 is where the radar's ESP32 lands. R16 to R18 are 33 ohm series resistors on SCK, MOSI and LE: they damp the edges so a 2.54 mm breadboard run does not ring into the PLL's logic inputs. Each one hops the centre channel into the top bank.

| part | value | push it in at |
|---|---|---|
| J9 | ESP32 | 1→**j44**, 2→**j45**, 3→**j46**, 4→**j47**, 5→**j48**, 6→**j49**, 7→**j50**, 8→**j51**, 9→**j52**, 10→**j53** |
| R16 | 33 | 1→**f45**, 2→**e46** |
| R17 | 33 | 1→**f46**, 2→**e47** |
| R18 | 33 | 1→**f47**, 2→**e48** |

| wire | colour | from → to | what it does |
|---|---|---|---|
| 1 | black | **f44** → **BR-@44** | J9 pin 1 GND |

> **Check before moving on.** Each resistor reads 33 ohms between its two strips, and nothing else.

---

## Step 14 — SPI across to the ADF4351

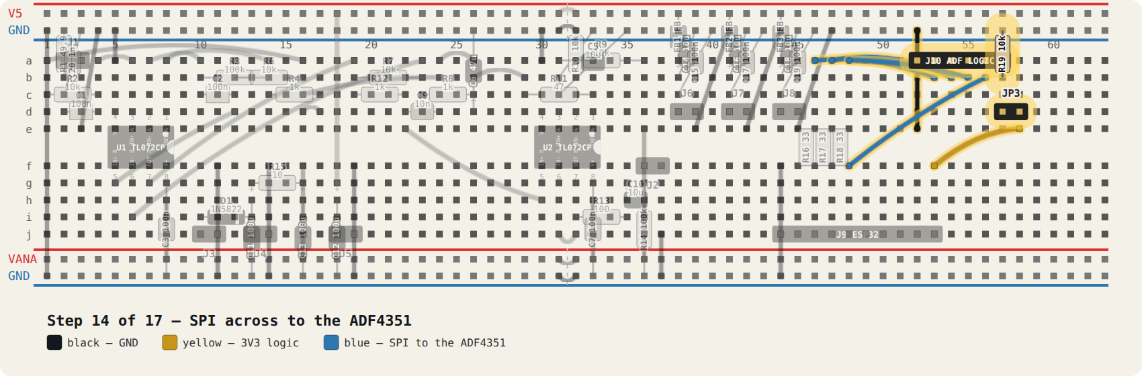
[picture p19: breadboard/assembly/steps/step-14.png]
step 14


Four blue wires carry the damped SPI and the lock-detect line up to J10. R19 pulls CE down so the synthesiser's output stays OFF until something deliberately enables it, and JP3 is the link that enables it. The yellow wire brings 3V3 over from the ESP32 — the ADF4351 board is 3.3 V logic and needs no level shifting.

| part | value | push it in at |
|---|---|---|
| J10 | ADF LOGIC | 1→**a52**, 2→**a53**, 3→**a54**, 4→**a55**, 5→**a56**, 6→**a57** |
| R19 | 10k | 1→**b57**, 2→**TR-@57** |
| JP3 | CE EN | 1→**d57**, 2→**d58** |

| wire | colour | from → to | what it does |
|---|---|---|---|
| 1 | black | **e52** → **TR-@52** | J10 pin 1 GND |
| 2 | blue | **a46** → **b53** | R16 out (top col 46) -> J10 pin 2 SCK_O (col 53) |
| 3 | blue | **a47** → **b54** | R17 out (top col 47) -> J10 pin 3 MOSI_O (col 54) |
| 4 | blue | **a48** → **b55** | R18 out (top col 48) -> J10 pin 4 LE_O (col 55) |
| 5 | blue | **f48** → **b56** | J9 pin 5 LD (bottom col 48) -> J10 pin 5 LD (top col 56) |
| 6 | yellow | **f53** → **e58** | J9 pin 10 3V3 (bottom col 53) -> JP3 pin 2 (top col 58) |

> **Check before moving on.** With JP3 off, CE reads 0 V. The radar must boot with RF off.

---

## Step 15 — The A4988 stepper header

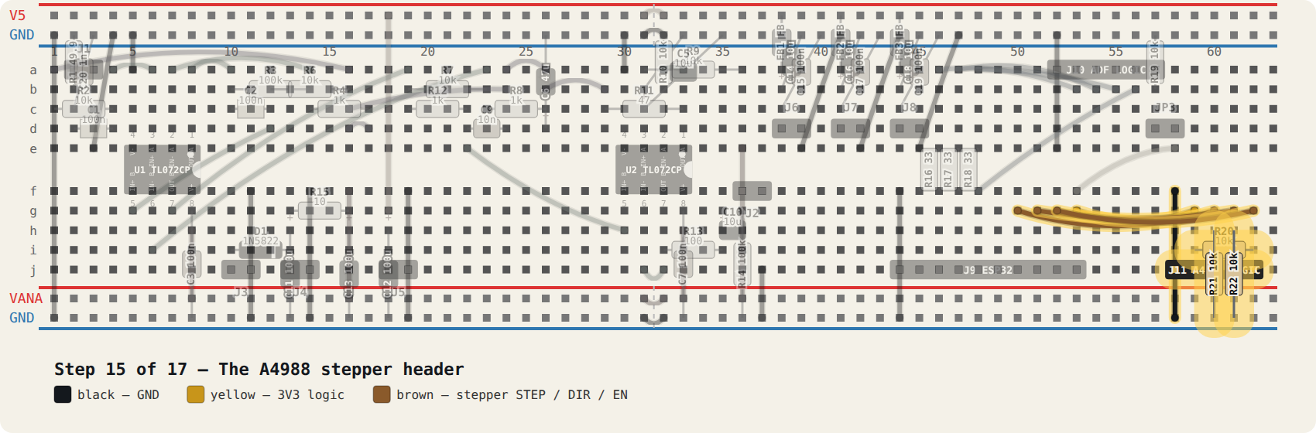
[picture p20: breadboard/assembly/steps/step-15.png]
step 15


Only for the optional turntable; skip the whole step if you are not fitting one. R20 pulls EN up so the driver is disabled until the ESP32 says otherwise, and R21 and R22 pull STEP and DIR down so a floating input cannot make the motor twitch at power-up. The three brown wires are the control lines.

| part | value | push it in at |
|---|---|---|
| J11 | A4988 LOGIC | 1→**j58**, 2→**j59**, 3→**j60**, 4→**j61**, 5→**j62** |
| R20 | 10k | 1→**i59**, 2→**i62** |
| R21 | 10k | 1→**h60**, 2→**BR-@60** |
| R22 | 10k | 1→**h61**, 2→**BR-@61** |

| wire | colour | from → to | what it does |
|---|---|---|---|
| 1 | black | **f58** → **BR-@58** | J11 pin 1 GND |
| 2 | yellow | **g53** → **g59** | 3V3 -> J11 pin 2 / R20 (bottom col 59) |
| 3 | brown | **g50** → **g60** | J9 pin 7 STEP (col 50) -> J11 pin 3 (col 60) |
| 4 | brown | **g51** → **g61** | J9 pin 8 DIR (col 51) -> J11 pin 4 (col 61) |
| 5 | brown | **g52** → **g62** | J9 pin 9 EN (col 52) -> J11 pin 5 (col 62) |

> **Check before moving on.** EN sits at 3V3, STEP and DIR at 0 V, with the ESP32 unplugged.

---

## Step 16 — The SYNC divider back to the sound card

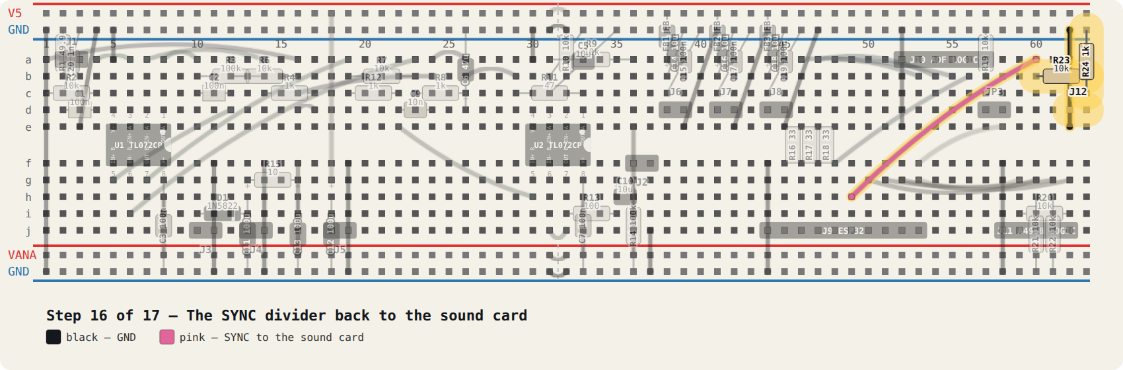
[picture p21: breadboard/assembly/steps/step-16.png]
step 16


The last block, and the one that makes the whole radar measurable: R23 and R24 divide the ESP32's 3.3 V chirp marker down to about 0.3 V, which is a line-level signal the sound card's right channel can take. Without it the laptop cannot cut the beat signal into chirps and there is no range axis at all.

| part | value | push it in at |
|---|---|---|
| R23 | 10k | 1→**b60**, 2→**b63** |
| R24 | 1k | 1→**c63**, 2→**TR-@63** |
| J12 | AUDIO R | 1→**d63**, 2→**d62** |

| wire | colour | from → to | what it does |
|---|---|---|---|
| 1 | black | **e62** → **TR-@62** | J12 GND |
| 2 | pink | **h49** → **a60** | J9 pin 6 SYNC (bottom col 49) up to R23 (top col 60) |

> **Check before moving on.** A 135 Hz square wave of about 0.3 V at J12 once radar_ctl is running.

---

## Step 17 — Before you power anything

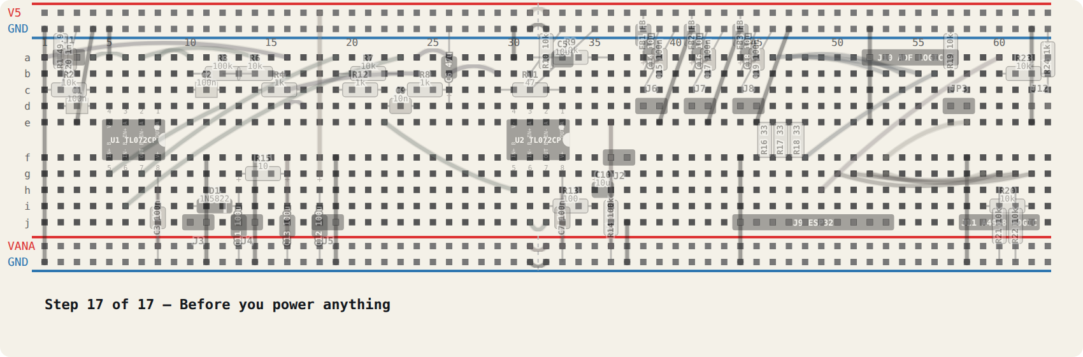
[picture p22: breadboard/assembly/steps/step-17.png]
step 17


The board is finished. These are the measurements that catch a build error while it is still cheap, with the supply DISCONNECTED and nothing plugged into the headers.

> **Check before moving on.** Ohm-meter, all with power off: GND to VANA, GND to V5 and GND to 3V3 must each read open (over 1 kohm). Any of them near zero is a short — find it before you connect 12 V. Then work the test blocks in `../multisim/`.

---

## When it is all in

The finished board: [`breadboard.png`](../layout/breadboard.png), every hole and net in
[`WIRING.md`](../layout/WIRING.md), and [`breadboard.html`](../layout/breadboard.html) if you want
to hover a part and see what it touches.

Simulate before you trust it — [`multisim/README.md`](../multisim/README.md) has one test block per circuit,
with the stimulus and the reading to expect.

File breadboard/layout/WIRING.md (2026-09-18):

# Breadboard wiring — every hole, every wire

Generated by `layout.py` on the [`dev` branch](https://github.com/dpaulb005/radar-dev-/tree/dev/hardware/breadboard) and **verified against the schematic netlist**: every net is one
connected group on the board, no two nets touch, and the rails carry what they claim.
Board: 830-point. Columns 1–63 left→right; rows a–e top bank, f–j bottom bank; each column
of five holes is one strip. Rails: `TR+` top red = **V5**, `TR-` top blue = **GND**, `BR+`
bottom red = **VANA**, `BR-` bottom blue = **GND**. `TR-@12` = the top-blue-rail hole beside column 12.
Rails are assumed split at columns 31|32; four bridge wires are included (harmless if continuous).

## Build order

1. Rails and rail bridges, the GND-to-GND tie, then the op-amp supply wires.
2. U1, U2 (notch = pin 1 toward the low column number).
3. Signal chain left → right (J1 … J2), then the bias parts around U2.
4. Power on the bottom bank (J3 … C12), then the three 5 V feeds top-right.
5. Digital: J9, R16–R18, J10, JP3/R19, J11, R20–R22, R23/R24, J12.
6. Jumper wires last, colour by colour, ticking each row below.

## Components

| ref | part | lead → hole | note |
|---|---|---|---|
| J1 | MIXER IF (hdr2) | 1→**a2**, 2→**a3** | 1=IF / 2=GND |
| R1 | 49.9 (res) | 1→**b2**, 2→**TR-@2** | IF termination straight to the top GND rail |
| C20 | 1n (cer) | 1→**c2**, 2→**TR-@3** | RF stop, beside R1 |
| C1 | 100n (film) | 1→**d2**, 2→**d4** | 5 mm film cap = 2 columns |
| R2 | 10k (res) | 1→**c4**, 2→**c1** | AP -> VREF node (col 1) |
| U1 | TL072CP (dip8) | 4→**e5**, 3→**e6**, 2→**e7**, 1→**e8**, 5→**f5**, 6→**f6**, 7→**f7**, 8→**f8** | notch and pin-1 dot toward column 8 (right); pin 1 at e8, pin 8 at f8 |
| R3 | 100k (res) | 1→**b14**, 2→**b10** | feedback A: pin 1 at AM (col 14), pin 2 at AOUT (col 10) |
| C2 | 100n (film) | 1→**c10**, 2→**c12** | AOUT -> BP |
| R4 | 1k (res) | 1→**c14**, 2→**c17** | AM -> VREF (col 17). 4.7k here for gain 22 on first power-up |
| R6 | 10k (res) | 1→**b12**, 2→**b16** | BP -> VREF (col 16) |
| R7 | 10k (res) | 1→**b23**, 2→**b19** | feedback B: pin 1 at BM (col 23), pin 2 at BOUT (col 19). Wire link here = gain 1 |
| R8 | 1k (res) | 1→**c23**, 2→**c26** | BM -> VREF (col 26) |
| R12 | 1k (res) | 1→**c19**, 2→**c22** | BOUT -> LP (col 22) |
| C9 | 10n (cer) | 1→**d22**, 2→**d24** | LP -> VREF (col 24) |
| U2 | TL072CP (dip8) | 4→**e30**, 3→**e31**, 2→**e32**, 1→**e33**, 5→**f30**, 6→**f31**, 7→**f32**, 8→**f33** | notch and pin-1 dot toward column 33 (right); pin 1 at e33, pin 8 at f33 |
| R13 | 100 (res) | 1→**i32**, 2→**i35** | OBUF (U2 pin 7, col 32 bottom) -> OISO (col 35) |
| C10 | 10u (elec) | 1→**h35**, 2→**h36** | + toward R13 (col 35), - toward J2 (col 36) |
| R14 | 100k (res) | 1→**g36**, 2→**BR-@36** | output bleed to the bottom GND rail |
| J2 | AUDIO L (hdr2) | 1→**f36**, 2→**f37** | 1=AUDIO_L / 2=GND |
| R9 | 10k (res) | 1→**a36**, 2→**a31** | VANA stub (col 36 top, jumpered to BR+) -> VDIV (col 31 = U2 pin 3) |
| R10 | 10k (res) | 1→**b31**, 2→**TR-@33** | VDIV (col 31) -> GND rail |
| C5 | 10u (elec) | 1→**c31**, 2→**TR-@35** | + at VDIV (col 31), - bent up to the GND rail |
| R11 | 47 (res) | 1→**c33**, 2→**c29** | VBUF (U2 pin 1, col 33) -> col 29, then a wire on to the VREF node (col 26) |
| C6 | 47u (elec) | 1→**d26**, 2→**TR-@26** | + at VREF |
| J3 | 12V IN (hdr2) | 1→**j10**, 2→**j11** | 1=VIN12 / 2=GND |
| D1 | 1N5822 (diode) | A→**i10**, K→**i13** | band (cathode) toward col 13 = VPROT |
| C11 | 100u (elec) | 1→**h13**, 2→**BR-@13** | + at VPROT |
| J4 | TO BUCK IN (hdr2) | 1→**j13**, 2→**j14** | 1=VPROT / 2=GND |
| R15 | 10 (res) | 1→**g13**, 2→**g16** | VPROT -> VANA node (col 16 bottom) |
| C13 | 100u (elec) | 1→**h16**, 2→**BR-@16** | + at VANA |
| J5 | FROM BUCK 5V (hdr2) | 1→**j18**, 2→**j19** | 1=V5 / 2=GND |
| C12 | 100u (elec) | 1→**h18**, 2→**BR-@18** | + at V5 |
| C3 | 100n (cer) | 1→**g8**, 2→**BR-@8** | U1 V+ (pin 8, col 8 bottom) to GND, right at the pin |
| C7 | 100n (cer) | 1→**g33**, 2→**BR-@33** | U2 V+ (pin 8, col 33 bottom) to GND |
| FB1 | FB (bead) | 1→**TR+@38**, 2→**a38** | from the top 5 V rail down into the column |
| C14 | 10u (elec) | 1→**b38**, 2→**TR-@39** | + at the module rail |
| C15 | 100n (cer) | 1→**c38**, 2→**TR-@40** |  |
| J6 | ADF4351 5V (hdr2) | 1→**d38**, 2→**d39** | 1=5V / 2=GND |
| FB2 | FB (bead) | 1→**TR+@41**, 2→**a41** | from the top 5 V rail down into the column |
| C16 | 10u (elec) | 1→**b41**, 2→**TR-@42** | + at the module rail |
| C17 | 100n (cer) | 1→**c41**, 2→**TR-@43** |  |
| J7 | PA 5V (hdr2) | 1→**d41**, 2→**d42** | 1=5V / 2=GND |
| FB3 | FB (bead) | 1→**TR+@44**, 2→**a44** | from the top 5 V rail down into the column |
| C18 | 10u (elec) | 1→**b44**, 2→**TR-@45** | + at the module rail |
| C19 | 100n (cer) | 1→**c44**, 2→**TR-@46** |  |
| J8 | LNA 5V (hdr2) | 1→**d44**, 2→**d45** | 1=5V / 2=GND |
| J9 | ESP32 (hdr10) | 1→**j44**, 2→**j45**, 3→**j46**, 4→**j47**, 5→**j48**, 6→**j49**, 7→**j50**, 8→**j51**, 9→**j52**, 10→**j53** | 1=GND / 2=SCK / 3=MOSI / 4=LE / 5=LD / 6=SYNC / 7=STEP / 8=DIR / 9=EN / 10=3V3 |
| R16 | 33 (res) | 1→**f45**, 2→**e46** | SCK (bottom col 45) straight across the channel to top col 46 |
| R17 | 33 (res) | 1→**f46**, 2→**e47** | MOSI (bottom col 46) across to top col 47 |
| R18 | 33 (res) | 1→**f47**, 2→**e48** | LE (bottom col 47) across to top col 48 |
| J10 | ADF LOGIC (hdr6) | 1→**a52**, 2→**a53**, 3→**a54**, 4→**a55**, 5→**a56**, 6→**a57** | 1=GND / 2=SCK_O / 3=MOSI_O / 4=LE_O / 5=LD / 6=CE |
| R19 | 10k (res) | 1→**b57**, 2→**TR-@57** | CE pull-down |
| JP3 | CE EN (hdr2) | 1→**d57**, 2→**d58** | 1=CE / 2=3V3 |
| J11 | A4988 LOGIC (hdr5) | 1→**j58**, 2→**j59**, 3→**j60**, 4→**j61**, 5→**j62** | 1=GND / 2=3V3 / 3=STEP / 4=DIR / 5=EN |
| R20 | 10k (res) | 1→**i59**, 2→**i62** | EN pull-up: pin 1 at 3V3 (col 59), pin 2 at EN (col 62) |
| R21 | 10k (res) | 1→**h60**, 2→**BR-@60** | STEP pull-down |
| R22 | 10k (res) | 1→**h61**, 2→**BR-@61** | DIR pull-down |
| R23 | 10k (res) | 1→**b60**, 2→**b63** | SYNC (jumpered up to col 60 top) -> AUDIO_R (col 63) |
| R24 | 1k (res) | 1→**c63**, 2→**TR-@63** | 0.3 V divider bottom leg |
| J12 | AUDIO R (hdr2) | 1→**d63**, 2→**d62** | 1=AUDIO_R (col 63), 2=GND stub (col 62) |

## Jumper wires

| # | from | to | colour | purpose |
|---|---|---|---|---|
| 1 | **e3** | **TR-@4** | black | J1 GND |
| 2 | **j37** | **BR-@37** | black | J2 GND |
| 3 | **f11** | **BR-@11** | black | J3 GND |
| 4 | **f14** | **BR-@14** | black | J4 GND |
| 5 | **f19** | **BR-@19** | black | J5 GND |
| 6 | **e39** | **TR-@41** | black | J6 GND |
| 7 | **e42** | **TR-@44** | black | J7 GND |
| 8 | **e45** | **TR-@47** | black | J8 GND |
| 9 | **f44** | **BR-@44** | black | J9 pin 1 GND |
| 10 | **e52** | **TR-@52** | black | J10 pin 1 GND |
| 11 | **f58** | **BR-@58** | black | J11 pin 1 GND |
| 12 | **e62** | **TR-@62** | black | J12 GND |
| 13 | **a5** | **TR-@5** | black | U1 pin 4 (V-, top col 5) to the GND rail |
| 14 | **a30** | **TR-@30** | black | U2 pin 4 (V-, top col 30) to the GND rail |
| 15 | **h8** | **BR+@8** | red | U1 pin 8 (V+, bottom col 8) to the VANA rail |
| 16 | **h33** | **BR+@33** | red | U2 pin 8 (V+, bottom col 33) to the VANA rail |
| 17 | **f16** | **BR+@16** | red | VANA node (R15/C13) feeds the bottom red rail |
| 18 | **e36** | **BR+@36** | red | R9's VANA end (top col 36) down to the VANA rail |
| 19 | **g18** | **TR+@18** | orange | V5 (J5/C12, bottom col 18) up to the top red rail |
| 20 | **TR-@1** | **BR-@1** | black | tie the two GND rails together |
| 21 | **TR+@31** | **TR+@32** | orange | rail bridge (omit if your rails are continuous) |
| 22 | **TR-@31** | **TR-@32** | black | rail bridge |
| 23 | **BR+@31** | **BR+@32** | red | rail bridge |
| 24 | **BR-@31** | **BR-@32** | black | rail bridge |
| 25 | **a4** | **a6** | green | AP (C1/R2 node) into U1 pin 3 (IN+ A, col 6) |
| 26 | **a8** | **a10** | green | U1 pin 1 (OUT A, col 8) to the AOUT node (col 10) |
| 27 | **a14** | **a7** | green | AM node (R3/R4) back to U1 pin 2 (IN- A, col 7) |
| 28 | **d12** | **g5** | green | BP (C2/R6 node) across the channel into U1 pin 5 (IN+ B, bottom col 5) |
| 29 | **g7** | **a19** | green | U1 pin 7 (OUT B, bottom col 7) up to the BOUT node (col 19) |
| 30 | **a23** | **i6** | green | BM node (R7/R8) across to U1 pin 6 (IN- B, bottom col 6) |
| 31 | **e22** | **h30** | green | LP (R12/C9 node) across to U2 pin 5 (IN+ B, bottom col 30) |
| 32 | **j32** | **j31** | green | U2 pin 7 (col 32) to pin 6 (col 31): unity-gain buffer |
| 33 | **a33** | **a32** | green | U2 pin 1 (col 33) to pin 2 (col 32): VREF buffer, unity gain |
| 34 | **b29** | **b26** | violet | R11's far end (col 29) to the VREF node (col 26) |
| 35 | **a26** | **a24** | violet | VREF -> C9's VREF end |
| 36 | **b24** | **c16** | violet | VREF -> R6's VREF end (col 16) |
| 37 | **d16** | **d17** | violet | VREF (col 16) -> R4's VREF end (col 17) |
| 38 | **a1** | **a16** | violet | VREF -> R2's VREF end (col 1): long run along row a |
| 39 | **a46** | **b53** | blue | R16 out (top col 46) -> J10 pin 2 SCK_O (col 53) |
| 40 | **a47** | **b54** | blue | R17 out (top col 47) -> J10 pin 3 MOSI_O (col 54) |
| 41 | **a48** | **b55** | blue | R18 out (top col 48) -> J10 pin 4 LE_O (col 55) |
| 42 | **f48** | **b56** | blue | J9 pin 5 LD (bottom col 48) -> J10 pin 5 LD (top col 56) |
| 43 | **f53** | **e58** | yellow | J9 pin 10 3V3 (bottom col 53) -> JP3 pin 2 (top col 58) |
| 44 | **g53** | **g59** | yellow | 3V3 -> J11 pin 2 / R20 (bottom col 59) |
| 45 | **g50** | **g60** | brown | J9 pin 7 STEP (col 50) -> J11 pin 3 (col 60) |
| 46 | **g51** | **g61** | brown | J9 pin 8 DIR (col 51) -> J11 pin 4 (col 61) |
| 47 | **g52** | **g62** | brown | J9 pin 9 EN (col 52) -> J11 pin 5 (col 62) |
| 48 | **h49** | **a60** | pink | J9 pin 6 SYNC (bottom col 49) up to R23 (top col 60) |

## Nets as built (what each strip carries)

| net | pins on the board |
|---|---|
| +3V3 | J11.2, J9.10, JP3.2, R20.1 |
| AUDIO_L | C10.2, J2.1, R14.1 |
| AUDIO_R | J12.1, R23.2, R24.1 |
| CE | J10.6, JP3.1, R19.1 |
| DIR | J11.4, J9.8, R22.1 |
| EN | J11.5, J9.9, R20.2 |
| GND | C11.2, C12.2, C13.2, C14.2, C15.2, C16.2, C17.2, C18.2, C19.2, C20.2, C3.2, C5.2, C6.2, C7.2, J1.2, J10.1, J11.1, J12.2, J2.2, J3.2, J4.2, J5.2, J6.2, J7.2, J8.2, J9.1, R1.2, R10.2, R14.2, R19.2, R21.2, R22.2, R24.2, U1.4, U2.4 |
| IF | C1.1, C20.1, J1.1, R1.1 |
| LD | J10.5, J9.5 |
| LE | J9.4, R18.1 |
| LE_O | J10.4, R18.2 |
| MOSI | J9.3, R17.1 |
| MOSI_O | J10.3, R17.2 |
| SCK | J9.2, R16.1 |
| SCK_O | J10.2, R16.2 |
| STEP | J11.3, J9.7, R21.1 |
| SYNC | J9.6, R23.1 |
| V5 | C12.1, FB1.1, FB2.1, FB3.1, J5.1 |
| V5_ADF | C14.1, C15.1, FB1.2, J6.1 |
| V5_LNA | C18.1, C19.1, FB3.2, J8.1 |
| V5_PA | C16.1, C17.1, FB2.2, J7.1 |
| VANA | C13.1, C3.1, C7.1, R15.2, R9.1, U1.8, U2.8 |
| VPROT | C11.1, D1.K, J4.1, R15.1 |
| VREF | C6.1, C9.2, R11.2, R2.2, R4.2, R6.2, R8.2 |
| N$10 | R13.1, U2.6, U2.7 |
| N$11 | C10.1, R13.2 |
| N$14 | C5.1, R10.1, R9.2, U2.3 |
| N$15 | R11.1, U2.1, U2.2 |
| N$16 | D1.A, J3.1 |
| N$2 | C1.2, R2.1, U1.3 |
| N$4 | R3.1, R4.1, U1.2 |
| N$5 | C2.1, R3.2, U1.1 |
| N$6 | C2.2, R6.1, U1.5 |
| N$7 | R7.1, R8.1, U1.6 |
| N$8 | R12.1, R7.2, U1.7 |
| N$9 | C9.1, R12.2, U2.5 |

The generator (`layout.py` on the `dev` branch) re-runs this check and refuses to write if a net splits or shorts.

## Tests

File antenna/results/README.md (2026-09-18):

# HFSS results

Drop the Ansys HFSS output here as it is produced. Suggested contents, one file each:

| file | what |
|---|---|
| `horn.aedt` (or a `.aedtz` archive) | the project itself |
| `s11.csv` + `s11.png` | S11 vs frequency, 2.3–2.6 GHz, after the probe sweep |
| `gain-eplane.csv` / `gain-hplane.csv` + `patterns.png` | far-field cuts at 2.45 GHz |
| `probe-sweep.csv` | S11 at 2.45 GHz vs probe depth and backshort distance |
| `horn-report.pdf` (+ its `.tex`) | the LaTeX write-up: gain, beamwidths, S11, chosen probe position, and whether each passes the accept-if line in `../README.md` |

Keep the numbers next to the pictures: a screenshot without the CSV behind it
cannot be re-plotted.

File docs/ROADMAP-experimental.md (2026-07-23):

# Experimental directions — through-wall sensing & radar simulation

Two ideas on the table:

1. A through-the-wall sensing (TTWS) system, à la the military "see people
   through walls" radars, with an eye toward a consumer product.
2. Intuitive radar / antenna **simulation software**.

This doc is an honest feasibility pass and a phased plan for each. Short
version of the recommendation up front:

- **Simulation software is the one to build first.** It's legal, unencumbered,
  genuinely useful, sellable, and it compounds with everything else here
  (you design the TTWS array *in your own tool*). Start here.
- **Through-wall is real and buildable — but not the product you first
  described.** Two facts reshape it: (a) millimeter wave does *not* go through
  walls; the physics wants the opposite end of the spectrum, and (b) in the
  US, through-wall *imaging* is legally restricted to law enforcement / fire /
  rescue. The viable consumer product in this space is **sense-through-wall
  presence & vital-signs** (breathing, occupancy, fall detection), which is a
  different regulatory animal and a real market. Build that, not a covert
  "see the person" imager.

---

## Part A — Through-wall sensing: what's actually true

### A.1 Two physics corrections that change the design

**mmWave doesn't penetrate walls.** This is the big one. Higher frequency =
shorter wavelength = *finer resolution but worse penetration*. Millimeter
wave (24–81 GHz) is strongly absorbed by drywall, brick, and especially
concrete; it's the wrong tool for going *through* a wall. Through-wall
systems deliberately trade resolution for penetration and work at **low
frequencies — UHF up through L/S-band (roughly 0.5–4 GHz), as ultra-wideband
(UWB) pulses.** Military ground-penetrating and through-wall radars sit down
there for exactly this reason. So the instinct "TTWS with millimeter wave
going through walls" is self-contradictory; the honest design uses UWB in
the low-GHz range. (mmWave is fantastic for *in-room* presence and micro-
motion sensing where there's no wall in the path — different product.)

**Resolution is set by bandwidth, penetration by center frequency, and you
can't max both.** Range resolution ΔR = c/(2·B). To resolve two people 30 cm
apart you need ~500 MHz of bandwidth. To punch through a 20 cm concrete wall
you want a low center frequency. UWB (wide B at a low center) is the
compromise the whole field converged on.

Sources: [penetration vs resolution](https://linpowave.com/blog/through-wall-detection-mmwave-radar),
[UWB through-wall radar](https://link.springer.com/content/pdf/10.1007/978-0-387-74159-8_23.pdf).

### A.2 The regulatory wall (this is the real gate, not the tech)

In the US, the FCC regulates UWB under 47 CFR Part 15 Subpart F, and it draws
a hard line around **"imaging systems"**:

- **Through-wall *imaging* systems** (§ 15.511) may only be operated by "law
  enforcement, emergency rescue or firefighting organizations that are under
  the authority of a local or state government," whose operators are eligible
  for licensing under Part 90, and use requires **coordination with the FCC**
  before operation.
  ([47 CFR 15.511](https://www.ecfr.gov/current/title-47/chapter-I/subchapter-A/part-15/subpart-F))
- **GPR / wall-imaging systems** (§ 15.509) are likewise limited to "law
  enforcement, fire fighting, emergency rescue, scientific research,
  commercial mining, or construction."
  ([47 CFR 15.509](https://www.ecfr.gov/current/title-47/chapter-I/subchapter-A/part-15/subpart-F/section-15.509))

Translation: **a general-consumer "see people through the wall" imager is not
a legal US product**, regardless of how cheaply you can build it. This isn't
a moral footnote — it's the business reality that kills that specific product.
There's also a constitutional overlay (*Kyllo v. United States*, 2001: using
sense-enhancing tech to see inside a home is a Fourth Amendment "search"),
and the well-documented controversy over police "Range-R" devices used
without warrants. And higher-capability radar can attract export-control
(EAR/ITAR) attention.

**None of this blocks the legal path** — it just tells you which product to
build. Presence/vital-sign sensors that don't form an *image* of the interior
are regulated far more permissively (ordinary UWB sensing, Part 15), which is
exactly why commercial UWB presence sensors already ship.

### A.3 The capability tiers (so "consumer product" means something concrete)

| Tier | What it does | Freq / hardware | Cost | Legal as consumer product? |
|---|---|---|---|---|
| **0. In-room presence** | detects people & micro-motion in the same room | 60 GHz mmWave (TI IWR6843, Infineon BGT60) | $10–30 chip | ✅ yes — already common in smart-home |
| **1. Sense-*through*-wall presence/vitals** | "someone is in the next room, breathing rate, fell down" — no image | UWB 1–10 GHz single-channel (Novelda X4/X7, TI IWR + processing) | $50–300 | ✅ yes (not "imaging") — **this is the consumer product** |
| **2. Through-wall *localization*** | 1–2 blobs behind a wall, position only | UWB with a small Rx array | $500–2k, DIY-hard | ⚠️ edges toward "imaging" — regulatory gray zone |
| **3. Through-wall *imaging*** | skeletal poses / room map through concrete (the Camero Xaver / military tier) | UWB antenna array + SAR + big compute | $10k–50k+ | ❌ US: law-enforcement/fire/rescue only |

Your exciting mental image is Tier 3 (Camero-Tech Xaver, the MIT CSAIL
"RF-Pose" through-wall pose estimation research). It's real, but it's the
$10k+ export-sensitive, LE-only tier. **Tier 1 is where an actual product
lives**, and it's a good one: elder-care fall & breathing monitoring
(privacy-friendly precisely *because* it's not a camera), occupancy for HVAC/
security, sleep/vitals. That reframes "military → police → criminals" into
"eldercare → building automation → search-and-rescue," which is both the
legal market and the fundable one.

### A.4 A phased plan for the TTWS thread

- **T0 — Literature & parts (1–2 wk).** Read the UWB TTWS survey papers;
  order one UWB sensing module. Best hobbyist starting points: a **Novelda
  X4M200/X4M300** (respiration/presence dev kit, sensing built in) or a **TI
  IWR6843 / AWR1642** mmWave EVM for the in-room tier. Both have SDKs.
- **T1 — Reproduce Tier 0/1 (4–8 wk).** Get presence + breathing-rate
  detection working in one room, then aim the UWB unit through a single
  interior drywall wall and characterize what survives. Deliverable: a
  measured penetration/SNR table for your walls — this is the honest
  feasibility datum everything else hangs on.
- **T2 — Signal processing (8–12 wk).** Clutter removal (the wall reflection
  dwarfs the person — same direct-path problem as the drone radar, ~40 dB),
  background subtraction, micro-Doppler for breathing, MTI for motion. This is
  the real IP and it's all software.
- **T3 — Decide the product.** If Tier 1 vitals/fall detection is solid,
  that's the consumer path (with a clear privacy story and, if it's a medical
  claim, an FDA conversation). Localization (Tier 2) is a research demo, not a
  first product. Keep Tier 3 firmly in the "not a US consumer product" column.

**Guardrail:** design this as safety/care/rescue sensing, not covert
surveillance. That choice isn't just ethics — it's the difference between a
product you can legally sell and ship and one you can't.

---

## Part B — Radar / antenna simulation software (build this first)

This is the strong idea: legal, no export/FCC baggage, useful to *you*
immediately, and a real market gap between "toy" and "$40k HFSS license."

### B.1 What already exists (stand on these, don't reinvent)

| Layer | Mature tools to build on |
|---|---|
| EM field solver (antennas) | **openEMS** (open-source FDTD), **NEC2/necpp** (wire antennas), **Meep** (FDTD) |
| RF circuit / network | **scikit-rf** (S-parameters, matching, Smith charts) |
| Phased array / radar system | **MATLAB Phased Array Toolbox** (the paid reference), **PyEHT / pytorch-based** DSP |
| Radar signal chain | build in NumPy/SciPy — you already have the solver muscle in this repo |

The gap isn't the math — openEMS already does rigorous FDTD. The gap is
**intuitiveness**: those tools have brutal learning curves. A tool that lets
you *draw* an antenna or lay out an array and *see* the pattern update, with
sane defaults, is genuinely wanted (education, ham radio, RF prosumers,
students).

### B.2 Scope it as three separable products, not one boil-the-ocean app

1. **Radar system simulator (start here — weeks, not months).** No Maxwell's
   equations. Model the *signal chain*: waveform (pulse/FMCW/chirp) →
   propagation (range, Doppler, path loss, RCS) → antenna pattern (as a gain
   function) → receiver → range-Doppler map / detection. This is analytic and
   fast, it directly reuses this repo's Python + web-GUI stack, and it's the
   part that teaches radar intuition. **This is the natural next build in
   `radar-dev`.**
2. **Antenna pattern designer (months).** Wrap NEC2/openEMS behind a friendly
   UI: place elements, sweep geometry, live-render the far-field pattern and
   array factor. Hard part is UX + meshing, not physics (solver exists).
3. **Full-wave EM playground (long-term).** Real FDTD via openEMS/Meep for
   near-field, S-params, coupling. This is where it gets "a lot of physics and
   math," so it's last.

### B.3 Concrete first milestone (fits this repo)

A **web-based radar system simulator** reusing the `server.py` + canvas GUI
pattern you already have:

- Inputs: waveform type & bandwidth, PRF, carrier, Tx power, antenna gain/
  beamwidth, and a scene of targets (range, velocity, RCS).
- Compute (pure NumPy): radar range equation for SNR, range resolution
  c/2B, Doppler shifts, and a synthesized **range-Doppler map**.
- Output: live range-Doppler heatmap (the `dataviz` sequential ramp),
  detections vs. the noise floor, and the classic tradeoff sliders
  (bandwidth↔resolution, PRF↔unambiguous range/velocity) so the *intuition*
  is visible. An **array-factor** view for N-element spacing/steering is a
  natural second tab.
- This is buildable on the stack already in `ground_station/` and turns the
  abstract equations in `docs/feasibility.md` into something you can play
  with — genuinely the fastest path to "that's pretty cool."

### B.4 Antenna-design phase (after the system sim lands)

- Wrap **openEMS** (Python interface) for full-wave, or **necpp** for quick
  wire-antenna work.
- UI: draw/parameterize geometry → run solver in a worker → render far-field
  gain (3D lobe + 2D cuts) and VSWR/S11 via scikit-rf.
- Validate against known closed-form cases (half-wave dipole pattern,
  2-element array factor) before trusting arbitrary geometry — same
  "checkpoint" discipline as the drone setup plan.

---

## Recommended sequencing

1. **Now:** build the **radar system simulator** (Part B.3). Fast, legal,
   compounding, reuses your stack, and makes the physics tangible.
2. **Parallel, low-cost:** order one UWB sensing dev kit and run the **T1
   through-wall characterization** (Part A.4) — one measured SNR table tells
   you whether the sensing product is worth pursuing, for ~$100–300.
3. **Then:** grow the simulator toward antenna/array design (Part B.4), and
   if the UWB numbers are good, develop the **Tier-1 presence/vitals** sensor
   as the consumer product — with the care/rescue framing that keeps it legal
   and fundable.
4. **Not on the roadmap as a consumer product:** through-wall *imaging*
   (Tier 3). Fascinating, but LE/fire/rescue-only in the US. Revisit only if
   you're building explicitly for that regulated market.

The through-wall imager is the cool poster; the simulator and the Tier-1
sensor are the things you can actually build, ship, and sell.

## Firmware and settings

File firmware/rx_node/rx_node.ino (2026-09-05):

/*
 * rx_node.ino — ground sniffer node (build 3-4 of these).
 *
 * Receive-only localization sensor: sits in WiFi promiscuous (monitor)
 * mode on WIFI_CHANNEL, filters every frame whose transmitter address
 * matches DRONE_MAC, and records the hardware RSSI of each one. Every
 * REPORT_MS it sends the median RSSI + sample count to the hub node
 * over ESP-NOW (unicast on the same channel, so sniffing continues
 * uninterrupted).
 *
 * The node never transmits anything toward the drone — from the
 * drone's point of view this system is completely passive.
 *
 * Per-node config: set NODE_ID (1..N, unique) and the two MACs below.
 */

#include <WiFi.h>
#include <esp_now.h>
#include <esp_wifi.h>

// ---------------- configuration ----------------
#define NODE_ID        1        // UNIQUE per node: 1, 2, 3, 4...
#define WIFI_CHANNEL   1        // ESP-FC softAP default is channel 1, NOT 7.
                                // The espnow-rclink RX adopts the softAP channel.
                                // ALWAYS confirm with mac_scanner before flashing.

// The drone's ESP-FC softAP MAC (the AP is named "ESP-FC" and beacons at
// ~10 Hz all flight, which is free tracking with no firmware patch).
// Get it from esp-fc's CLI `wifi` command, or from mac_scanner:
static const uint8_t DRONE_MAC[6] = {0x24, 0x6F, 0x28, 0x00, 0x00, 0x00};
// MAC printed by hub_node.ino at boot:
static const uint8_t HUB_MAC[6]   = {0x24, 0x6F, 0x28, 0x00, 0x00, 0x01};

#define REPORT_MS      250      // report interval → 4 Hz position updates
#define MAX_SAMPLES    64       // ring buffer per report window
// -----------------------------------------------

typedef struct __attribute__((packed)) {
  uint8_t  node_id;
  int8_t   rssi_median;   // dBm
  uint8_t  n_samples;
  uint32_t millis_ts;
} report_t;

static volatile int8_t  samples[MAX_SAMPLES];
static volatile uint8_t sampleCount = 0;

// Minimal 802.11 MAC header: addr2 (transmitter) lives at bytes 10..15
// for management and data frames.
static void IRAM_ATTR snifferCb(void *buf, wifi_promiscuous_pkt_type_t type) {
  if (type != WIFI_PKT_MGMT && type != WIFI_PKT_DATA) return;
  const wifi_promiscuous_pkt_t *pkt = (const wifi_promiscuous_pkt_t *)buf;
  const uint8_t *addr2 = pkt->payload + 10;
  if (memcmp(addr2, DRONE_MAC, 6) != 0) return;
  if (sampleCount < MAX_SAMPLES) {
    samples[sampleCount++] = pkt->rx_ctrl.rssi;
  }
}

static int cmpInt8(const void *a, const void *b) {
  return *(const int8_t *)a - *(const int8_t *)b;
}

void setup() {
  Serial.begin(115200);
  delay(200);

  WiFi.mode(WIFI_STA);
  WiFi.disconnect();
  esp_wifi_set_channel(WIFI_CHANNEL, WIFI_SECOND_CHAN_NONE);

  if (esp_now_init() != ESP_OK) {
    Serial.println("esp_now_init failed, rebooting");
    delay(1000);
    ESP.restart();
  }
  esp_now_peer_info_t peer = {};
  memcpy(peer.peer_addr, HUB_MAC, 6);
  peer.channel = WIFI_CHANNEL;
  peer.ifidx   = WIFI_IF_STA;
  peer.encrypt = false;
  esp_now_add_peer(&peer);

  wifi_promiscuous_filter_t filter = {
    .filter_mask = WIFI_PROMIS_FILTER_MASK_MGMT | WIFI_PROMIS_FILTER_MASK_DATA
  };
  esp_wifi_set_promiscuous_filter(&filter);
  esp_wifi_set_promiscuous_rx_cb(snifferCb);
  esp_wifi_set_promiscuous(true);

  Serial.printf("rx_node %d up on channel %d, MAC %s\n",
                NODE_ID, WIFI_CHANNEL, WiFi.macAddress().c_str());
}

void loop() {
  static uint32_t lastReport = 0;
  if (millis() - lastReport < REPORT_MS) return;
  lastReport = millis();

  // Snapshot + reset the buffer with the sniffer briefly paused so the
  // ISR can't write mid-copy.
  esp_wifi_set_promiscuous(false);
  uint8_t n = sampleCount;
  int8_t local[MAX_SAMPLES];
  memcpy(local, (const void *)samples, n);
  sampleCount = 0;
  esp_wifi_set_promiscuous(true);

  if (n == 0) return;  // drone not heard this window; hub treats silence as "no fix"

  qsort(local, n, sizeof(int8_t), cmpInt8);
  report_t r = {NODE_ID, local[n / 2], n, millis()};
  esp_now_send(HUB_MAC, (const uint8_t *)&r, sizeof(r));
}

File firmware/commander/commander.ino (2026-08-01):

/*
 * commander.ino — ground-side "autopilot uplink" for the interceptor drone.
 *
 * This ESP32 is the interceptor's RADIO. It speaks the espnow-rclink
 * *transmitter* protocol (rtlopez/espnow-rclink) to the interceptor's
 * ESP-FC receiver, and it takes its stick commands from the laptop over
 * USB serial. The ground station's guidance loop (ground_station/autopilot.py)
 * computes channel values from the radar fix and streams them here; this
 * firmware relays them to the drone at a steady rate and enforces a
 * fail-safe if that stream stops.
 *
 * IMPORTANT — binding is exclusive: an espnow-rclink receiver binds to the
 * first transmitter it hears after power-up and ignores others until it is
 * power-cycled. So the interceptor must be powered with THIS commander
 * running (and the handheld TX off) so it binds here. Manual override is
 * provided *through* this link (see ARM/MODE channels + the host-side
 * gamepad path in autopilot.py), not by a second transmitter.
 *
 * Serial protocol (115200 baud), one line per update from the host:
 *     C,<ch0>,<ch1>,...,<ch7>\n      set channels (microseconds, 880-2120)
 * e.g.  C,1500,1500,1100,1500,1000,1000,1000,1000
 * Order is whatever your ESP-FC rc map expects (default AETR):
 *     ch0 roll  ch1 pitch  ch2 throttle  ch3 yaw  ch4..7 AUX (arm/mode/...)
 * The host must send at >= 20 Hz; if no valid line arrives for
 * FAILSAFE_MS, the commander drives the fail-safe frame (throttle low,
 * sticks centered, ARM low) so the drone disarms/levels instead of
 * flying blind.
 *
 * Requires the espnow-rclink library installed in the Arduino/PlatformIO
 * project (it pulls in the WifiEspNow dependency).
 */

#include <Arduino.h>
#include <EspNowRcLink/Transmitter.h>

// ---------------- configuration ----------------
#define NUM_CH        8
#define SEND_MS       20        // 50 Hz uplink (matches the tx example)
#define FAILSAFE_MS   200       // no host data for this long -> fail-safe
#define CH_MIN        880
#define CH_MID        1500
#define CH_MAX        2120
// Fail-safe frame: centered sticks, throttle to minimum, all AUX low
// (ch2 = throttle in AETR; adjust if your map differs).
static const unsigned int FAILSAFE[NUM_CH] =
    {CH_MID, CH_MID, CH_MIN, CH_MID, CH_MIN, CH_MIN, CH_MIN, CH_MIN};
// -----------------------------------------------

EspNowRcLink::Transmitter tx;

static unsigned int channels[NUM_CH];
static uint32_t lastHostMs = 0;
static uint32_t lastSendMs = 0;
static uint32_t lastStateMs = 0;
static char line[96];
static uint8_t linePos = 0;

static void applyFailsafe() {
  for (int i = 0; i < NUM_CH; i++) channels[i] = FAILSAFE[i];
}

// Parse "C,1500,1500,..." into channels[]. Returns true on a full valid frame.
static bool parseLine(char *s) {
  if (s[0] != 'C' || s[1] != ',') return false;
  char *p = s + 2;
  for (int i = 0; i < NUM_CH; i++) {
    char *end;
    long v = strtol(p, &end, 10);
    if (end == p) return false;               // no number parsed
    if (v < CH_MIN) v = CH_MIN;
    if (v > CH_MAX) v = CH_MAX;
    channels[i] = (unsigned int)v;
    p = end;
    if (*p == ',') p++;
  }
  return true;
}

static void readHost() {
  while (Serial.available()) {
    char c = (char)Serial.read();
    if (c == '\n' || c == '\r') {
      line[linePos] = '\0';
      if (linePos > 0 && parseLine(line))
        lastHostMs = millis();
      linePos = 0;
    } else if (linePos < sizeof(line) - 1) {
      line[linePos++] = c;
    }
  }
}

void setup() {
  Serial.begin(115200);
  delay(200);
  applyFailsafe();
  // begin(true): bring up the hidden softAP the receiver pairs against.
  if (!tx.begin(true)) {
    Serial.println("# commander: tx.begin failed");
  }
  Serial.println("# commander up. stream 'C,ch0,...,ch7' at >=20Hz.");
}

void loop() {
  tx.update();                 // service the ESP-NOW link every loop
  readHost();

  uint32_t now = millis();
  if (now - lastHostMs > FAILSAFE_MS) applyFailsafe();

  if (now - lastSendMs >= SEND_MS) {
    lastSendMs = now;
    for (size_t c = 0; c < NUM_CH; c++)
      tx.setChannel(c, channels[c]);
    tx.commit();               // queue this channel frame for transmission
  }

  if (now - lastStateMs >= 500) {       // status heartbeat to the host
    lastStateMs = now;
    bool paired = (tx.update() == EspNowRcLink::Transmitter::TRANSMITTING);
    bool fs = (now - lastHostMs > FAILSAFE_MS);
    Serial.printf("# state=%s failsafe=%d\n",
                  paired ? "LINKED" : "DISCOVERING", fs ? 1 : 0);
  }
}

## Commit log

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2026-08-01 Add interception guidance laws and end-to-end pursuit simulation
    guidance.py: track (position+velocity control with target-velocity
    feed-forward, the mocap-lab law), pure_pursuit, and true proportional
    navigation; plus world-accel -> quad attitude -> espnow-rclink RC channel
    mapping for the ground station to fly the interceptor.
    pursuit_sim.py: closes the full loop in software reusing the real
    locate.py solver and RSSI noise model -- target path -> simulated node
    RSSI -> multilateration of BOTH drones -> guidance on the noisy/delayed
    fix -> lean-limited, lagged interceptor dynamics. Monte-Carlo intercept
    rate, envelope sweep, and trajectory plotting.
    Empirically validated: with a clean sen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
2026-08-01 Add live two-drone pursuit demo to the radar console
    Sim-mode 'Pursuit demo' spawns an interceptor driven by guidance.track
    against noisy radar estimates of both drones; the GUI renders the
    interceptor blip, its trail, the intercept line, live range, and a
    PURSUIT HUD. Makes the end-goal (one drone flying to another located by
    the passive radar) tangible in the console. Verified headlessly
    (interceptor closes to ~1 m, zero console errors).
2026-08-01 Add two-drone interception: commander firmware, host autopilot, architecture doc
    Completes the end goal (one drone flies to another located by the radar).
    Architecture verified against esp-fc @master and espnow-rclink @main via a
    research workflow, and the guidance validated empirically in pursuit_sim.
    - docs/interception.md: full architecture + build plan. Ground radar tracks
    both drones; the laptop is the autopilot (esp-fc is a rate/ANGLE controller
    with experimental baro ALTHOLD and NO nav); commander ESP32 is the drone's
    espnow-rclink radio (exclusive binding -> power on first, override in-path).
    Heading via AHRS downlink + calibration dance. Honest envelope: reliably
    loiters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
    [commander.ino]
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2026-08-14 Add 3D observability analysis and full 3D digital twin
    Answers whether the radar can sense 3D, with measurement rather than
    assertion, and adds a digital twin to test the end-to-end goal.
    geometry.py: dilution-of-precision / observability analysis for node
    layouts. Reports 1-sigma position error in metres (weighted by the RSSI
    range-sigma model) plus a coplanarity warning. Key findings: the current
    3-node layout gives sigma_h 2.11 m but sigma_v 9.8 m at 1.5 m altitude;
    a 4th node at the SAME height makes altitude worse (11.1 m) because the
    problem is coplanarity, not node count; one node on a 5 m mast takes
    sigma_v to 1.5 m. Coplanar anchors also leave a mirror ambiguity -
    solving from diff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
2026-09-05 Add MIT coffee-can FMCW radar build plan, simulator and custom antenna
    Pivot from passive RSSI localization to an ACTIVE FMCW radar (MIT
    RES.LL-003 architecture), which measures true range and velocity from
    reflections off a non-cooperative target - the thing the passive
    approach fundamentally could not do.
    docs/mit-radar.md: complete build plan with parts list, phased build
    with checkpoints, simulation workflow, legal notes and integration with
    the existing tracker.
    Two findings that change the build:
    - A 2.4 GHz radar jams a 2.4 GHz ESP-NOW control link: +13 dBm/9 dBi
    puts ~-38 dBm into the drone at 10 m, 12-22 dB above the wanted
    signal. Fix: move the drone to a 915 MHz ELRS link (e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
2026-09-05 Re-target to ESP-FLY, add gated tracking filter, horn designer, mmWave path
    Re-targets the repo from the ESP-BLAST (WROOM-32) to the ESP-FLY (XIAO
    ESP32-S3) and corrects two assumptions that were wrong in the old docs.
    docs/espfly.md — the S3 mirror of espblast.md:
    - esp-fc's "ESP-FC" softAP beacons at ~10 Hz for the whole flight
    (Wireless.cpp:9-25), so a trackable beacon is free with no firmware
    patch; the espnow-rclink keepalive is only 1 Hz (Protocol.h) so the AP
    beacons are what you actually track.
    - ELRS is untrackable: with an external receiver esp-fc never brings WiFi
    up, and LoRa cannot be decoded by an ESP32 sniffer. Passive tracking
    REQUIRES the ESP-NOW link. Noted exp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
    [rx_node.ino]
2026-09-05 Scope to active radar only: scanning design, radar twin, detection chain
    Project narrows to the MIT coffee-can FMCW radar with a custom horn
    antenna. Passive/beacon tracking is archived (README keeps it collapsed
    for reference; the console, geometry tools, tracker and guidance code are
    still used).
    Surfaces a first-order gap in the build plan: ONE TX HORN PLUS ONE RX
    HORN MEASURES RANGE AND VELOCITY, NOT POSITION. A target 8 m dead ahead
    and one 8 m at 30 degrees off-axis give the identical beat tone.
    docs/scanning.md + ground_station/scan_design.py size the three ways out:
    - interferometry is unusable with horns: two horns cannot sit closer than
    one aperture (264 mm = 2.15 lambda), so t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
2026-09-06 radar_acquire: fix stage-1 (range-only) path after the timing-tuple change
    segment_chirps returns (t_up, pri); the range-only branch still unpacked a
    scalar and crashed. Output now also reports pri_ms. The self-test skips the
    azimuth check in --st-range-only mode, where there is no azimuth.
2026-09-06 Fly the ESP-FLY by phone: WiFi AP on channel 1, radar sweeps 2440-2483.5 MHz above it
    The phone link is the ESP32-S3's own 2.4 GHz AP, so instead of leaving the
    band the radar leaves the channel: AP on channel 1, sweep 2440-2483.5 MHz
    (43.5 MHz, 3.45 m range cell, drone SNR unchanged at 71 dB, ~20 dB
    signal-to-interference at the drone's receiver from adjacent-channel
    rejection). Self-test passes at the narrowed sweep.
    - radar_ctl: SET f0_mhz / SET bw_mhz, validated to stay inside ISM
    - radar_acquire: --f0-mhz/--bw-mhz, and takes the edges from radar_ctl's
    status when --ctl is used
    - docs/drone-software.md: ESP-Drone CONFIG_WIFI_CHANNEL=1, the app, the
    ping-with-radar-sweeping link test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
2026-09-06 Receiver-side interference: drone AP power down, band-pass before the LNA, operator behind horns
    The wideband horn and 50-4000 MHz SPF5189Z take everything in the room;
    the drone's own AP at +20 dBm in the beam reaches the mixer at -9 dBm,
    ~8 dB from compression with WiFi peaks. Documented budget and three
    mitigations (AP to +8 dBm in firmware, 2400-2500 MHz BPF at the LNA
    input, operator behind the horns) plus a reverse-direction bring-up
    test; BOM row 7b; prompt pack updated.
2026-09-06 Apply corrections from the external carrier-PCB review; boot the radar silent
    Four numerical errors found by the reviewed package are fixed: beat at 10 m
    (453 Hz at 43.5 MHz, not 401 -- that figure was from a 38.5 MHz sweep), scan
    revisit (9 x 64 x 7.4 ms = 4.3 s, not 1.5 s), the stepped-sweep slope
    (df = B/N so slope is exactly B/T_up; was B/(N-1), a 1.6 % range error),
    and the band top (sweep now ends at 2480 MHz, 3.5 MHz emission margin,
    enforced in firmware). Coexistence sweep is 2440-2480 (40 MHz, 3.75 m
    cell, 417 Hz at 10 m); full band 2400-2480.
    radar_ctl: boots with the PLL locked and the RF output OFF; SWEEP 0 disables
    RF, RFOFF added, CW limited to the ISM band; status reports "rf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
2026-09-07 Add per-block SPICE netlists and Multisim test cards with ngspice reference results
    hardware/spice: video amplifier (AC/transient/real-radar-input), buffered
    reference, 12 V input + reverse test, sync divider with AC-coupled sound
    card, IF termination + RF stop, and a frequency-scaled FMCW model
    (chirp x delayed chirp -> 417 Hz beat) that Multisim can run. README gives
    Multisim parts, values, stimuli and the readings each block must produce.
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2026-09-07 Docs cleanup: overview + implement + test only; everything else archived
    README is now the project overview with an ordered implement list and a
    test entry point. docs/ keeps the four build guides plus a new testing.md
    that collects every test in run order (DSP self-test, breadboard blocks in
    ngspice/Multisim, horn VNA tests, RF-chain leakage tone, walking-person
    test, phone-link ping test, tracking against floor marks). All analyses,
    history, the passive-RF system, the 915 MHz fallback and external reviews
    move to docs/archive/ with an index; links updated and checked.
2026-09-07 Align everything with the phone-flown plan and the kit's official setup
    Drone guides now follow the ESP-FLY official procedure (ESP-IDF 5.0.7,
    idf.py flash monitor, "Ready to Fly", ESP-Drone app, password 12345678,
    power-on calibration on a flat surface) with exactly two menuconfig
    deviations, using the verified option names: ESPDrone Config -> Wi-Fi/
    ESP-Now Channel = 1 (CONFIG_WIFI_CHANNEL, default 6) and Component config
    -> PHY -> Max WiFi TX power = 10 dBm (CONFIG_ESP_PHY_MAX_WIFI_TX_POWER,
    its minimum). Interference numbers updated for 10 dBm (18 dB margin).
    The prebuilt channel-6 binary is called out as unusable. Radio-controller
    receiver is "not fitted", not "unsoldered". Sweep wordin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
    [commander.ino, drone_beacon.ino, hub_node.ino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]
2026-09-07 3-D bench model: every BOM row as an object, breadboard populated component by component
    hardware/3d/radar-bench.html (Three.js): plywood bench with the RF chain in
    MIT order, the horns (copper, feeds, probes), turntable + NEMA-17 + A4988,
    the 830-point breadboard with all 50-odd components placed from the
    schematic (resistors with correct colour bands), ESP32, LM2596, terminal
    block, 12 V supply, UCA202, laptop, stage-3 second receive chain and
    UMC404HD, the ESP-FLY and the phone in the room. BOM panel flies the camera
    to any row; hover/click picking; stage and view toggles; beam cone in the
    room view. Screenshots included.
2026-09-08 Hole-level breadboard layout, verified against the netlist
    hardware/breadboard/layout.py places every part and jumper on the 830-point
    board by hole (b14, TR-@12) and checks it: no hole reused, every part within
    lead reach, and a union-find pass proving each schematic net from
    radar_breadboard_nets.json is one connected group with no shorts and the
    rails carrying what they claim. Outputs WIRING.md (lead -> hole table,
    numbered wire list, nets as built), breadboard.svg/.png, layout.json.
    gen_page.py builds breadboard.html: hover or click a part, wire, net or hole
    to highlight everything it touches, with a build checklist.
    Linked from README, docs/radar-hardware.md and the 3-D bench README.
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2026-09-09 Multisim: netlists that open directly, and clearer instructions
    hardware/spice/multisim/import/ holds six flat SPICE netlists written for
    Multisim's File > Open > SPICE netlist (*.cir) route: no .control blocks,
    no B-sources, no .include, each self-contained with the op-amp macro
    inlined. The ngspice decks in hardware/spice/ were never importable and
    the README now says so instead of leaving it to be discovered.
    Each import file was run in ngspice and reproduces its test-card numbers:
    video amp 54.5 dB at 1 kHz and 0.27 Vpk out, VREF 5.58 V, VPROT 11.68 V
    and VANA 11.58 V, -0.11 mV reversed, sync 283 mV with a -100 mV retrace
    pulse, IF input -6.7 dB at 417 Hz and -57.7 dB at 2.44 GHz.
    READ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
2026-09-09 KiCad: a flow sheet showing how the five test blocks connect
    radar_flow.kicad_sch (gen_flow.py) puts blocks 1-5 back together. The
    Multisim sheet draws them isolated because that is how you bench them;
    this one answers what that sheet cannot: block 5 or the mixer feeds the
    IF into block 1, block 3 feeds VANA to blocks 1 and 2, block 2 feeds
    VREF to six points inside block 1, and blocks 1 and 4 land on the sound
    card's two channels. Every connection carries its level, from +5 dBm out
    of the PLL to 19 mV pk at the sound card. Passes the same connectivity
    check as the other sheets: no dangling ends, no single-pin nets.
    kicad_lib.py: multi-line text broke the KiCad writer, which emitted raw
    new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
    [radar_breadboard.kicad_sch, radar_flow.kicad_sch, radar_multisim.kicad_sch]
2026-09-09 docs: signal-chain.md, what the signal is at every point
    Six figures, all generated by docs/figures/make_figures.py from the same
    SynthSource, segment_chirps, range_doppler and cfar_detect that run on
    live audio. Nothing is drawn by hand.
    Traces the data from the 64-step frequency staircase leaving the antenna,
    through the two recorded audio channels, the sync-edge segmentation into a
    64 x 292 cube, the range FFT, the Doppler FFT that actually separates the
    drone from the leakage, CFAR, and the beam-scan centroid, down to the
    100-byte fix. Includes the size of the data at each stage: 92 KB of audio
    per block becomes a 146 KB cube, a 73 KB range-Doppler map, and one fix.
    It also documents a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
2026-09-09 Measure the scan-time budget: dwell beats beams, and both lose to a moving target
    Tested the servo idea properly. Finer beam steps do help: 9 -> 23 beams
    takes worst azimuth error from 2.7 to 2.0 deg. But for the same ~10 s of
    scan time, staying at 9 beams and dwelling 2.5x longer gives 0.2 deg, an
    order of magnitude better. 160 chirps at 40 MHz lands exactly where 64
    chirps at 80 MHz already was, so integration buys back precisely what the
    halved bandwidth cost. docs/figures/scan_budget.py runs the real pipeline
    over three noise seeds and writes the numbers; figure 7 plots them.
    This corrects the diagnosis committed earlier. The error is variance, not
    bias: tightening the centroid's groupi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
2026-09-09 Azimuth from two receivers: measured, costed, and retargeted from elevation
    Scanning cannot give bearing on a moving drone at any step size or dwell.
    Two receivers and the phase difference between them can, inside a single
    0.47 s dwell. docs/figures/interferometer.py measures it with the project's
    own signal generator and processing, three noise seeds per point:
    scanning, 9 beams x 64 4.3 s 1.5 deg rms, 2.7 deg worst
    two receivers, 1 dwell 0.47 s 0.09 deg rms, 0.14 deg worst
    That is 18x inside the 2.5 deg budget and 9x faster. It holds until the
    echo weakens by 25 dB, past 40 m equivalent range, and the cliff after
    that is CFAR losing the target, not the phase measurement.
    Ca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
2026-09-09 BOM: cost the full azimuth build, and fix what the totals were missing
    Parts only ~657, everything delivered ~815. Corrections found while
    totalling it:
    - Section F claimed the second video-amp channel was free. It is not:
    row 15's two TL072 are fully used by U1A/U1B/U2B/U2A, so a second
    channel needs two more packages, a second passives set and a second
    breadboard. Added at 18.
    - The second receive chain adds four coax runs with no jumpers budgeted.
    Added two 3-packs at 18, with a note that buying them together is also
    how the two chains get phase-matched cables.
    - New section G for test gear the test plan requires but never listed: a
    NanoVNA at 65, which is the only way to do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
2026-09-09 Two sub-500 builds, and fix a test-gear error that would have wasted money
    Budget builds added to the BOM:
    A switched single receive chain, ~346 delivered
    B simultaneous two channels, ~468 delivered
    Both get there the same way: print the horns instead of cutting copper
    sheet, drop the turntable, borrow the VNA, and substitute a ~25 SMA mixer
    module for the 73 Mini-Circuits part. Build A additionally replaces the
    whole second receive chain and the 4-input interface with one RF switch.
    The turntable is genuinely optional now. It was mandatory when azimuth
    came from scanning; with two receivers the interferometer covers the full
    +/-17 deg beam from a fixed mount, so it only buys wid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
2026-09-09 Implement azimuth: two-receiver interferometry, end to end, with tests
    The docs described this and called it 'not written yet'. It is written now.
    ground_station/interferometer.py is the engine: geometry, the phase-to-
    bearing measurement at a range-Doppler cell, calibration with save/load,
    switched-mode parity and the motion correction, plus the refusal logic.
    fmcw_sim.range_doppler grows complex_out=True, because the bearing lives
    in the phase and the function only ever returned dB.
    radar_acquire.py grows --interferometer and --switched. The audio sources
    are multi-channel (beat A, beat B, sync). SynthSource generates the second
    receiver with the true interferometric phase and can inject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
2026-09-09 Purge the last of the scanning-azimuth story from the code
    The docs were overhauled but the code still taught the obsolete method as
    current in its docstrings, which is where someone reading the source would
    learn it. Fixed everywhere:
    - radar_twin.py's header called it 'the SCANNING can radar' and listed beam
    centroiding as the azimuth step. It now states plainly that centroid() is
    not how bearing is measured any more and cannot be, with the number, and
    points at interferometer.py. The code stays because it still models a
    hovering target and the beam-gain and CFAR pieces are shared.
    - server.py claimed the covariance is polar because azimuth comes from the
    beam centroid, 'tight i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
2026-09-09 3-D model: real pinouts, hole-level breadboard, and stage 3 as the azimuth interferometer
    The bench model now shows wiring you can actually check against the build
    sheet instead of indicative cables.
    Breadboard: every part sits in the holes hardware/breadboard/WIRING.md gives
    it, and all 48 jumper wires are drawn between their stated holes in their
    stated colours. Rails are TR+ V5 / TR- GND / BR+ VANA / BR- GND. Parts are
    placed by their two lead holes, so a part that spans four columns looks like
    it does on the board.
    Modules carry the pinouts from MODULES.md, and the harness runs pin to pin:
    ESP32 D18/D23/D5/D19 to J9 SCK/MOSI/LE/LD, D25 SYNC, D26/D27/D14 to
    STEP/DIR/EN, A4988 logic to J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
2026-09-09 3-D model: verify it against the documents instead of trusting it
    verify_model.py re-derives everything the model hard-codes from the files that
    actually own it, and fails loudly when they drift apart. 198 checks:
    breadboard all 60 parts and all 48 jumpers against WIRING.md — same refs,
    same holes, same pin order, same wire colours
    connectors each J-header pin's net against the "Nets as built" table,
    accepting either the netlist name or the friendly label
    pinouts ESP32 / A4988 / ADF4351 names and order against MODULES.md
    harness every pinAt() names a pin that exists on both ends
    BOM panel rows and stage totals against BOM.md,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
2026-09-09 3-D model: rebuild as the three-horn frame, two stages, turntable optional
    Follows 095e9bc, which deleted scanning azimuth and made stage 1 azimuth-ready.
    The model showed the old structure: a horn pair on two masts, the turntable as
    stage 2, and a third horn stacked below for elevation. All three were wrong.
    Now one frame, built once (radar-hardware.md 7): two uprights, a cross beam
    under each row, and all three horns rolled 90 degrees so the 193.1 mm side is
    horizontal. TX sits centred 290 mm above the receive row, which keeps the
    leakage path equal into both receivers; RX A and RX B touch at 193 mm centres,
    the interferometer baseline. Un-rolled they would sit 263.8 mm apart, past the
    20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
2026-09-09 Cost Kevin's K-band / V-band suggestion
    Researched and priced, September 2026:
    A 24 GHz, one RFbeam K-LC6 + a DAC 60 range + velocity
    B 24 GHz with azimuth, RFbeam K-MC4 250 two RX on one board
    C 60 GHz TI IWR6843ISK, point cloud out 283 3 TX / 4 RX, no DSP to write
    D 60 GHz with raw ADC, ISK + DCA1000EVM 1,271 keeps you writing the DSP
    The finding that matters is A. Everything downstream of the mixer IF is
    band-independent, so a K-LC6 replaces the entire 2.4 GHz RF chain -- PLL,
    pad, PA, splitter, mixer, LNA, band-pass and both horns -- with one 55
    part, and the video amp, reference, power, sound card, DSP,
    interferometer and tests all survi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
2026-09-09 3-D model: connectors on everything, wiring that routes, a turntable that drives
    Three things were wrong and all three are fixed.
    Wires did not land on anything. Every pin now carries a landing point AND a
    direction, so a lead leaves its connector along that connector own axis and
    arrives at the far one the same way, instead of passing near it. Leads then
    drop to a cable run 3.5 mm above the plywood and stay there, routing through
    the corridors between modules rather than flying across the board, and
    parallel leads are fanned so a ten-way loom reads as ten wires.
    Several modules had nothing to plug into. Added header sockets under the ESP32
    and A4988 - which is also what lifts their pins c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
2026-09-09 Write the goal down, and withdraw a recommendation that contradicted it
    docs/goal.md states what this project is for -- build a radar where I
    design the antenna, and get azimuth on a small drone -- and turns it into
    three tests every change is judged against: is the antenna mine, does it
    give azimuth on a drone that is FLYING, is the target a small drone.
    Written because it settles several decisions retroactively and caught a
    mistake. Scanning azimuth fails test 2 and was dropped. Elevation fails
    nothing but spends the one baseline on the wrong angle. The turntable
    measures nothing now. The interferometer passes all three.
    The mistake: higher-bands.md recommended the 60 dollar RFbeam K-LC6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
2026-09-09 3-D model: rebuild the wiring on a real routing model, and prove it geometrically
    The wires were a mess for one root cause plus two design errors.
    Root cause: the harness was built at init time, when matrixWorld is still
    identity. P() reads localToWorld, so every lead was routed as though its module
    sat at the origin. That is why cables attached to nothing and cut through parts.
    One updateMatrixWorld before building fixes all of it.
    Design error 1: cables were CatmullRomCurve3 through sparse waypoints. That
    spline overshoots at every direction change, which throws a cable past its
    corner and into whatever is behind it, and produced turns up to 180 degrees.
    Replaced with the way harness rou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
2026-09-12 Delete the scrapped passive-RSSI and interception ground station
    Seven modules in ground_station/ and the whole firmware/archive/ tree belonged
    to the project this radar replaced: a passive WiFi RSSI/FTM multilateration
    network of sniffer nodes, and an autopilot that flew an interceptor at the
    target. None of it is part of this design. There are no sniffer nodes, the drone
    carries nothing and cooperates with nothing, and docs/drone-software.md SS 10
    rules radar-driven flight out of scope as a separate project.
    Gone: locate.py, calibrate.py, geometry.py, guidance.py, autopilot.py,
    pursuit_sim.py, digital_twin.py, and the commander, drone_beacon, hub_node,
    mac_scanner, rx_node and rx_node_ftm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
    [commander.ino, drone_beacon.ino, hub_node.ino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]
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
